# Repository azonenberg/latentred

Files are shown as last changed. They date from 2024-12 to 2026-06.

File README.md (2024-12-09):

# latentred
Open hardware 48x 1000baseT + 2x 25G SFP28 Ethernet switch

Originally located in azonenberg/latentpacket but moved out to avoid monorepo bloat.

High level architecture:
* IBC (x1): 48V -> 12V intermediate bus converter. Not in this repo, see https://github.com/azonenberg/common-ibc
* Line card (x2): 24 10/100/1000 baseT ports, driven by two VSC8512 12-port PHYs
* Switch engine (x1): Kintex UltraScale+ FPGA (XCKU3P or 5P in FFVB676), STM32H735 (tentatively), packet buffer SRAM, 2x 25G SFP28 uplink

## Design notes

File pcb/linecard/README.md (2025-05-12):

# 24-port non-PoE 10/100/1000baseT QSGMII line card

Input: 12V at 1.25A max, fused at 3A to be conservative.

Expect ~15W max power consumption, less under typical operation

## ERRATA

v0.1: right LED on the RJ45 is swapped between upper and lower ports

## Power

### Needs

* VDD (1.0V): 1.15A per PHY, 2.3A total
* VDD_A (1.0V): 180 mA per PHY, 360 mA total
* VDD_AH (2.5V): 1.37A per PHY, 2.74A total
* VDD_AL (1.0V): 190 mA per PHY, 380 total
* VDD_IO (2.5V): 60 mA per PHY, 120 mA total
* VDD_VS (1.0V): 90 mA per PHY, 180 mA total
* Plus a 3.3V standby rail for the management MCU

## I2C address map

* 0x80: INA230 on 3V3
* 0x82: INA230 on 2V5
* 0x84: INA230 on 1V0
* 0x86: INA230 on 1V0_2
* 0x90: AT30TS74 near PHY 0
* 0x92: AT30ST74 near PHY 1
* 0x94: AT30TS74 near power supply

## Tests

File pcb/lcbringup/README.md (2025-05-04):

# lcbringup

This is a bringup test fixture for validating the line card (in conjunction with my kup-lulz XCKU5P FPGA board) and not intended to be part of the final LATENTED system.

Known errata: MDIO and MDC are on ball locations that are NC in the 7a35t FGG484 package. Reworked board connecting MDIO to the SPI pins on the adjacent bank and added external level shifters.

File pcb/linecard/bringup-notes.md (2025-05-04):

# Line card bringup notes

Going well so far

Port 23 does not seem to be linking up, all others appear OK. Suspecting solder joint quality but haven't investigated further yet

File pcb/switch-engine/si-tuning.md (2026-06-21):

# SI TUNING STATUS

## STUFF TO DO

* Redo BGA escapes with new meander geometry
* Enlarge BGA land cutouts from 0.45 to 0.5 mm (done)
* Check if we need cutouts on lower layers with full stack modeling

## J21 (SFP28 uplinks ARF6)

* TX0: Done
* TX1: Done

* RX0: TBD
* RX1: TBD

## J22 (spare GTY)

* GTY2_TX: step1
* GTY3_TX: TBD
* GTY2_RX: TBD
* GTY3_RX: step1

## J14 (LC0_PHY0)

* LANE0_TX: step1
* LANE1_TX: step1
* LANE2_TX: step1
* LANE0_RX: TBD
* LANE1_RX: TBD
* LANE2_RX: TBD

## J15 (LC0_PHY1)

* LANE0_TX: step1
* LANE1_TX: step1
* LANE2_TX: step1
* LANE0_RX: TBD
* LANE1_RX: TBD
* LANE2_RX: TBD

## J17 (LC1_PHY0)

## J18 (LC1_PHY1)

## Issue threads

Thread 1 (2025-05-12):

Line card rev 0.1 errata: LED1 on even/odd ports are backwards

azonenberg, 2025-05-12:
When port 0 links up in 100mbit port 1's LED turns on and vice versa. Only LED1 is affected, LED0 is correct.

azonenberg, 2025-05-12:
Software workaround added in 646b6328339c5ab8a7c6ac4c9ff34f42c673b316

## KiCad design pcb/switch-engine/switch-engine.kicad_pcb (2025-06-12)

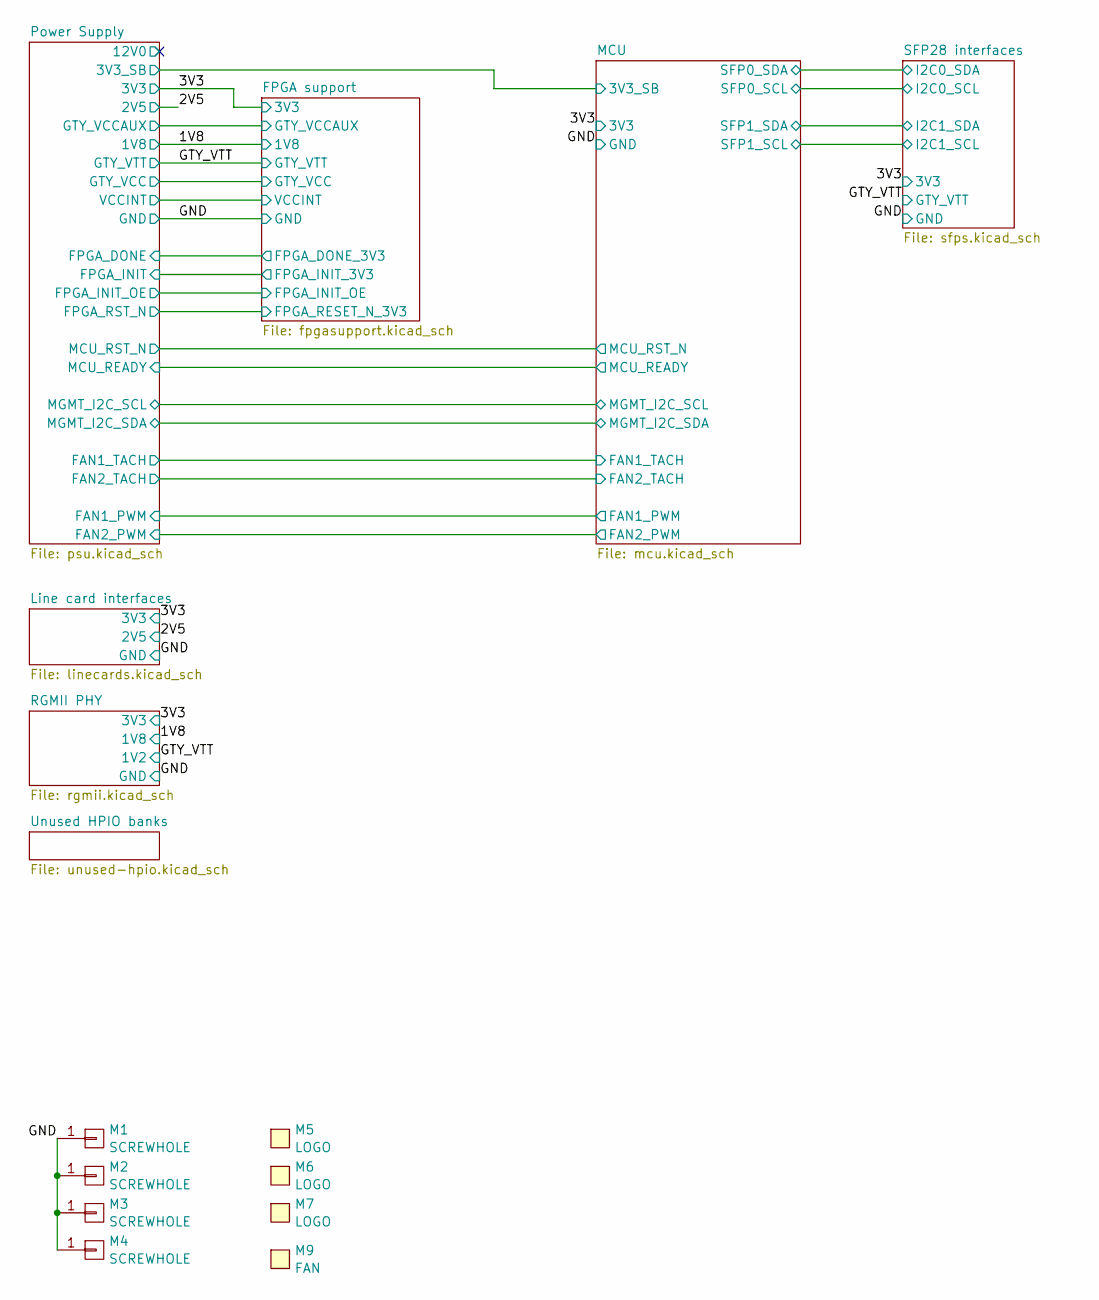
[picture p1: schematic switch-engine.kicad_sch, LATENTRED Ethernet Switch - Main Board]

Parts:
M1, M2, M3, M4: SCREWHOLE; MECHANICAL_CLEARANCEHOLE_4_40
M5: LOGO; LONGTHING-1200DPI
M6: LOGO; Logo_silk_OSHW_6x6mm
M7: LOGO; Logo_silk_WEEE_3.4x5mm
M9: FAN; FAN_DELTA_EFB0412VHD-SP05

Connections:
/GND: M1.1, M2.1, M3.1, M4.1; also elsewhere on the board

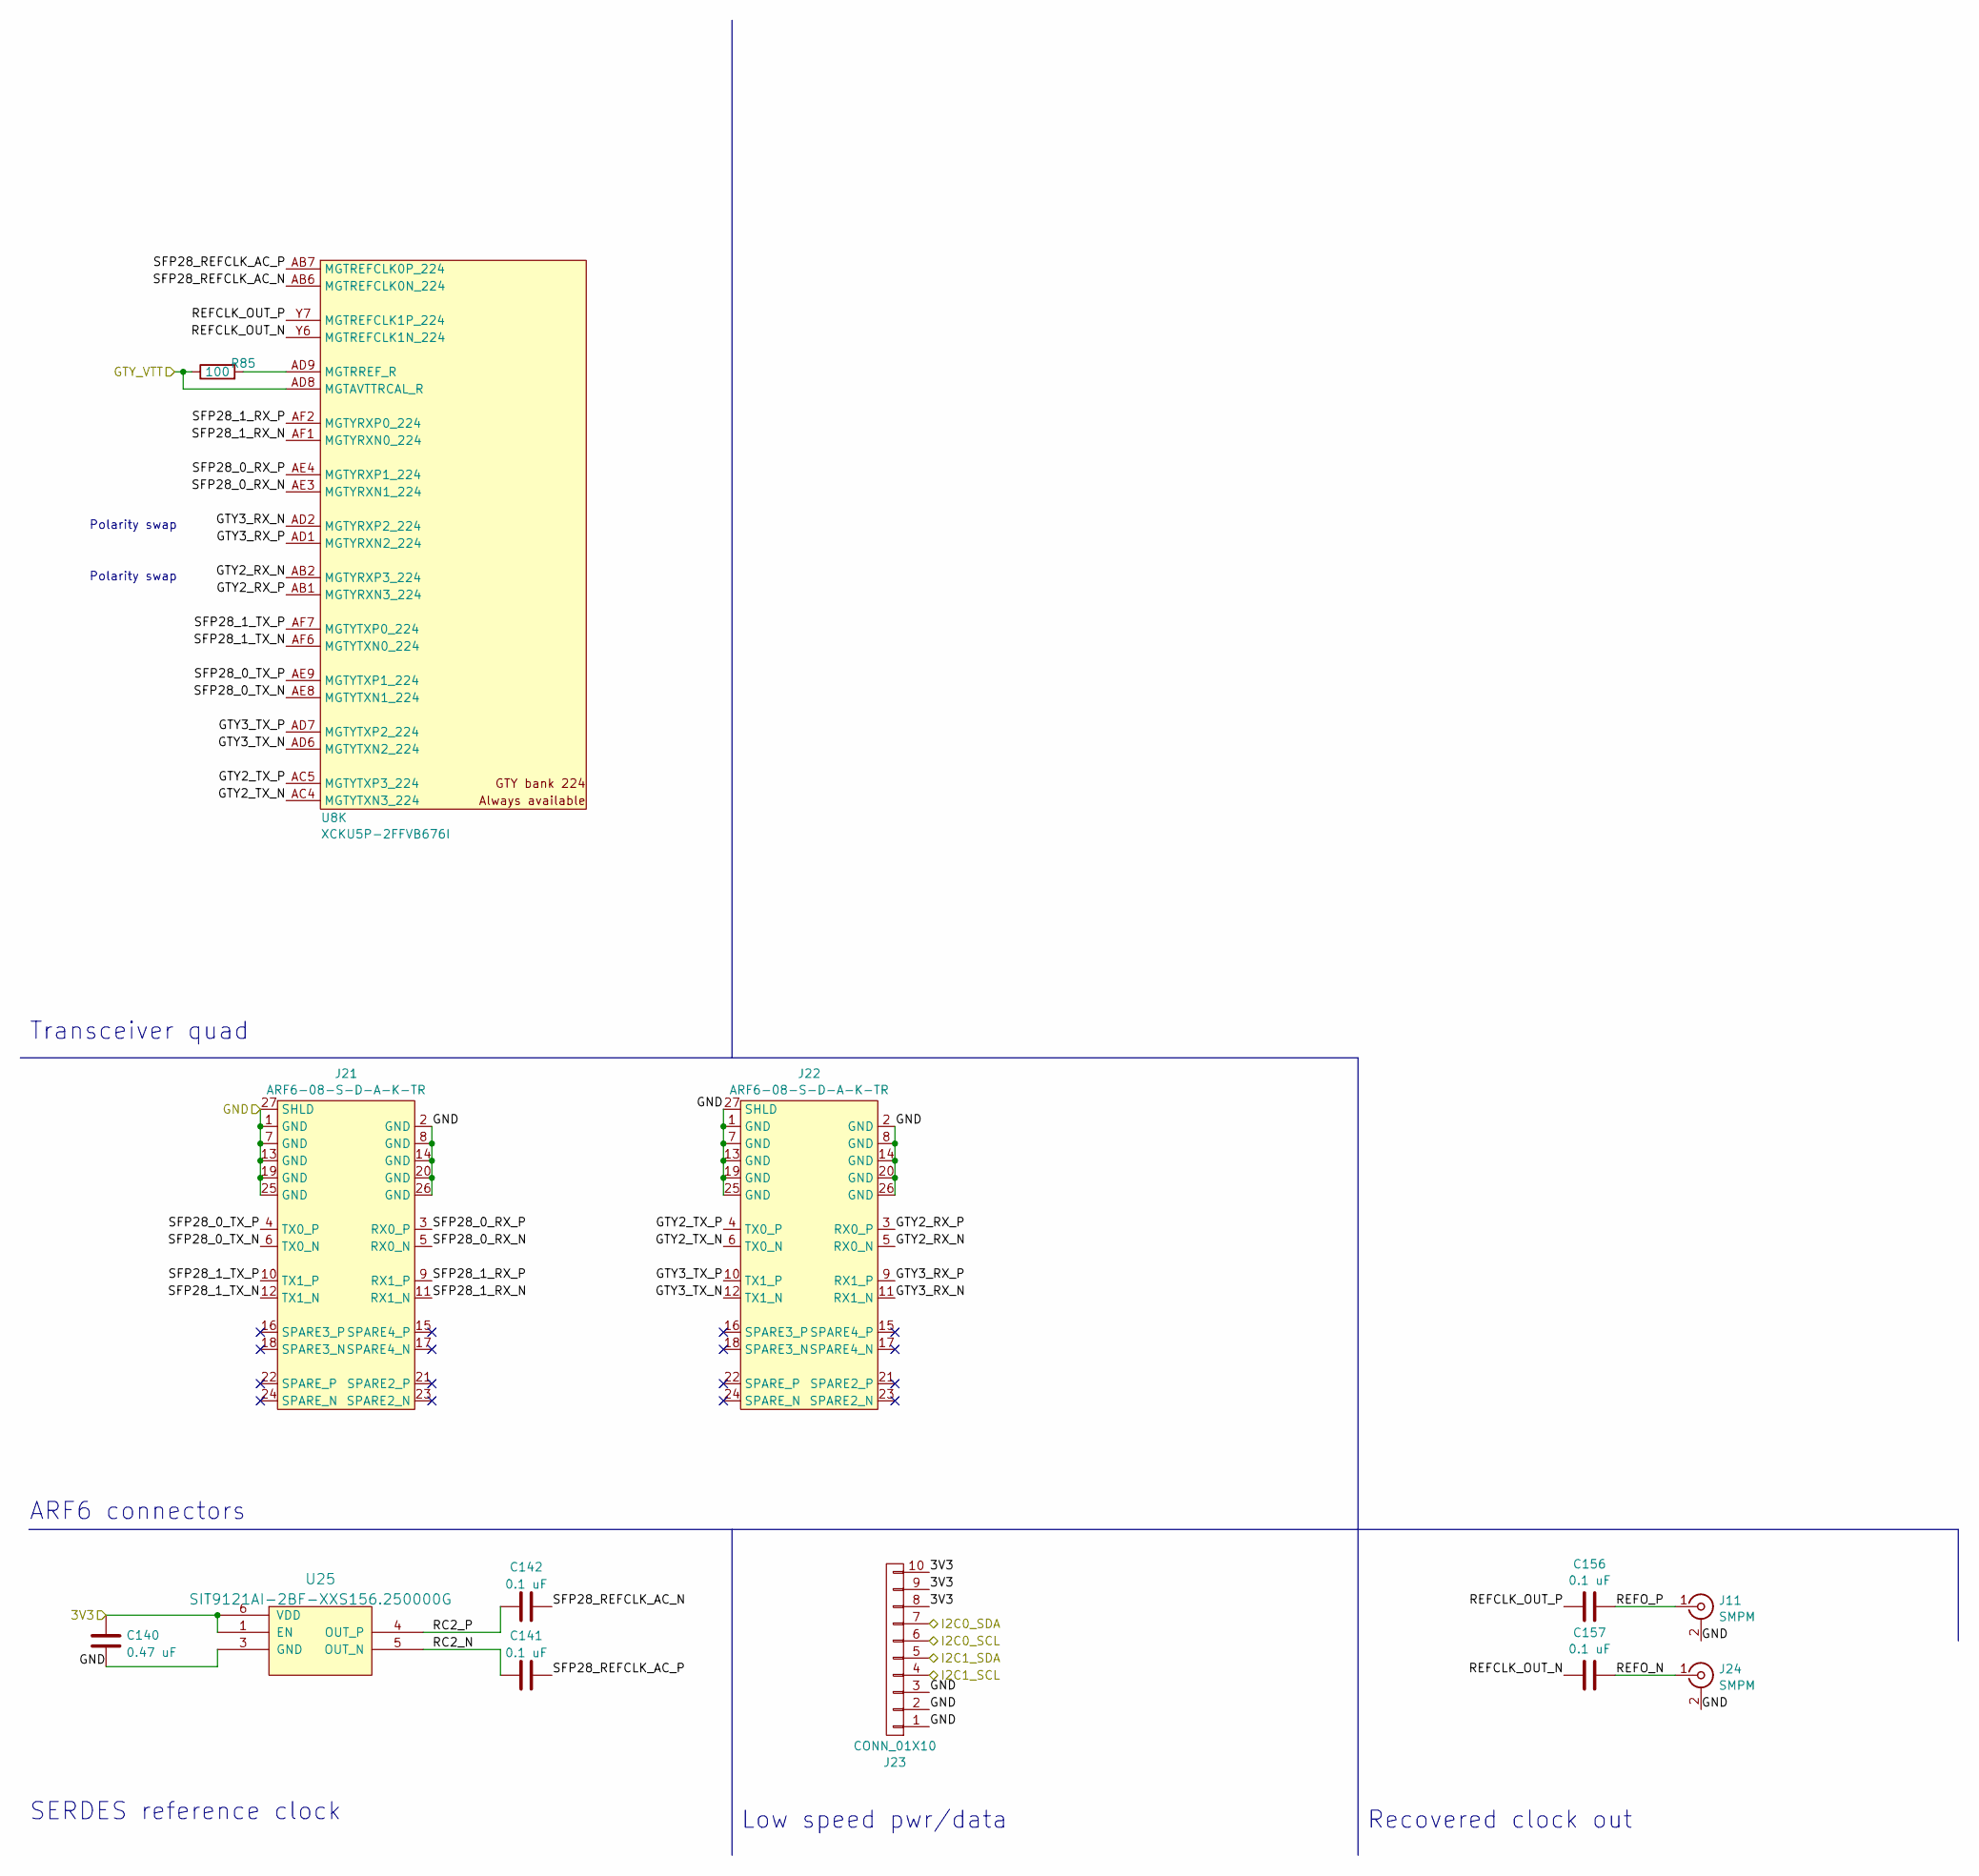
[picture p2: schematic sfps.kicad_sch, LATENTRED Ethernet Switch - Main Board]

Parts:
C140: 0.47 uF; EIA_0402_CAP_NOSILK
C141, C142, C156, C157: 0.1 uF; EIA_0402_CAP_NOSILK
J11, J24: SMPM; CONN_SMPM_AMPHENOL_C925-197J-51PT
J21, J22: ARF6-08-S-D-A-K-TR; CONN_SAMTEC_ARF6-08-S-D-A-K-TR
J23: CONN_01X10; CONN_MOLEX_PICOBLADE_10POS_0532611071
R85: 100; EIA_0402_RES_NOSILK
U8: XCKU5P-2FFVB676I; BGA_676_27x27_FULLARRAY_1MM_FFG676
U25: SIT9121AI-2BF-XXS156.250000G; OSCILLATOR_LVDS_3.2x2.5

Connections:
/3V3: C140.1, J23.8, J23.9, J23.10, U25.1 (EN), U25.6 (VDD); also elsewhere on the board
/GND: C140.2, J11.2 (Ext), J21.1 (GND), J21.2 (GND), J21.7 (GND), J21.8 (GND), J21.13 (GND), J21.14 (GND), J21.19 (GND), J21.20 (GND), J21.25 (GND), J21.26 (GND), J21.27 (SHLD), J22.1 (GND), J22.2 (GND), J22.7 (GND), J22.8 (GND), J22.13 (GND), J22.14 (GND), J22.19 (GND), J22.20 (GND), J22.25 (GND), J22.26 (GND), J22.27 (SHLD), J23.1, J23.2, J23.3, J24.2 (Ext), U25.3 (GND); also elsewhere on the board
/GTY_VTT: R85.1, U8.AD8 (MGTAVTTRCAL_R); also elsewhere on the board
/MCU/SFP0_SCL: J23.6; also elsewhere on the board
/MCU/SFP0_SDA: J23.7; also elsewhere on the board
/MCU/SFP1_SCL: J23.4; also elsewhere on the board
/MCU/SFP1_SDA: J23.5; also elsewhere on the board
/SFP28 interfaces/GTY2_RX_N: J22.5 (RX0_N), U8.AB2 (MGTYRXP3_224)
/SFP28 interfaces/GTY2_RX_P: J22.3 (RX0_P), U8.AB1 (MGTYRXN3_224)
/SFP28 interfaces/GTY2_TX_N: J22.6 (TX0_N), U8.AC4 (MGTYTXN3_224)
/SFP28 interfaces/GTY2_TX_P: J22.4 (TX0_P), U8.AC5 (MGTYTXP3_224)
/SFP28 interfaces/GTY3_RX_N: J22.11 (RX1_N), U8.AD2 (MGTYRXP2_224)
/SFP28 interfaces/GTY3_RX_P: J22.9 (RX1_P), U8.AD1 (MGTYRXN2_224)
/SFP28 interfaces/GTY3_TX_N: J22.12 (TX1_N), U8.AD6 (MGTYTXN2_224)
/SFP28 interfaces/GTY3_TX_P: J22.10 (TX1_P), U8.AD7 (MGTYTXP2_224)
/SFP28 interfaces/RC2_N: C141.1, U25.5 (OUT_N)
/SFP28 interfaces/RC2_P: C142.1, U25.4 (OUT_P)
/SFP28 interfaces/REFCLK_OUT_N: C157.1, U8.Y6 (MGTREFCLK1N_224)
/SFP28 interfaces/REFCLK_OUT_P: C156.1, U8.Y7 (MGTREFCLK1P_224)
/SFP28 interfaces/REFO_N: C157.2, J24.1 (In)
/SFP28 interfaces/REFO_P: C156.2, J11.1 (In)
/SFP28 interfaces/SFP28_0_RX_N: J21.5 (RX0_N), U8.AE3 (MGTYRXN1_224)
/SFP28 interfaces/SFP28_0_RX_P: J21.3 (RX0_P), U8.AE4 (MGTYRXP1_224)
/SFP28 interfaces/SFP28_0_TX_N: J21.6 (TX0_N), U8.AE8 (MGTYTXN1_224)
/SFP28 interfaces/SFP28_0_TX_P: J21.4 (TX0_P), U8.AE9 (MGTYTXP1_224)
/SFP28 interfaces/SFP28_1_RX_N: J21.11 (RX1_N), U8.AF1 (MGTYRXN0_224)
/SFP28 interfaces/SFP28_1_RX_P: J21.9 (RX1_P), U8.AF2 (MGTYRXP0_224)
/SFP28 interfaces/SFP28_1_TX_N: J21.12 (TX1_N), U8.AF6 (MGTYTXN0_224)
/SFP28 interfaces/SFP28_1_TX_P: J21.10 (TX1_P), U8.AF7 (MGTYTXP0_224)
/SFP28 interfaces/SFP28_REFCLK_AC_N: C142.2, U8.AB6 (MGTREFCLK0N_224)
/SFP28 interfaces/SFP28_REFCLK_AC_P: C141.2, U8.AB7 (MGTREFCLK0P_224)
unnamed: R85.2, U8.AD9 (MGTRREF_R)

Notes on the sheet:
Transceiver quad
Low speed pwr/data
Polarity swap
Recovered clock out
ARF6 connectors
SERDES reference clock

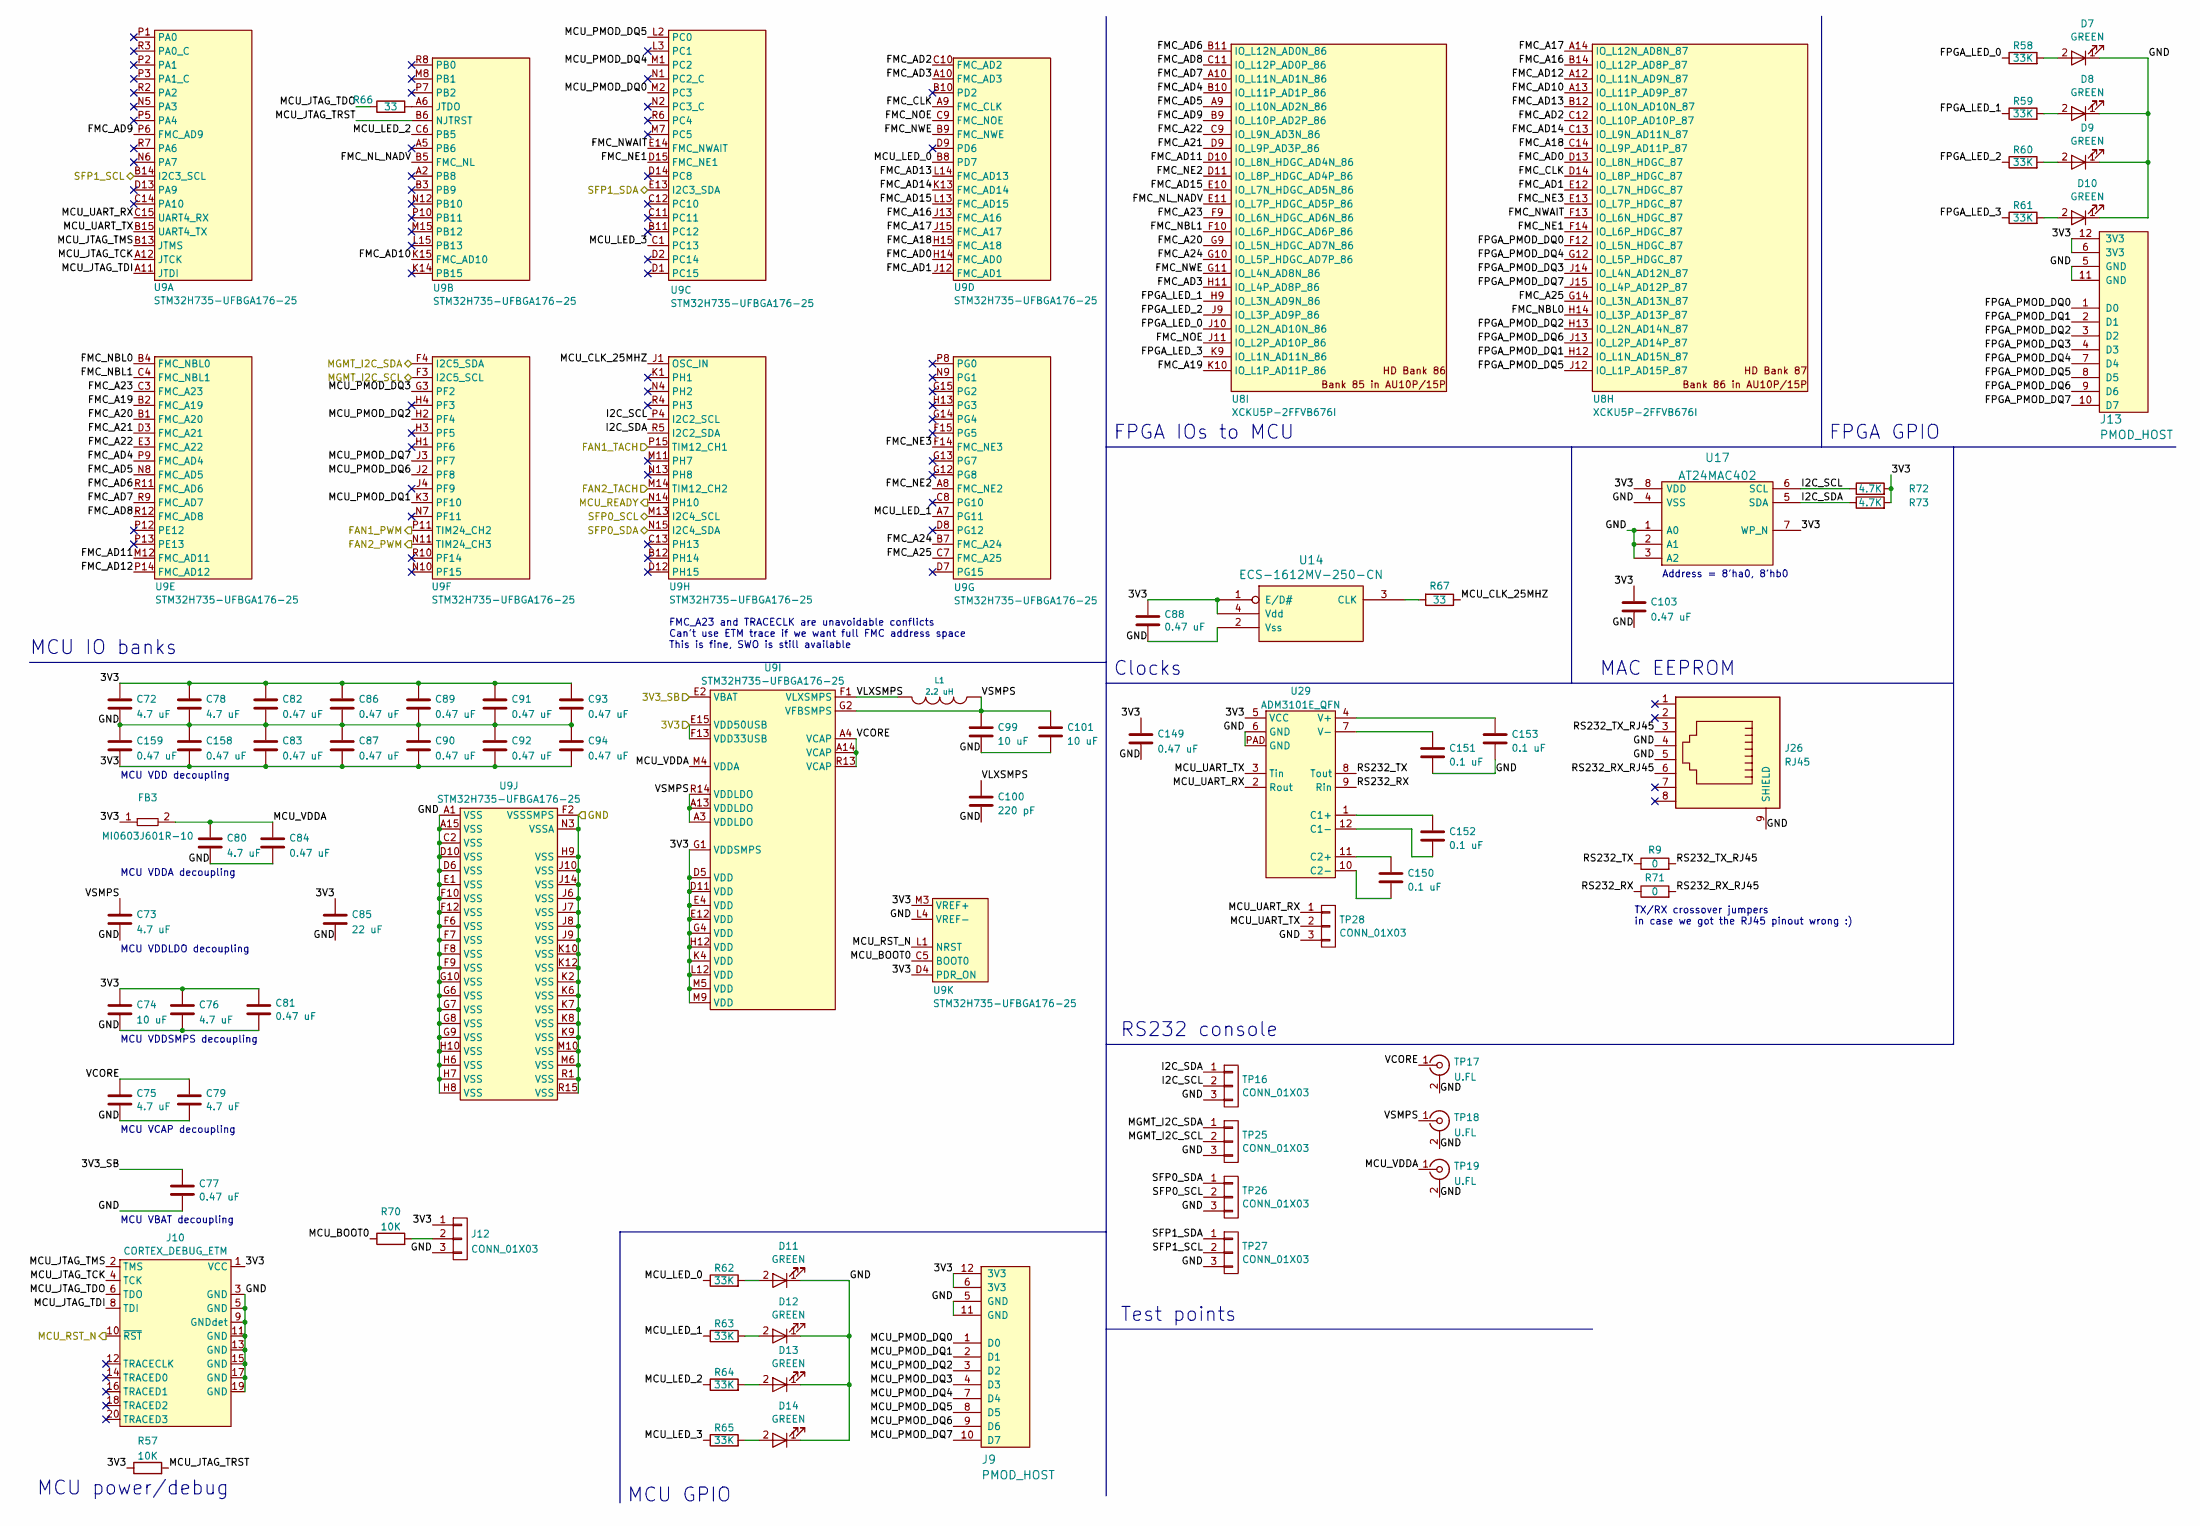
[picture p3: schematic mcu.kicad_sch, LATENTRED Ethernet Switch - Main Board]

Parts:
C72, C73, C75, C76, C78, C79, C80: 4.7 uF; EIA_0603_CAP_NOSILK
C74, C99, C101: 10 uF; EIA_0805_CAP_NOSILK
C77, C82, C83, C84, C86, C89, C90, C92, C93, C94: 0.47 uF; EIA_0201_CAP_NOSILK
C81, C87, C88, C91, C103, C149, C158, C159: 0.47 uF; EIA_0402_CAP_NOSILK
C85: 22 uF; EIA_0805_CAP_NOSILK
C100: 220 pF; EIA_0402_CAP_NOSILK
C150, C151, C152, C153: 0.1 uF; EIA_0402_CAP_NOSILK
D7, D8, D9, D10, D11, D12, D13, D14: GREEN; EIA_0402_LED
FB3: MI0603J601R-10; EIA_0603_INDUCTOR_NOSILK
J9, J13: PMOD_HOST; CONN_HEADER_2.54MM_2x6_RA_PMOD_HOST
J10: CORTEX_DEBUG_ETM; CONN_HEADER_1.27MM_2x10_SMT_SAMTEC_FTSH-110-01-L-DV-K
J12: CONN_01X03; CONN_HEADER_2.54MM_1x3
J26: RJ45; CONN_RJ45_BELSTEWART_SS-7188S-A-PG4-1-BA-xx
L1: 2.2 uH; EIA_1210_CAP_NOSILK
R9, R71: 0; EIA_0402_RES_NOSILK
R57, R70: 10K; EIA_0402_RES_NOSILK
R58, R59, R60, R61, R62, R63, R64, R65: 33K; EIA_0402_RES_NOSILK
R66, R67: 33; EIA_0402_RES_NOSILK
R72, R73: 4.7K; EIA_0402_RES_NOSILK
TP16, TP25, TP26, TP27, TP28: CONN_01X03; CONN_HEADER_2.54MM_1x3
TP17, TP18, TP19: U.FL; CONN_U.FL_TE_1909763-1
U8: XCKU5P-2FFVB676I; BGA_676_27x27_FULLARRAY_1MM_FFG676
U9: STM32H735-UFBGA176-25; BGA_201_10x10_DEPOP_0.65MM_OSHPARK
U14: ECS-1612MV-250-CN; OSCILLATOR_1.6x1.2
U17: AT24MAC402; DFN_8_0.5MM_2x3MM_TALL
U29: ADM3101E_QFN; QFN_12_0.5MM_3x3MM

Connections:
/3V3: C72.1, C74.1, C76.1, C78.1, C81.1, C82.1, C83.2, C85.1, C86.1, C87.2, C88.1, C89.1, C90.2, C91.1, C92.2, C93.1, C94.2, C103.1, C149.1, C158.2, C159.2, FB3.1, J9.6 (3V3), J9.12 (3V3), J10.1 (VCC), J12.1, J13.6 (3V3), J13.12 (3V3), R57.1, R72.2, R73.2, U9.D4 (PDR_ON), U9.D5 (VDD), U9.D11 (VDD), U9.E4 (VDD), U9.E12 (VDD), U9.E15 (VDD50USB), U9.F13 (VDD33USB), U9.G1 (VDDSMPS), U9.G4 (VDD), U9.H12 (VDD), U9.K4 (VDD), U9.L12 (VDD), U9.M3 (VREF+), U9.M5 (VDD), U9.M9 (VDD), U14.1 (E/D#), U14.4 (Vdd), U17.7 (WP_N), U17.8 (VDD), U29.5 (VCC); also elsewhere on the board
/GND: C72.2, C73.2, C74.2, C75.2, C76.2, C77.2, C78.2, C79.2, C80.2, C81.2, C82.2, C83.1, C84.2, C85.2, C86.2, C87.1, C88.2, C89.2, C90.1, C91.2, C92.1, C93.2, C94.1, C99.2, C100.2, C101.2, C103.2, C149.2, C151.2, C153.2, C158.1, C159.1, D7.1 (K), D8.1 (K), D9.1 (K), D10.1 (K), D11.1 (K), D12.1 (K), D13.1 (K), D14.1 (K), J9.5 (GND), J9.11 (GND), J10.3 (GND), J10.5 (GND), J10.9 (GNDdet), J10.11 (GND), J10.13 (GND), J10.15 (GND), J10.17 (GND), J10.19 (GND), J12.3, J13.5 (GND), J13.11 (GND), J26.4, J26.5, J26.9 (SHIELD), TP16.3, TP17.2 (Ext), TP18.2 (Ext), TP19.2 (Ext), TP25.3, TP26.3, TP27.3, TP28.3, U9.A1 (VSS), U9.A15 (VSS), U9.C2 (VSS), U9.D6 (VSS), U9.D10 (VSS), U9.E1 (VSS), U9.F2 (VSSSMPS), U9.F6 (VSS), U9.F7 (VSS), U9.F8 (VSS), U9.F9 (VSS), U9.F10 (VSS), U9.F12 (VSS), U9.G6 (VSS), U9.G7 (VSS), U9.G8 (VSS), U9.G9 (VSS), U9.G10 (VSS), U9.H6 (VSS), U9.H7 (VSS), U9.H8 (VSS), U9.H9 (VSS), U9.H10 (VSS), U9.J6 (VSS), U9.J7 (VSS), U9.J8 (VSS), U9.J9 (VSS), U9.J10 (VSS), U9.J14 (VSS), U9.K2 (VSS), U9.K6 (VSS), U9.K7 (VSS), U9.K8 (VSS), U9.K9 (VSS), U9.K10 (VSS), U9.K12 (VSS), U9.L4 (VREF-), U9.M6 (VSS), U9.M10 (VSS), U9.N3 (VSSA), U9.R1 (VSS), U9.R15 (VSS), U14.2 (Vss), U17.1 (A0), U17.2 (A1), U17.3 (A2), U17.4 (VSS), U29.6 (GND), U29.PAD (GND); also elsewhere on the board
/MCU/3V3_SB: C77.1, U9.E2 (VBAT); also elsewhere on the board
/MCU/FMC_A16: U8.B14 (IO_L12P_AD8P_87), U9.J13 (FMC_A16)
/MCU/FMC_A17: U8.A14 (IO_L12N_AD8N_87), U9.J15 (FMC_A17)
/MCU/FMC_A18: U8.C14 (IO_L9P_AD11P_87), U9.H15 (FMC_A18)
/MCU/FMC_A19: U8.K10 (IO_L1P_AD11P_86), U9.B2 (FMC_A19)
/MCU/FMC_A20: U8.G9 (IO_L5N_HDGC_AD7N_86), U9.B1 (FMC_A20)
/MCU/FMC_A21: U8.D9 (IO_L9P_AD3P_86), U9.D3 (FMC_A21)
/MCU/FMC_A22: U8.C9 (IO_L9N_AD3N_86), U9.E3 (FMC_A22)
/MCU/FMC_A23: U8.F9 (IO_L6N_HDGC_AD6N_86), U9.C3 (FMC_A23)
/MCU/FMC_A24: U8.G10 (IO_L5P_HDGC_AD7P_86), U9.B7 (FMC_A24)
/MCU/FMC_A25: U8.G14 (IO_L3N_AD13N_87), U9.C7 (FMC_A25)
/MCU/FMC_AD0: U8.D13 (IO_L8N_HDGC_87), U9.H14 (FMC_AD0)
/MCU/FMC_AD1: U8.E12 (IO_L7N_HDGC_87), U9.J12 (FMC_AD1)
/MCU/FMC_AD2: U8.C12 (IO_L10P_AD10P_87), U9.C10 (FMC_AD2)
/MCU/FMC_AD3: U8.H11 (IO_L4P_AD8P_86), U9.A10 (FMC_AD3)
/MCU/FMC_AD4: U8.B10 (IO_L11P_AD1P_86), U9.P9 (FMC_AD4)
/MCU/FMC_AD5: U8.A9 (IO_L10N_AD2N_86), U9.N8 (FMC_AD5)
/MCU/FMC_AD6: U8.B11 (IO_L12N_AD0N_86), U9.R11 (FMC_AD6)
/MCU/FMC_AD7: U8.A10 (IO_L11N_AD1N_86), U9.R9 (FMC_AD7)
/MCU/FMC_AD8: U8.C11 (IO_L12P_AD0P_86), U9.R12 (FMC_AD8)
/MCU/FMC_AD9: U8.B9 (IO_L10P_AD2P_86), U9.P6 (FMC_AD9)
/MCU/FMC_AD10: U8.A13 (IO_L11P_AD9P_87), U9.K15 (FMC_AD10)
/MCU/FMC_AD11: U8.D10 (IO_L8N_HDGC_AD4N_86), U9.M12 (FMC_AD11)
/MCU/FMC_AD12: U8.A12 (IO_L11N_AD9N_87), U9.P14 (FMC_AD12)
/MCU/FMC_AD13: U8.B12 (IO_L10N_AD10N_87), U9.L14 (FMC_AD13)
/MCU/FMC_AD14: U8.C13 (IO_L9N_AD11N_87), U9.K13 (FMC_AD14)
/MCU/FMC_AD15: U8.E10 (IO_L7N_HDGC_AD5N_86), U9.L13 (FMC_AD15)
/MCU/FMC_CLK: U8.D14 (IO_L8P_HDGC_87), U9.A9 (FMC_CLK)
/MCU/FMC_NBL0: U8.H14 (IO_L3P_AD13P_87), U9.B4 (FMC_NBL0)
/MCU/FMC_NBL1: U8.F10 (IO_L6P_HDGC_AD6P_86), U9.C4 (FMC_NBL1)
/MCU/FMC_NE1: U8.F14 (IO_L6P_HDGC_87), U9.D15 (FMC_NE1)
/MCU/FMC_NE2: U8.D11 (IO_L8P_HDGC_AD4P_86), U9.A8 (FMC_NE2)
/MCU/FMC_NE3: U8.E13 (IO_L7P_HDGC_87), U9.F14 (FMC_NE3)
/MCU/FMC_NL_NADV: U8.E11 (IO_L7P_HDGC_AD5P_86), U9.B5 (FMC_NL)
/MCU/FMC_NOE: U8.J11 (IO_L2P_AD10P_86), U9.C9 (FMC_NOE)
/MCU/FMC_NWAIT: U8.F13 (IO_L6N_HDGC_87), U9.E14 (FMC_NWAIT)
/MCU/FMC_NWE: U8.G11 (IO_L4N_AD8N_86), U9.B9 (FMC_NWE)
/MCU/FPGA_LED_0: R58.1, U8.J10 (IO_L2N_AD10N_86)
/MCU/FPGA_LED_1: R59.1, U8.H9 (IO_L3N_AD9N_86)
/MCU/FPGA_LED_2: R60.1, U8.J9 (IO_L3P_AD9P_86)
/MCU/FPGA_LED_3: R61.1, U8.K9 (IO_L1N_AD11N_86)
/MCU/FPGA_PMOD_DQ0: J13.1 (D0), U8.F12 (IO_L5N_HDGC_87)
/MCU/FPGA_PMOD_DQ1: J13.2 (D1), U8.H12 (IO_L1N_AD15N_87)
/MCU/FPGA_PMOD_DQ2: J13.3 (D2), U8.H13 (IO_L2N_AD14N_87)
/MCU/FPGA_PMOD_DQ3: J13.4 (D3), U8.J14 (IO_L4N_AD12N_87)
/MCU/FPGA_PMOD_DQ4: J13.7 (D4), U8.G12 (IO_L5P_HDGC_87)
/MCU/FPGA_PMOD_DQ5: J13.8 (D5), U8.J12 (IO_L1P_AD15P_87)
/MCU/FPGA_PMOD_DQ6: J13.9 (D6), U8.J13 (IO_L2P_AD14P_87)
/MCU/FPGA_PMOD_DQ7: J13.10 (D7), U8.J15 (IO_L4P_AD12P_87)
/MCU/I2C_SCL: R72.1, TP16.2, U9.P4 (I2C2_SCL), U17.6 (SCL)
/MCU/I2C_SDA: R73.1, TP16.1, U9.R5 (I2C2_SDA), U17.5 (SDA)
/MCU/MCU_BOOT0: R70.1, U9.C5 (BOOT0)
/MCU/MCU_CLK_25MHZ: R67.1, U9.J1 (OSC_IN)
/MCU/MCU_JTAG_TCK: J10.4 (TCK), U9.A12 (JTCK)
/MCU/MCU_JTAG_TDI: J10.8 (TDI), U9.A11 (JTDI)
/MCU/MCU_JTAG_TDO: J10.6 (TDO), R66.1
/MCU/MCU_JTAG_TMS: J10.2 (TMS), U9.B13 (JTMS)
/MCU/MCU_JTAG_TRST: R57.2, U9.B6 (NJTRST)
/MCU/MCU_LED_0: R62.1, U9.B8 (PD7)
/MCU/MCU_LED_1: R63.1, U9.A7 (PG11)
/MCU/MCU_LED_2: R64.1, U9.C6 (PB5)
/MCU/MCU_LED_3: R65.1, U9.C1 (PC13)
/MCU/MCU_PMOD_DQ0: J9.1 (D0), U9.M2 (PC3)
/MCU/MCU_PMOD_DQ1: J9.2 (D1), U9.K3 (PF10)
/MCU/MCU_PMOD_DQ2: J9.3 (D2), U9.H2 (PF4)
/MCU/MCU_PMOD_DQ3: J9.4 (D3), U9.G3 (PF2)
/MCU/MCU_PMOD_DQ4: J9.7 (D4), U9.M1 (PC2)
/MCU/MCU_PMOD_DQ5: J9.8 (D5), U9.L2 (PC0)
/MCU/MCU_PMOD_DQ6: J9.9 (D6), U9.J2 (PF8)
/MCU/MCU_PMOD_DQ7: J9.10 (D7), U9.J3 (PF7)
/MCU/MCU_READY: U9.N14 (PH10); also elsewhere on the board
/MCU/MCU_RST_N: J10.10 (~RST), U9.L1 (NRST); also elsewhere on the board
/MCU/MCU_UART_RX: TP28.1, U9.C15 (UART4_RX), U29.2 (Rout)
/MCU/MCU_UART_TX: TP28.2, U9.B15 (UART4_TX), U29.3 (Tin)
/MCU/MCU_VDDA: C80.1, C84.1, FB3.2, TP19.1 (In), U9.M4 (VDDA)
/MCU/MGMT_I2C_SCL: TP25.2, U9.F3 (I2C5_SCL); also elsewhere on the board
/MCU/MGMT_I2C_SDA: TP25.1, U9.F4 (I2C5_SDA); also elsewhere on the board
/MCU/RS232_RX: R71.1, U29.9 (Rin)
/MCU/RS232_RX_RJ45: J26.6, R71.2
/MCU/RS232_TX: R9.1, U29.8 (Tout)
/MCU/RS232_TX_RJ45: J26.3, R9.2
/MCU/SFP0_SCL: TP26.2, U9.M13 (I2C4_SCL); also elsewhere on the board
/MCU/SFP0_SDA: TP26.1, U9.N15 (I2C4_SDA); also elsewhere on the board
/MCU/SFP1_SCL: TP27.2, U9.B14 (I2C3_SCL); also elsewhere on the board
/MCU/SFP1_SDA: TP27.1, U9.E13 (I2C3_SDA); also elsewhere on the board
/MCU/VCORE: C75.1, C79.1, TP17.1 (In), U9.A4 (VCAP), U9.A14 (VCAP), U9.R13 (VCAP)
/MCU/VLXSMPS: C100.1, L1.2, U9.F1 (VLXSMPS)
/MCU/VSMPS: C73.1, C99.1, C101.1, L1.1, TP18.1 (In), U9.A3 (VDDLDO), U9.A13 (VDDLDO), U9.G2 (VFBSMPS), U9.R14 (VDDLDO)
/Power Supply/FAN1_PWM: U9.P11 (TIM24_CH2); also elsewhere on the board
/Power Supply/FAN1_TACH: U9.P15 (TIM12_CH1); also elsewhere on the board
/Power Supply/FAN2_PWM: U9.N11 (TIM24_CH3); also elsewhere on the board
/Power Supply/FAN2_TACH: U9.M14 (TIM12_CH2); also elsewhere on the board
unnamed: D7.2 (A), R58.2
unnamed: D8.2 (A), R59.2
unnamed: D9.2 (A), R60.2
unnamed: D10.2 (A), R61.2
unnamed: D11.2 (A), R62.2
unnamed: D12.2 (A), R63.2
unnamed: D13.2 (A), R64.2
unnamed: D14.2 (A), R65.2
unnamed: J12.2, R70.2
unnamed: R66.2, U9.A6 (JTDO)
unnamed: R67.2, U14.3 (CLK)
unnamed: C152.1, U29.1 (C1+)
unnamed: C152.2, U29.12 (C1-)
unnamed: C150.1, U29.11 (C2+)
unnamed: C150.2, U29.10 (C2-)
unnamed: C153.1, U29.4 (V+)
unnamed: C151.1, U29.7 (V-)

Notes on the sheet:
RS232 console
FPGA IOs to MCU
MCU VDD decoupling
MCU VCAP decoupling
Test points
TX/RX crossover jumpers in case we got the RJ45 pinout wrong :)
FPGA GPIO
MCU VDDA decoupling
MCU GPIO
MCU VDDLDO decoupling
MCU VDDSMPS decoupling
MCU VBAT decoupling
MAC EEPROM
Address = 8'ha0, 8'hb0
FMC_A23 and TRACECLK are unavoidable conflicts Can't use ETM trace if we want full FMC address space This is fine, SWO is still available
MCU IO banks
Clocks
MCU power/debug

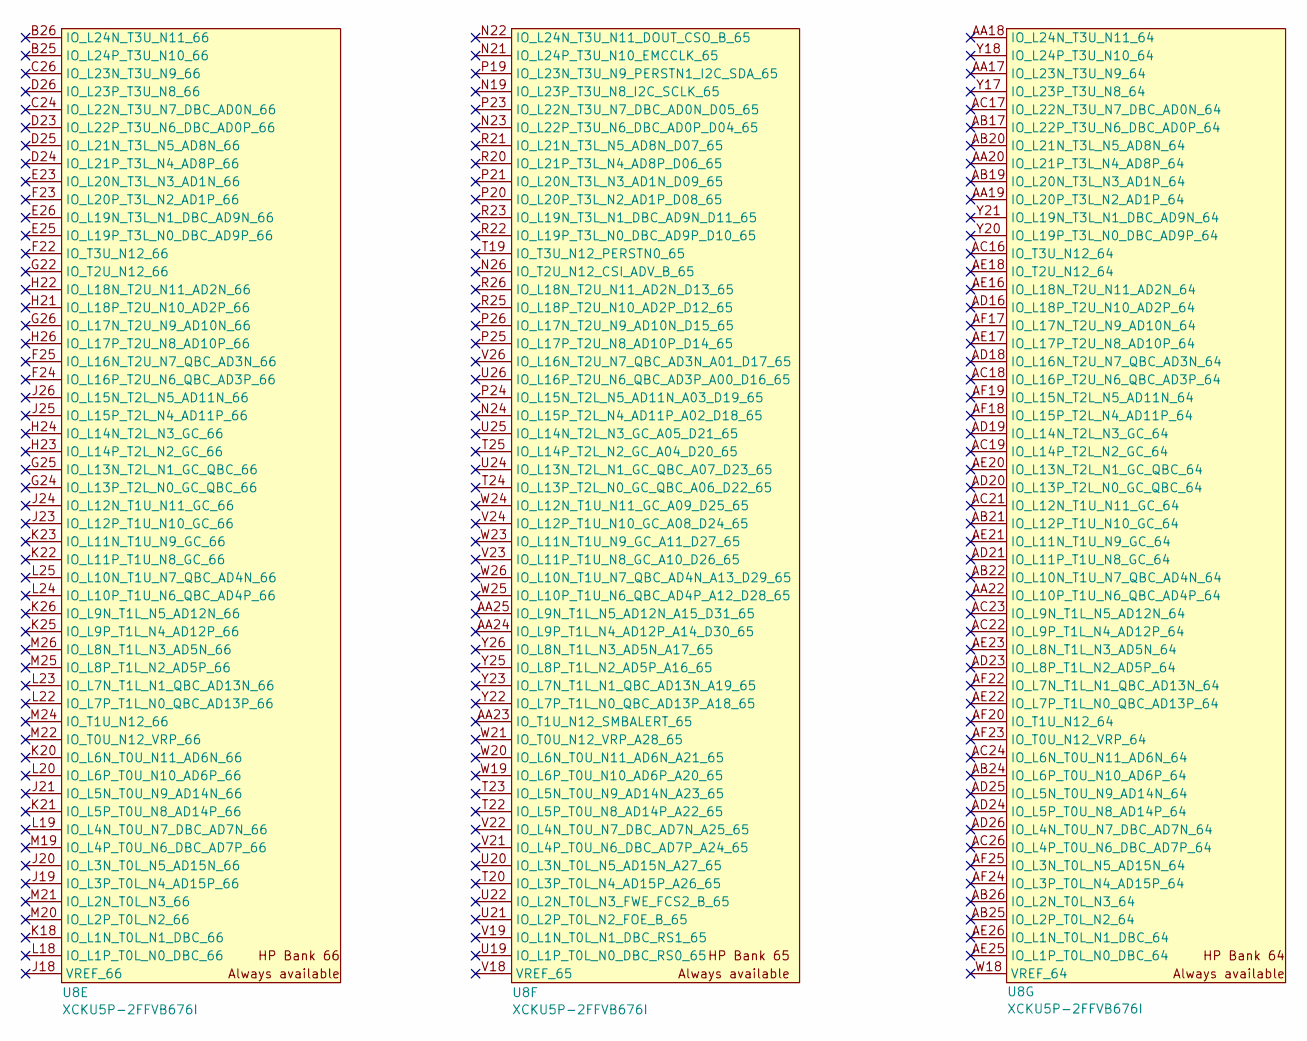
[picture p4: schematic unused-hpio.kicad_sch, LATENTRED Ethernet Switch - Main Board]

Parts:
U8: XCKU5P-2FFVB676I; BGA_676_27x27_FULLARRAY_1MM_FFG676

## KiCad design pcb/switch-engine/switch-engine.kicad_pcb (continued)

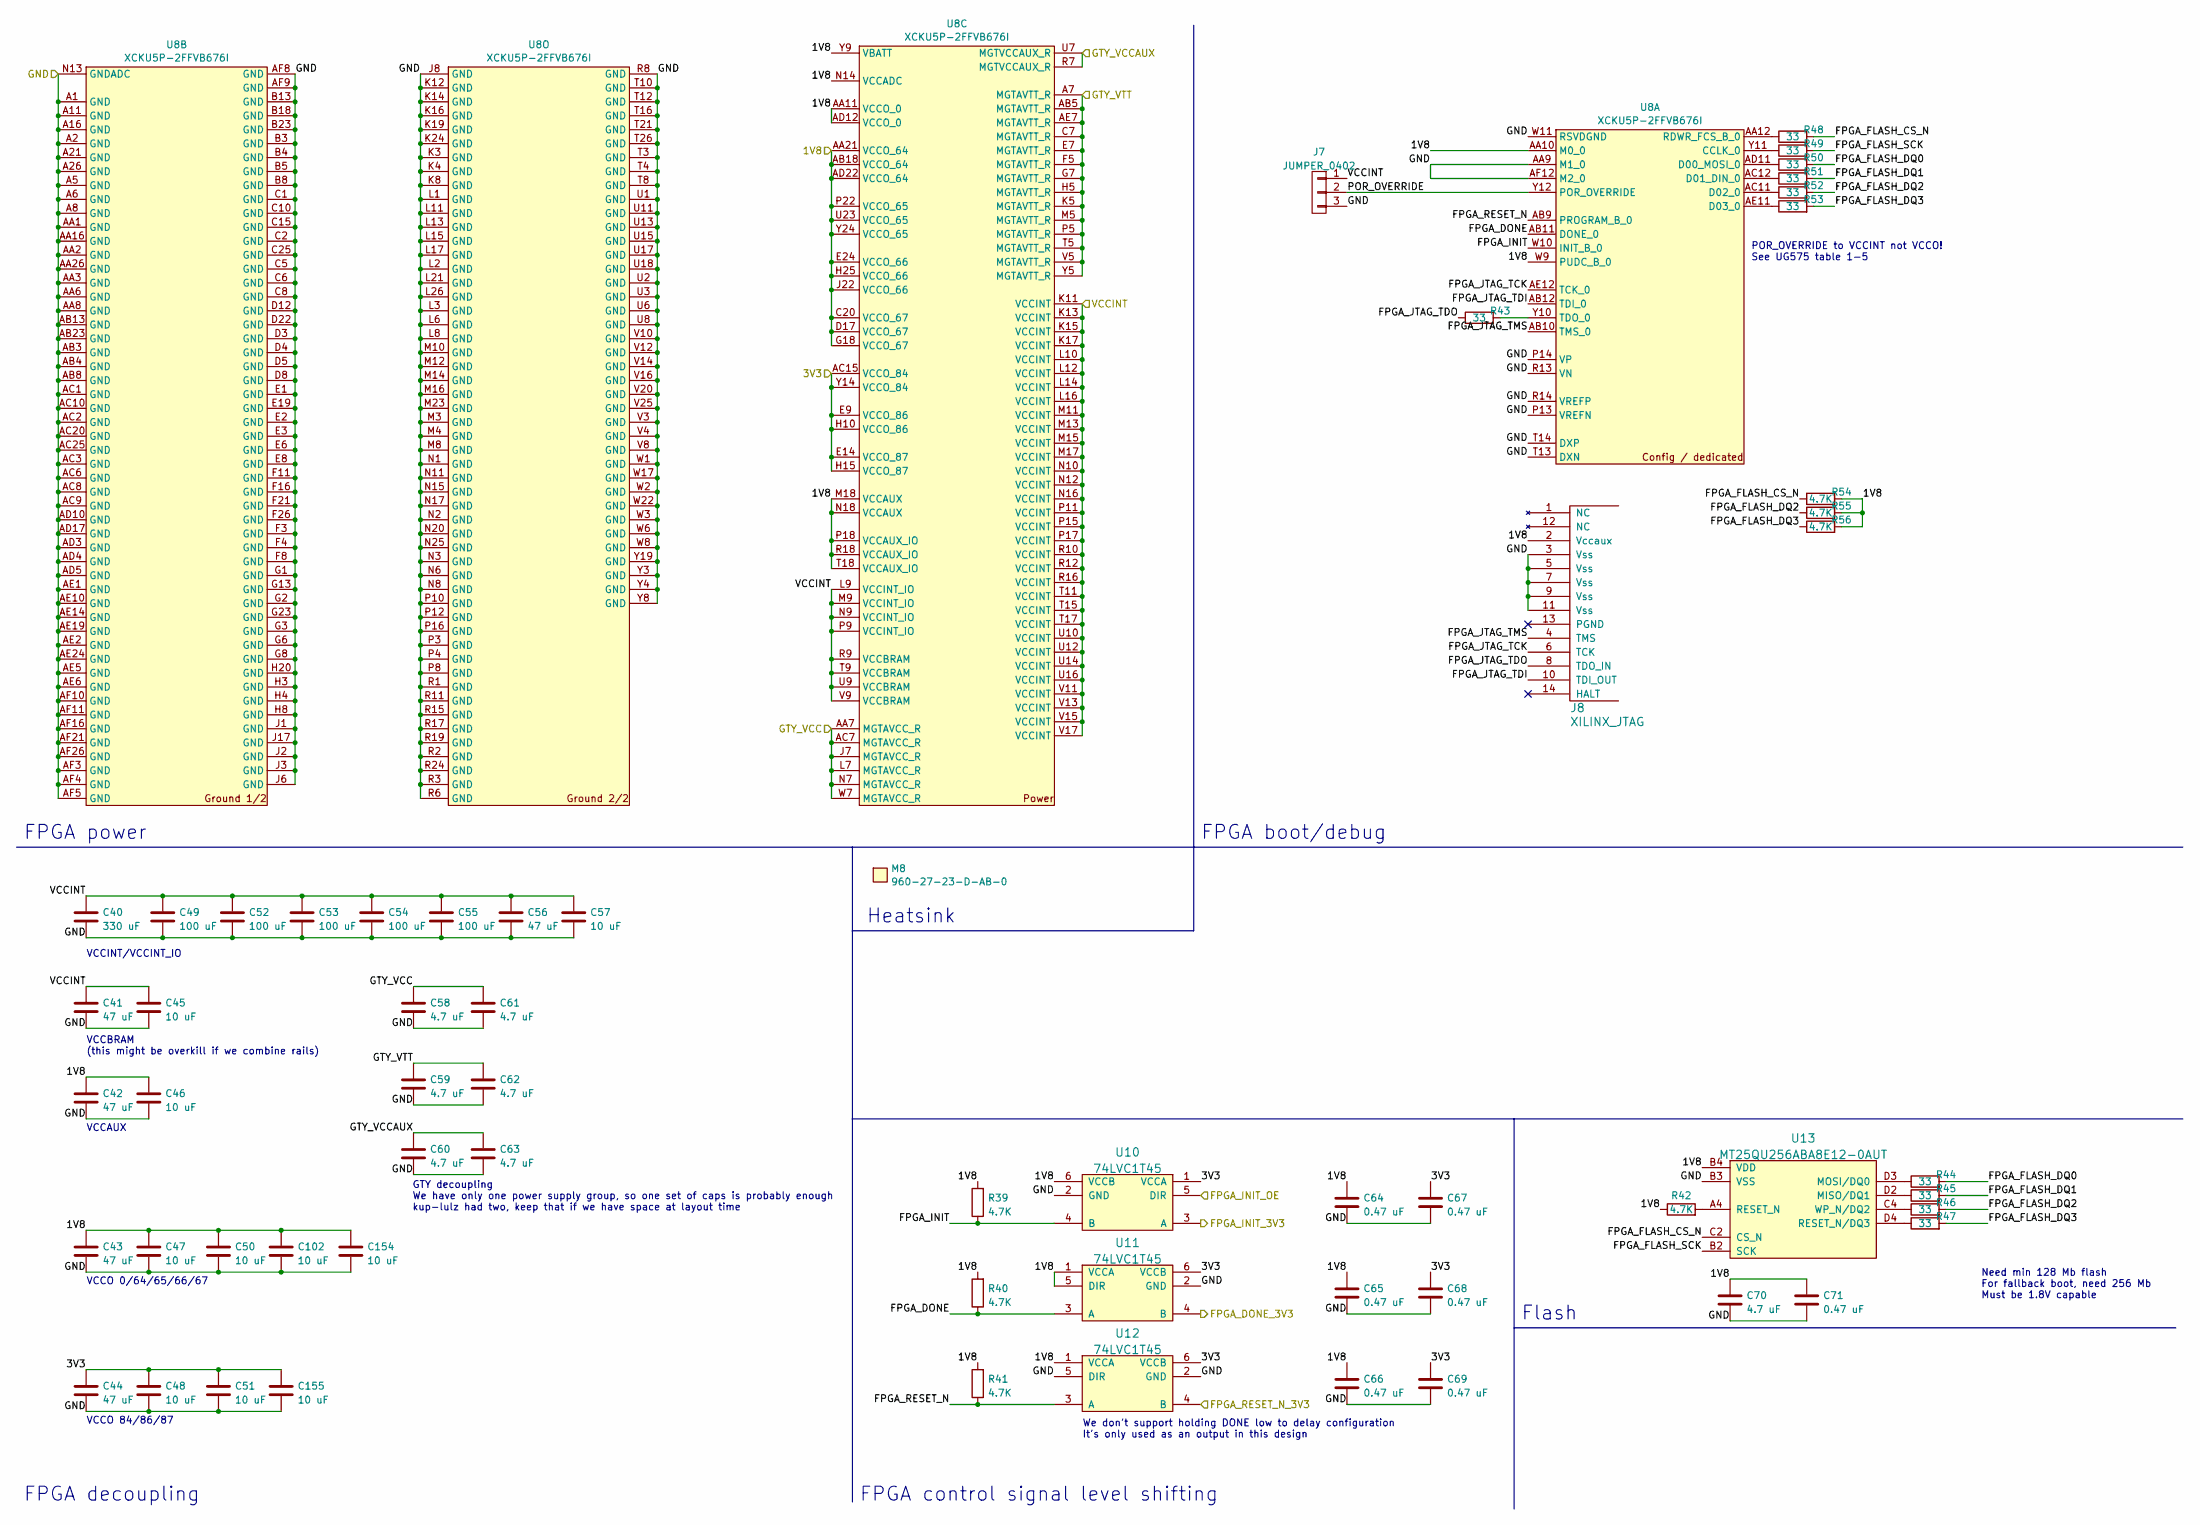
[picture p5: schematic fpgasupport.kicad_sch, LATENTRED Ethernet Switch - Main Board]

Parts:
C40: 330 uF; EIA_1210_CAP_NOSILK
C41, C42, C43, C44, C56: 47 uF; EIA_1210_CAP_NOSILK
C45, C46, C47, C48, C50, C51, C57, C102, C154, C155: 10 uF; EIA_0805_CAP_NOSILK
C49, C52, C53, C54, C55: 100 uF; EIA_1210_CAP_NOSILK
C58, C59, C60, C61, C62, C63, C70: 4.7 uF; EIA_0603_CAP_NOSILK
C64, C65, C66, C67, C68, C69, C71: 0.47 uF; EIA_0402_CAP_NOSILK
J7: JUMPER_0402; EIA_0402_JUMPER
J8: XILINX_JTAG; XILINX_JTAG_PTH_MOLEX_0878311420
M8: 960-27-23-D-AB-0; HEATSINK_WAKEFIELDVETTE_960-27-12-D-AB-0
R39, R40, R41, R42, R54, R55, R56: 4.7K; EIA_0402_RES_NOSILK
R43, R44, R45, R46, R47, R48, R49, R50, R51, R52, R53: 33; EIA_0402_RES_NOSILK
U8: XCKU5P-2FFVB676I; BGA_676_27x27_FULLARRAY_1MM_FFG676
U10, U11, U12: 74LVC1T45; DFN_6_0.5MM_1.6x1.6MM_TI_DPK
U13: MT25QU256ABA8E12-0AUT; BGA_24_6x8_DEPOP1_1MM

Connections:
/1V8: C42.1, C43.1, C46.1, C47.1, C50.1, C64.1, C65.1, C66.1, C70.1, C71.1, C102.1, C154.1, J8.2 (Vccaux), R39.2, R40.2, R41.2, R42.1, R54.2, R55.2, R56.2, U8.AA10 (M0_0), U8.AA11 (VCCO_0), U8.AA21 (VCCO_64), U8.AB18 (VCCO_64), U8.AD12 (VCCO_0), U8.AD22 (VCCO_64), U8.C20 (VCCO_67), U8.D17 (VCCO_67), U8.E24 (VCCO_66), U8.G18 (VCCO_67), U8.H25 (VCCO_66), U8.J22 (VCCO_66), U8.M18 (VCCAUX), U8.N14 (VCCADC), U8.N18 (VCCAUX), U8.P18 (VCCAUX_IO), U8.P22 (VCCO_65), U8.R18 (VCCAUX_IO), U8.T18 (VCCAUX_IO), U8.U23 (VCCO_65), U8.W9 (PUDC_B_0), U8.Y9 (VBATT), U8.Y24 (VCCO_65), U10.6 (VCCB), U11.1 (VCCA), U11.5 (DIR), U12.1 (VCCA), U13.B4 (VDD); also elsewhere on the board
/3V3: C44.1, C48.1, C51.1, C67.1, C68.1, C69.1, C155.1, U8.AC15 (VCCO_84), U8.E9 (VCCO_86), U8.E14 (VCCO_87), U8.H10 (VCCO_86), U8.H15 (VCCO_87), U8.Y14 (VCCO_84), U10.1 (VCCA), U11.6 (VCCB), U12.6 (VCCB); also elsewhere on the board
/FPGA support/FPGA_DONE: R40.1, U8.AB11 (DONE_0), U11.3 (A)
/FPGA support/FPGA_DONE_3V3: U11.4 (B); also elsewhere on the board
/FPGA support/FPGA_FLASH_CS_N: R48.2, R54.1, U13.C2 (CS_N)
/FPGA support/FPGA_FLASH_DQ0: R44.2, R50.2
/FPGA support/FPGA_FLASH_DQ1: R45.2, R51.2
/FPGA support/FPGA_FLASH_DQ2: R46.2, R52.2, R55.1
/FPGA support/FPGA_FLASH_DQ3: R47.2, R53.2, R56.1
/FPGA support/FPGA_FLASH_SCK: R49.2, U13.B2 (SCK)
/FPGA support/FPGA_INIT: R39.1, U8.W10 (INIT_B_0), U10.4 (B)
/FPGA support/FPGA_INIT_3V3: U10.3 (A); also elsewhere on the board
/FPGA support/FPGA_INIT_OE: U10.5 (DIR); also elsewhere on the board
/FPGA support/FPGA_JTAG_TCK: J8.6 (TCK), U8.AE12 (TCK_0)
/FPGA support/FPGA_JTAG_TDI: J8.10 (TDI_OUT), U8.AB12 (TDI_0)
/FPGA support/FPGA_JTAG_TDO: J8.8 (TDO_IN), R43.1
/FPGA support/FPGA_JTAG_TMS: J8.4 (TMS), U8.AB10 (TMS_0)
/FPGA support/FPGA_RESET_N: R41.1, U8.AB9 (PROGRAM_B_0), U12.3 (A)
/FPGA support/FPGA_RESET_N_3V3: U12.4 (B); also elsewhere on the board
/FPGA support/GTY_VCC: C58.1, C61.1, U8.AA7 (MGTAVCC_R), U8.AC7 (MGTAVCC_R), U8.J7 (MGTAVCC_R), U8.L7 (MGTAVCC_R), U8.N7 (MGTAVCC_R), U8.W7 (MGTAVCC_R); also elsewhere on the board
/FPGA support/GTY_VCCAUX: C60.1, C63.1, U8.R7 (MGTVCCAUX_R), U8.U7 (MGTVCCAUX_R); also elsewhere on the board
/FPGA support/POR_OVERRIDE: J7.2, U8.Y12 (POR_OVERRIDE)
/FPGA support/VCCINT: C40.1, C41.1, C45.1, C49.1, C52.1, C53.1, C54.1, C55.1, C56.1, C57.1, J7.1, U8.K11 (VCCINT), U8.K13 (VCCINT), U8.K15 (VCCINT), U8.K17 (VCCINT), U8.L9 (VCCINT_IO), U8.L10 (VCCINT), U8.L12 (VCCINT), U8.L14 (VCCINT), U8.L16 (VCCINT), U8.M9 (VCCINT_IO), U8.M11 (VCCINT), U8.M13 (VCCINT), U8.M15 (VCCINT), U8.M17 (VCCINT), U8.N9 (VCCINT_IO), U8.N10 (VCCINT), U8.N12 (VCCINT), U8.N16 (VCCINT), U8.P9 (VCCINT_IO), U8.P11 (VCCINT), U8.P15 (VCCINT), U8.P17 (VCCINT), U8.R9 (VCCBRAM), U8.R10 (VCCINT), U8.R12 (VCCINT), U8.R16 (VCCINT), U8.T9 (VCCBRAM), U8.T11 (VCCINT), U8.T15 (VCCINT), U8.T17 (VCCINT), U8.U9 (VCCBRAM), U8.U10 (VCCINT), U8.U12 (VCCINT), U8.U14 (VCCINT), U8.U16 (VCCINT), U8.V9 (VCCBRAM), U8.V11 (VCCINT), U8.V13 (VCCINT), U8.V15 (VCCINT), U8.V17 (VCCINT); also elsewhere on the board
/GND: C40.2, C41.2, C42.2, C43.2, C44.2, C45.2, C46.2, C47.2, C48.2, C49.2, C50.2, C51.2, C52.2, C53.2, C54.2, C55.2, C56.2, C57.2, C58.2, C59.2, C60.2, C61.2, C62.2, C63.2, C64.2, C65.2, C66.2, C67.2, C68.2, C69.2, C70.2, C71.2, C102.2, C154.2, C155.2, J7.3, J8.3 (Vss), J8.5 (Vss), J8.7 (Vss), J8.9 (Vss), J8.11 (Vss), U8.A1 (GND), U8.A2 (GND), U8.A5 (GND), U8.A6 (GND), U8.A8 (GND), U8.A11 (GND), U8.A16 (GND), U8.A21 (GND), U8.A26 (GND), U8.AA1 (GND), U8.AA2 (GND), U8.AA3 (GND), U8.AA6 (GND), U8.AA8 (GND), U8.AA9 (M1_0), U8.AA16 (GND), U8.AA26 (GND), U8.AB3 (GND), U8.AB4 (GND), U8.AB8 (GND), U8.AB13 (GND), U8.AB23 (GND), U8.AC1 (GND), U8.AC2 (GND), U8.AC3 (GND), U8.AC6 (GND), U8.AC8 (GND), U8.AC9 (GND), U8.AC10 (GND), U8.AC20 (GND), U8.AC25 (GND), U8.AD3 (GND), U8.AD4 (GND), U8.AD5 (GND), U8.AD10 (GND), U8.AD17 (GND), U8.AE1 (GND), U8.AE2 (GND), U8.AE5 (GND), U8.AE6 (GND), U8.AE10 (GND), U8.AE14 (GND), U8.AE19 (GND), U8.AE24 (GND), U8.AF3 (GND), U8.AF4 (GND), U8.AF5 (GND), U8.AF8 (GND), U8.AF9 (GND), U8.AF10 (GND), U8.AF11 (GND), U8.AF12 (M2_0), U8.AF16 (GND), U8.AF21 (GND), U8.AF26 (GND), U8.B3 (GND), U8.B4 (GND), U8.B5 (GND), U8.B8 (GND), U8.B13 (GND), U8.B18 (GND), U8.B23 (GND), U8.C1 (GND), U8.C2 (GND), U8.C5 (GND), U8.C6 (GND), U8.C8 (GND), U8.C10 (GND), U8.C15 (GND), U8.C25 (GND), U8.D3 (GND), U8.D4 (GND), U8.D5 (GND), U8.D8 (GND), U8.D12 (GND), U8.D22 (GND), U8.E1 (GND), U8.E2 (GND), U8.E3 (GND), U8.E6 (GND), U8.E8 (GND), U8.E19 (GND), U8.F3 (GND), U8.F4 (GND), U8.F8 (GND), U8.F11 (GND), U8.F16 (GND), U8.F21 (GND), U8.F26 (GND), U8.G1 (GND), U8.G2 (GND), U8.G3 (GND), U8.G6 (GND), U8.G8 (GND), U8.G13 (GND), U8.G23 (GND), U8.H3 (GND), U8.H4 (GND), U8.H8 (GND), U8.H20 (GND), U8.J1 (GND), U8.J2 (GND), U8.J3 (GND), U8.J6 (GND), U8.J8 (GND), U8.J17 (GND), U8.K3 (GND), U8.K4 (GND), U8.K8 (GND), U8.K12 (GND), U8.K14 (GND), U8.K16 (GND), U8.K19 (GND), U8.K24 (GND), U8.L1 (GND), U8.L2 (GND), U8.L3 (GND), U8.L6 (GND), U8.L8 (GND), U8.L11 (GND), U8.L13 (GND), U8.L15 (GND), U8.L17 (GND), U8.L21 (GND), U8.L26 (GND), U8.M3 (GND), U8.M4 (GND), U8.M8 (GND), U8.M10 (GND), U8.M12 (GND), U8.M14 (GND), U8.M16 (GND), U8.M23 (GND), U8.N1 (GND), U8.N2 (GND), U8.N3 (GND), U8.N6 (GND), U8.N8 (GND), U8.N11 (GND), U8.N13 (GNDADC), U8.N15 (GND), U8.N17 (GND), U8.N20 (GND), U8.N25 (GND), U8.P3 (GND), U8.P4 (GND), U8.P8 (GND), U8.P10 (GND), U8.P12 (GND), U8.P13 (VREFN), U8.P14 (VP), U8.P16 (GND), U8.R1 (GND), U8.R2 (GND), U8.R3 (GND), U8.R6 (GND), U8.R8 (GND), U8.R11 (GND), U8.R13 (VN), U8.R14 (VREFP), U8.R15 (GND), U8.R17 (GND), U8.R19 (GND), U8.R24 (GND), U8.T3 (GND), U8.T4 (GND), U8.T8 (GND), U8.T10 (GND), U8.T12 (GND), U8.T13 (DXN), U8.T14 (DXP), U8.T16 (GND), U8.T21 (GND), U8.T26 (GND), U8.U1 (GND), U8.U2 (GND), U8.U3 (GND), U8.U6 (GND), U8.U8 (GND), U8.U11 (GND), U8.U13 (GND), U8.U15 (GND), U8.U17 (GND), U8.U18 (GND), U8.V3 (GND), U8.V4 (GND), U8.V8 (GND), U8.V10 (GND), U8.V12 (GND), U8.V14 (GND), U8.V16 (GND), U8.V20 (GND), U8.V25 (GND), U8.W1 (GND), U8.W2 (GND), U8.W3 (GND), U8.W6 (GND), U8.W8 (GND), U8.W11 (RSVDGND), U8.W17 (GND), U8.W22 (GND), U8.Y3 (GND), U8.Y4 (GND), U8.Y8 (GND), U8.Y19 (GND), U10.2 (GND), U11.2 (GND), U12.2 (GND), U12.5 (DIR), U13.B3 (VSS); also elsewhere on the board
/GTY_VTT: C59.1, C62.1, U8.A7 (MGTAVTT_R), U8.AB5 (MGTAVTT_R), U8.AE7 (MGTAVTT_R), U8.C7 (MGTAVTT_R), U8.E7 (MGTAVTT_R), U8.F5 (MGTAVTT_R), U8.G7 (MGTAVTT_R), U8.H5 (MGTAVTT_R), U8.K5 (MGTAVTT_R), U8.M5 (MGTAVTT_R), U8.P5 (MGTAVTT_R), U8.T5 (MGTAVTT_R), U8.V5 (MGTAVTT_R), U8.Y5 (MGTAVTT_R); also elsewhere on the board
unnamed: R49.1, U8.Y11 (CCLK_0)
unnamed: R50.1, U8.AD11 (D00_MOSI_0)
unnamed: R51.1, U8.AC12 (D01_DIN_0)
unnamed: R52.1, U8.AC11 (D02_0)
unnamed: R53.1, U8.AE11 (D03_0)
unnamed: R48.1, U8.AA12 (RDWR_FCS_B_0)
unnamed: R43.2, U8.Y10 (TDO_0)
unnamed: R45.1, U13.D2 (MISO/DQ1)
unnamed: R44.1, U13.D3 (MOSI/DQ0)
unnamed: R42.2, U13.A4 (RESET_N)
unnamed: R47.1, U13.D4 (RESET_N/DQ3)
unnamed: R46.1, U13.C4 (WP_N/DQ2)

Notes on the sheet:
FPGA control signal level shifting
FPGA decoupling
FPGA boot/debug
VCCO 0/64/65/66/67
We don't support holding DONE low to delay configuration It's only used as an output in this design
Need min 128 Mb flash For fallback boot, need 256 Mb Must be 1.8V capable
POR_OVERRIDE to VCCINT not VCCO! See UG575 table 1-5
VCCO 84/86/87
FPGA power
VCCBRAM (this might be overkill if we combine rails)
VCCINT/VCCINT_IO
Heatsink
VCCAUX
Flash
GTY decoupling We have only one power supply group, so one set of caps is probably enough kup-lulz had two, keep that if we have space at layout time

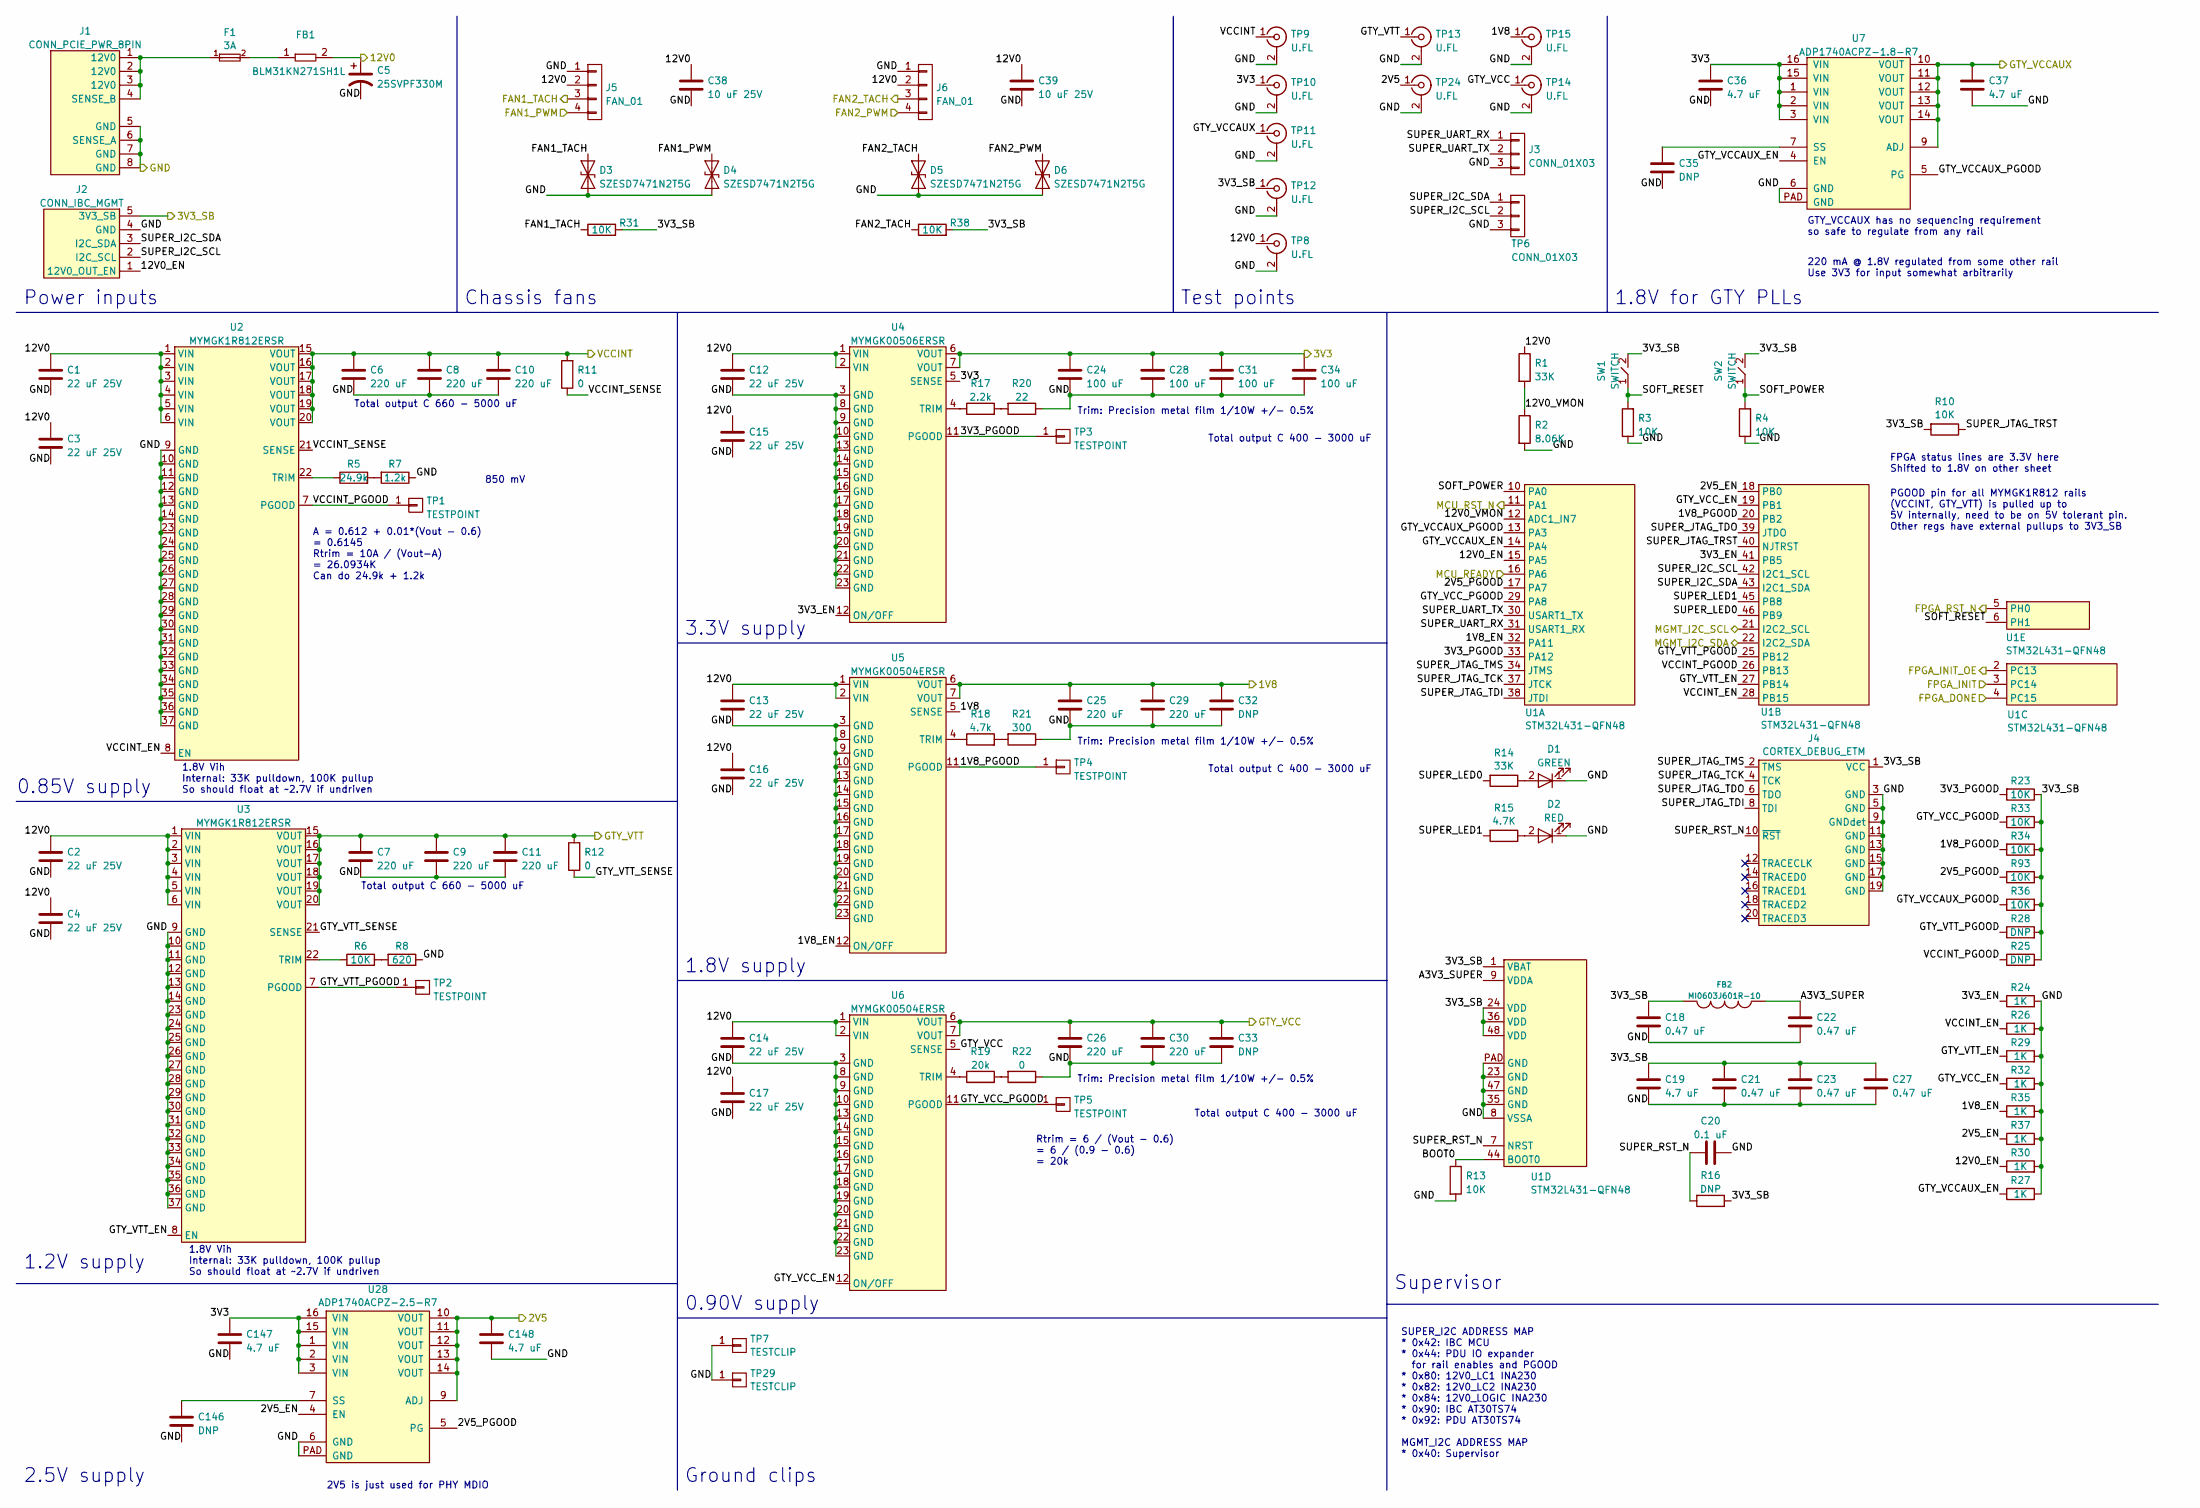
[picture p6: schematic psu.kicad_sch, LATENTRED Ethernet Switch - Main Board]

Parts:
C1, C2, C3, C4, C12, C13, C14, C15, C16, C17: 22 uF 25V; EIA_1812_CAP_NOSILK
C5: 25SVPF330M; CAP_AL_10MM_SMT
C6, C7, C8, C9, C10, C11, C25, C26, C29, C30: 220 uF; EIA_1210_CAP_NOSILK
C18, C21, C22, C23, C27: 0.47 uF; EIA_0402_CAP_NOSILK
C19, C36, C37, C147, C148: 4.7 uF; EIA_0603_CAP_NOSILK
C20: 0.1 uF; EIA_0402_CAP_NOSILK
C24, C28, C31, C34: 100 uF; EIA_1210_CAP_NOSILK
C32, C33: DNP; EIA_1210_CAP_NOSILK
C35, C146: DNP; EIA_0402_CAP_NOSILK
C38, C39: 10 uF 25V; EIA_1210_CAP_NOSILK
D1: GREEN; EIA_0402_LED
D2: RED; EIA_0402_LED
D3, D4, D5, D6: SZESD7471N2T5G; SOD882
F1: 3A; EIA_0603_CAP_NOSILK
FB1: BLM31KN271SH1L; EIA_1206_CAP_NOSILK
FB2: MI0603J601R-10; EIA_0603_INDUCTOR_NOSILK
J1: CONN_PCIE_PWR_8PIN; CONN_MOLEX_MINIFITJR_8POS_0039291087
J2: CONN_IBC_MGMT; CONN_MOLEX_PICOBLADE_5POS_0532610571
J3: CONN_01X03; CONN_HEADER_2.54MM_1x3_REFLOW
J4: CORTEX_DEBUG_ETM; CONN_HEADER_1.27MM_2x10_SMT_SAMTEC_FTSH-110-01-L-DV-K
J5, J6: FAN_01; CONN_MOLEX_KK_0470531000
R1, R14: 33K; EIA_0402_RES_NOSILK
R2: 8.06K; EIA_0402_RES_NOSILK
R3, R4, R6, R10, R13, R23, R31, R33, R34, R36, R38, R93: 10K; EIA_0402_RES_NOSILK
R5: 24.9k; EIA_0402_RES_NOSILK
R7: 1.2k; EIA_0402_RES_NOSILK
R8: 620; EIA_0402_RES_NOSILK
R11, R12, R22: 0; EIA_0402_RES_NOSILK
R15: 4.7K; EIA_0402_RES_NOSILK
R16, R25, R28: DNP; EIA_0402_RES_NOSILK
R17: 2.2k; EIA_0402_RES_NOSILK
R18: 4.7k; EIA_0402_RES_NOSILK
R19: 20k; EIA_0402_RES_NOSILK
R20: 22; EIA_0402_RES_NOSILK
R21: 300; EIA_0402_RES_NOSILK
R24, R26, R27, R29, R30, R32, R35, R37: 1K; EIA_0402_RES_NOSILK
SW1, SW2: SWITCH; SWITCH_RAFI_MICON_5
TP1, TP2, TP3, TP4, TP5: TESTPOINT; TESTPOINT_SMT_0.5MM
TP6: CONN_01X03; CONN_HEADER_2.54MM_1x3_REFLOW
TP7, TP29: TESTCLIP; TESTPOINT_SMT_KEYSTONE_5016
TP8, TP9, TP10, TP11, TP12, TP13, TP14, TP15, TP24: U.FL; CONN_U.FL_TE_1909763-1
U1: STM32L431-QFN48; QFN_48_0.5MM_7x7MM
U2, U3: MYMGK1R812ERSR; MODULE_MURATA_MYMGK1R812
U4: MYMGK00506ERSR; MODULE_MURATA_MYMGK00504ERSR
U5, U6: MYMGK00504ERSR; MODULE_MURATA_MYMGK00504ERSR
U7: ADP1740ACPZ-1.8-R7; QFN_16_0.65MM_4x4MM
U28: ADP1740ACPZ-2.5-R7; QFN_16_0.65MM_4x4MM

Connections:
/1V8: C25.1, C29.1, C32.1, TP15.1 (In), U5.5 (SENSE), U5.6 (VOUT), U5.7 (VOUT); also elsewhere on the board
/2V5: C148.1, TP24.1 (In), U28.9 (ADJ), U28.10 (VOUT), U28.11 (VOUT), U28.12 (VOUT), U28.13 (VOUT), U28.14 (VOUT); also elsewhere on the board
/3V3: C24.1, C28.1, C31.1, C34.1, C36.1, C147.1, TP10.1 (In), U4.5 (SENSE), U4.6 (VOUT), U4.7 (VOUT), U7.1 (VIN), U7.2 (VIN), U7.3 (VIN), U7.15 (VIN), U7.16 (VIN), U28.1 (VIN), U28.2 (VIN), U28.3 (VIN), U28.15 (VIN), U28.16 (VIN); also elsewhere on the board
/FPGA support/FPGA_DONE_3V3: U1.4 (PC15); also elsewhere on the board
/FPGA support/FPGA_INIT_3V3: U1.3 (PC14); also elsewhere on the board
/FPGA support/FPGA_INIT_OE: U1.2 (PC13); also elsewhere on the board
/FPGA support/FPGA_RESET_N_3V3: U1.5 (PH0); also elsewhere on the board
/FPGA support/GTY_VCC: C26.1, C30.1, C33.1, TP14.1 (In), U6.5 (SENSE), U6.6 (VOUT), U6.7 (VOUT); also elsewhere on the board
/FPGA support/GTY_VCCAUX: C37.1, TP11.1 (In), U7.9 (ADJ), U7.10 (VOUT), U7.11 (VOUT), U7.12 (VOUT), U7.13 (VOUT), U7.14 (VOUT); also elsewhere on the board
/FPGA support/VCCINT: C6.1, C8.1, C10.1, R11.2, TP9.1 (In), U2.15 (VOUT), U2.16 (VOUT), U2.17 (VOUT), U2.18 (VOUT), U2.19 (VOUT), U2.20 (VOUT); also elsewhere on the board
/GND: C1.2, C2.2, C3.2, C4.2, C5.2, C6.2, C7.2, C8.2, C9.2, C10.2, C11.2, C12.2, C13.2, C14.2, C15.2, C16.2, C17.2, C18.2, C19.2, C20.2, C21.2, C22.2, C23.2, C24.2, C25.2, C26.2, C27.2, C28.2, C29.2, C30.2, C31.2, C32.2, C33.2, C34.2, C35.2, C36.2, C37.2, C38.2, C39.2, C146.2, C147.2, C148.2, D1.1 (K), D2.1 (K), D3.1 (A1), D4.1 (A1), D5.1 (A1), D6.1 (A1), J1.5 (GND), J1.6 (SENSE_A), J1.7 (GND), J1.8 (GND), J2.4 (GND), J3.3, J4.3 (GND), J4.5 (GND), J4.9 (GNDdet), J4.11 (GND), J4.13 (GND), J4.15 (GND), J4.17 (GND), J4.19 (GND), J5.1, J6.1, R2.2, R3.1, R4.1, R7.1, R8.1, R13.2, R20.1, R21.1, R22.1, R24.2, R26.2, R27.2, R29.2, R30.2, R32.2, R35.2, R37.2, TP6.3, TP7.1, TP8.2 (Ext), TP9.2 (Ext), TP10.2 (Ext), TP11.2 (Ext), TP12.2 (Ext), TP13.2 (Ext), TP14.2 (Ext), TP15.2 (Ext), TP24.2 (Ext), TP29.1, U1.8 (VSSA), U1.23 (GND), U1.35 (GND), U1.47 (GND), U1.PAD (GND), U2.9 (GND), U2.10 (GND), U2.11 (GND), U2.12 (GND), U2.13 (GND), U2.14 (GND), U2.23 (GND), U2.24 (GND), U2.25 (GND), U2.26 (GND), U2.27 (GND), U2.28 (GND), U2.29 (GND), U2.30 (GND), U2.31 (GND), U2.32 (GND), U2.33 (GND), U2.34 (GND), U2.35 (GND), U2.36 (GND), U2.37 (GND), U3.9 (GND), U3.10 (GND), U3.11 (GND), U3.12 (GND), U3.13 (GND), U3.14 (GND), U3.23 (GND), U3.24 (GND), U3.25 (GND), U3.26 (GND), U3.27 (GND), U3.28 (GND), U3.29 (GND), U3.30 (GND), U3.31 (GND), U3.32 (GND), U3.33 (GND), U3.34 (GND), U3.35 (GND), U3.36 (GND), U3.37 (GND), U4.3 (GND), U4.8 (GND), U4.9 (GND), U4.10 (GND), U4.13 (GND), U4.14 (GND), U4.15 (GND), U4.16 (GND), U4.17 (GND), U4.18 (GND), U4.19 (GND), U4.20 (GND), U4.21 (GND), U4.22 (GND), U4.23 (GND), U5.3 (GND), U5.8 (GND), U5.9 (GND), U5.10 (GND), U5.13 (GND), U5.14 (GND), U5.15 (GND), U5.16 (GND), U5.17 (GND), U5.18 (GND), U5.19 (GND), U5.20 (GND), U5.21 (GND), U5.22 (GND), U5.23 (GND), U6.3 (GND), U6.8 (GND), U6.9 (GND), U6.10 (GND), U6.13 (GND), U6.14 (GND), U6.15 (GND), U6.16 (GND), U6.17 (GND), U6.18 (GND), U6.19 (GND), U6.20 (GND), U6.21 (GND), U6.22 (GND), U6.23 (GND), U7.6 (GND), U7.PAD (GND), U28.6 (GND), U28.PAD (GND); also elsewhere on the board
/GTY_VTT: C7.1, C9.1, C11.1, R12.2, TP13.1 (In), U3.15 (VOUT), U3.16 (VOUT), U3.17 (VOUT), U3.18 (VOUT), U3.19 (VOUT), U3.20 (VOUT); also elsewhere on the board
/MCU/3V3_SB: C18.1, C19.1, C21.1, C23.1, C27.1, FB2.2, J2.5 (3V3_SB), J4.1 (VCC), R10.2, R16.1, R23.1, R25.2, R28.2, R31.2, R33.1, R34.1, R36.2, R38.2, R93.2, SW1.2, SW2.2, TP12.1 (In), U1.1 (VBAT), U1.24 (VDD), U1.36 (VDD), U1.48 (VDD); also elsewhere on the board
/MCU/MCU_READY: U1.16 (PA6); also elsewhere on the board
/MCU/MCU_RST_N: U1.11 (PA1); also elsewhere on the board
/MCU/MGMT_I2C_SCL: U1.21 (I2C2_SCL); also elsewhere on the board
/MCU/MGMT_I2C_SDA: U1.22 (I2C2_SDA); also elsewhere on the board
/Power Supply/1V8_EN: R35.1, U1.32 (PA11), U5.12 (ON/OFF)
/Power Supply/1V8_PGOOD: R34.2, TP4.1, U1.20 (PB2), U5.11 (PGOOD)
/Power Supply/2V5_EN: R37.1, U1.18 (PB0), U28.4 (EN)
/Power Supply/2V5_PGOOD: R93.1, U1.17 (PA7), U28.5 (PG)
/Power Supply/3V3_EN: R24.1, U1.41 (PB5), U4.12 (ON/OFF)
/Power Supply/3V3_PGOOD: R23.2, TP3.1, U1.33 (PA12), U4.11 (PGOOD)
/Power Supply/12V0: C1.1, C2.1, C3.1, C4.1, C5.1, C12.1, C13.1, C14.1, C15.1, C16.1, C17.1, C38.1, C39.1, FB1.2, J5.2, J6.2, R1.1, TP8.1 (In), U2.1 (VIN), U2.2 (VIN), U2.3 (VIN), U2.4 (VIN), U2.5 (VIN), U2.6 (VIN), U3.1 (VIN), U3.2 (VIN), U3.3 (VIN), U3.4 (VIN), U3.5 (VIN), U3.6 (VIN), U4.1 (VIN), U4.2 (VIN), U5.1 (VIN), U5.2 (VIN), U6.1 (VIN), U6.2 (VIN)
/Power Supply/12V0_EN: J2.1 (12V0_OUT_EN), R30.1, U1.15 (PA5)
/Power Supply/12V0_VMON: R1.2, R2.1, U1.12 (ADC1_IN7)
/Power Supply/A3V3_SUPER: C22.1, FB2.1, U1.9 (VDDA)
/Power Supply/BOOT0: R13.1, U1.44 (BOOT0)
/Power Supply/FAN1_PWM: D4.2 (A2), J5.4; also elsewhere on the board
/Power Supply/FAN1_TACH: D3.2 (A2), J5.3, R31.1; also elsewhere on the board
/Power Supply/FAN2_PWM: D6.2 (A2), J6.4; also elsewhere on the board
/Power Supply/FAN2_TACH: D5.2 (A2), J6.3, R38.1; also elsewhere on the board
/Power Supply/GTY_VCCAUX_EN: R27.1, U1.14 (PA4), U7.4 (EN)
/Power Supply/GTY_VCCAUX_PGOOD: R36.1, U1.13 (PA3), U7.5 (PG)
/Power Supply/GTY_VCC_EN: R32.1, U1.19 (PB1), U6.12 (ON/OFF)
/Power Supply/GTY_VCC_PGOOD: R33.2, TP5.1, U1.29 (PA8), U6.11 (PGOOD)
/Power Supply/GTY_VTT_EN: R29.1, U1.27 (PB14), U3.8 (EN)
/Power Supply/GTY_VTT_PGOOD: R28.1, TP2.1, U1.25 (PB12), U3.7 (PGOOD)
/Power Supply/GTY_VTT_SENSE: R12.1, U3.21 (SENSE)
/Power Supply/SOFT_POWER: R4.2, SW2.1, U1.10 (PA0)
/Power Supply/SOFT_RESET: R3.2, SW1.1, U1.6 (PH1)
/Power Supply/SUPER_I2C_SCL: J2.2 (I2C_SCL), TP6.2, U1.42 (I2C1_SCL)
/Power Supply/SUPER_I2C_SDA: J2.3 (I2C_SDA), TP6.1, U1.43 (I2C1_SDA)
/Power Supply/SUPER_JTAG_TCK: J4.4 (TCK), U1.37 (JTCK)
/Power Supply/SUPER_JTAG_TDI: J4.8 (TDI), U1.38 (JTDI)
/Power Supply/SUPER_JTAG_TDO: J4.6 (TDO), U1.39 (JTDO)
/Power Supply/SUPER_JTAG_TMS: J4.2 (TMS), U1.34 (JTMS)
/Power Supply/SUPER_JTAG_TRST: R10.1, U1.40 (NJTRST)
/Power Supply/SUPER_LED0: R14.2, U1.46 (PB9)
/Power Supply/SUPER_LED1: R15.2, U1.45 (PB8)
/Power Supply/SUPER_RST_N: C20.1, J4.10 (~RST), R16.2, U1.7 (NRST)
/Power Supply/SUPER_UART_RX: J3.1, U1.31 (USART1_RX)
/Power Supply/SUPER_UART_TX: J3.2, U1.30 (USART1_TX)
/Power Supply/VCCINT_EN: R26.1, U1.28 (PB15), U2.8 (EN)
/Power Supply/VCCINT_PGOOD: R25.1, TP1.1, U1.26 (PB13), U2.7 (PGOOD)
/Power Supply/VCCINT_SENSE: R11.1, U2.21 (SENSE)
unnamed: D1.2 (A), R14.1
unnamed: D2.2 (A), R15.1
unnamed: F1.2, FB1.1
unnamed: F1.1, J1.1 (12V0), J1.2 (12V0), J1.3 (12V0), J1.4 (SENSE_B)
unnamed: R5.2, R7.2
unnamed: R6.2, R8.2
unnamed: R17.2, R20.2
unnamed: R18.2, R21.2
unnamed: R19.2, R22.2
unnamed: R5.1, U2.22 (TRIM)
unnamed: R6.1, U3.22 (TRIM)
unnamed: R17.1, U4.4 (TRIM)
unnamed: R18.1, U5.4 (TRIM)
unnamed: R19.1, U6.4 (TRIM)
unnamed: C35.1, U7.7 (SS)
unnamed: C146.1, U28.7 (SS)

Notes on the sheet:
A = 0.612 + 0.01*(Vout - 0.6) = 0.6145 Rtrim = 10A / (Vout-A) = 26.0934K Can do 24.9k + 1.2k
2.5V supply
FPGA status lines are 3.3V here Shifted to 1.8V on other sheet
0.85V supply
Ground clips
Rtrim = 6 / (Vout - 0.6) = 6 / (0.9 - 0.6) = 20k
Supervisor
Test points
Total output C 400 - 3000 uF
220 mA @ 1.8V regulated from some other rail Use 3V3 for input somewhat arbitrarily
0.90V supply
850 mV
1.8V supply
1.8V for GTY PLLs
1.8V Vih Internal: 33K pulldown, 100K pullup So should float at ~2.7V if undriven
3.3V supply
Total output C 660 - 5000 uF
Power inputs
PGOOD pin for all MYMGK1R812 rails (VCCINT, GTY_VTT) is pulled up to 5V internally, need to be on 5V tolerant pin. Other regs have external pullups to 3V3_SB
Trim: Precision metal film 1/10W +/- 0.5%
2V5 is just used for PHY MDIO
Chassis fans
SUPER_I2C ADDRESS MAP * 0x42: IBC MCU * 0x44: PDU IO expander for rail enables and PGOOD * 0x80: 12V0_LC1 INA230 * 0x82: 12V0_LC2 INA230 * 0x84: 12V0_LOGIC INA230 * 0x90: IBC AT30TS74 * 0x92: PDU AT30TS74 MGMT_I2C ADDRESS MAP * 0x40: Supervisor
GTY_VCCAUX has no sequencing requirement so safe to regulate from any rail
1.2V supply

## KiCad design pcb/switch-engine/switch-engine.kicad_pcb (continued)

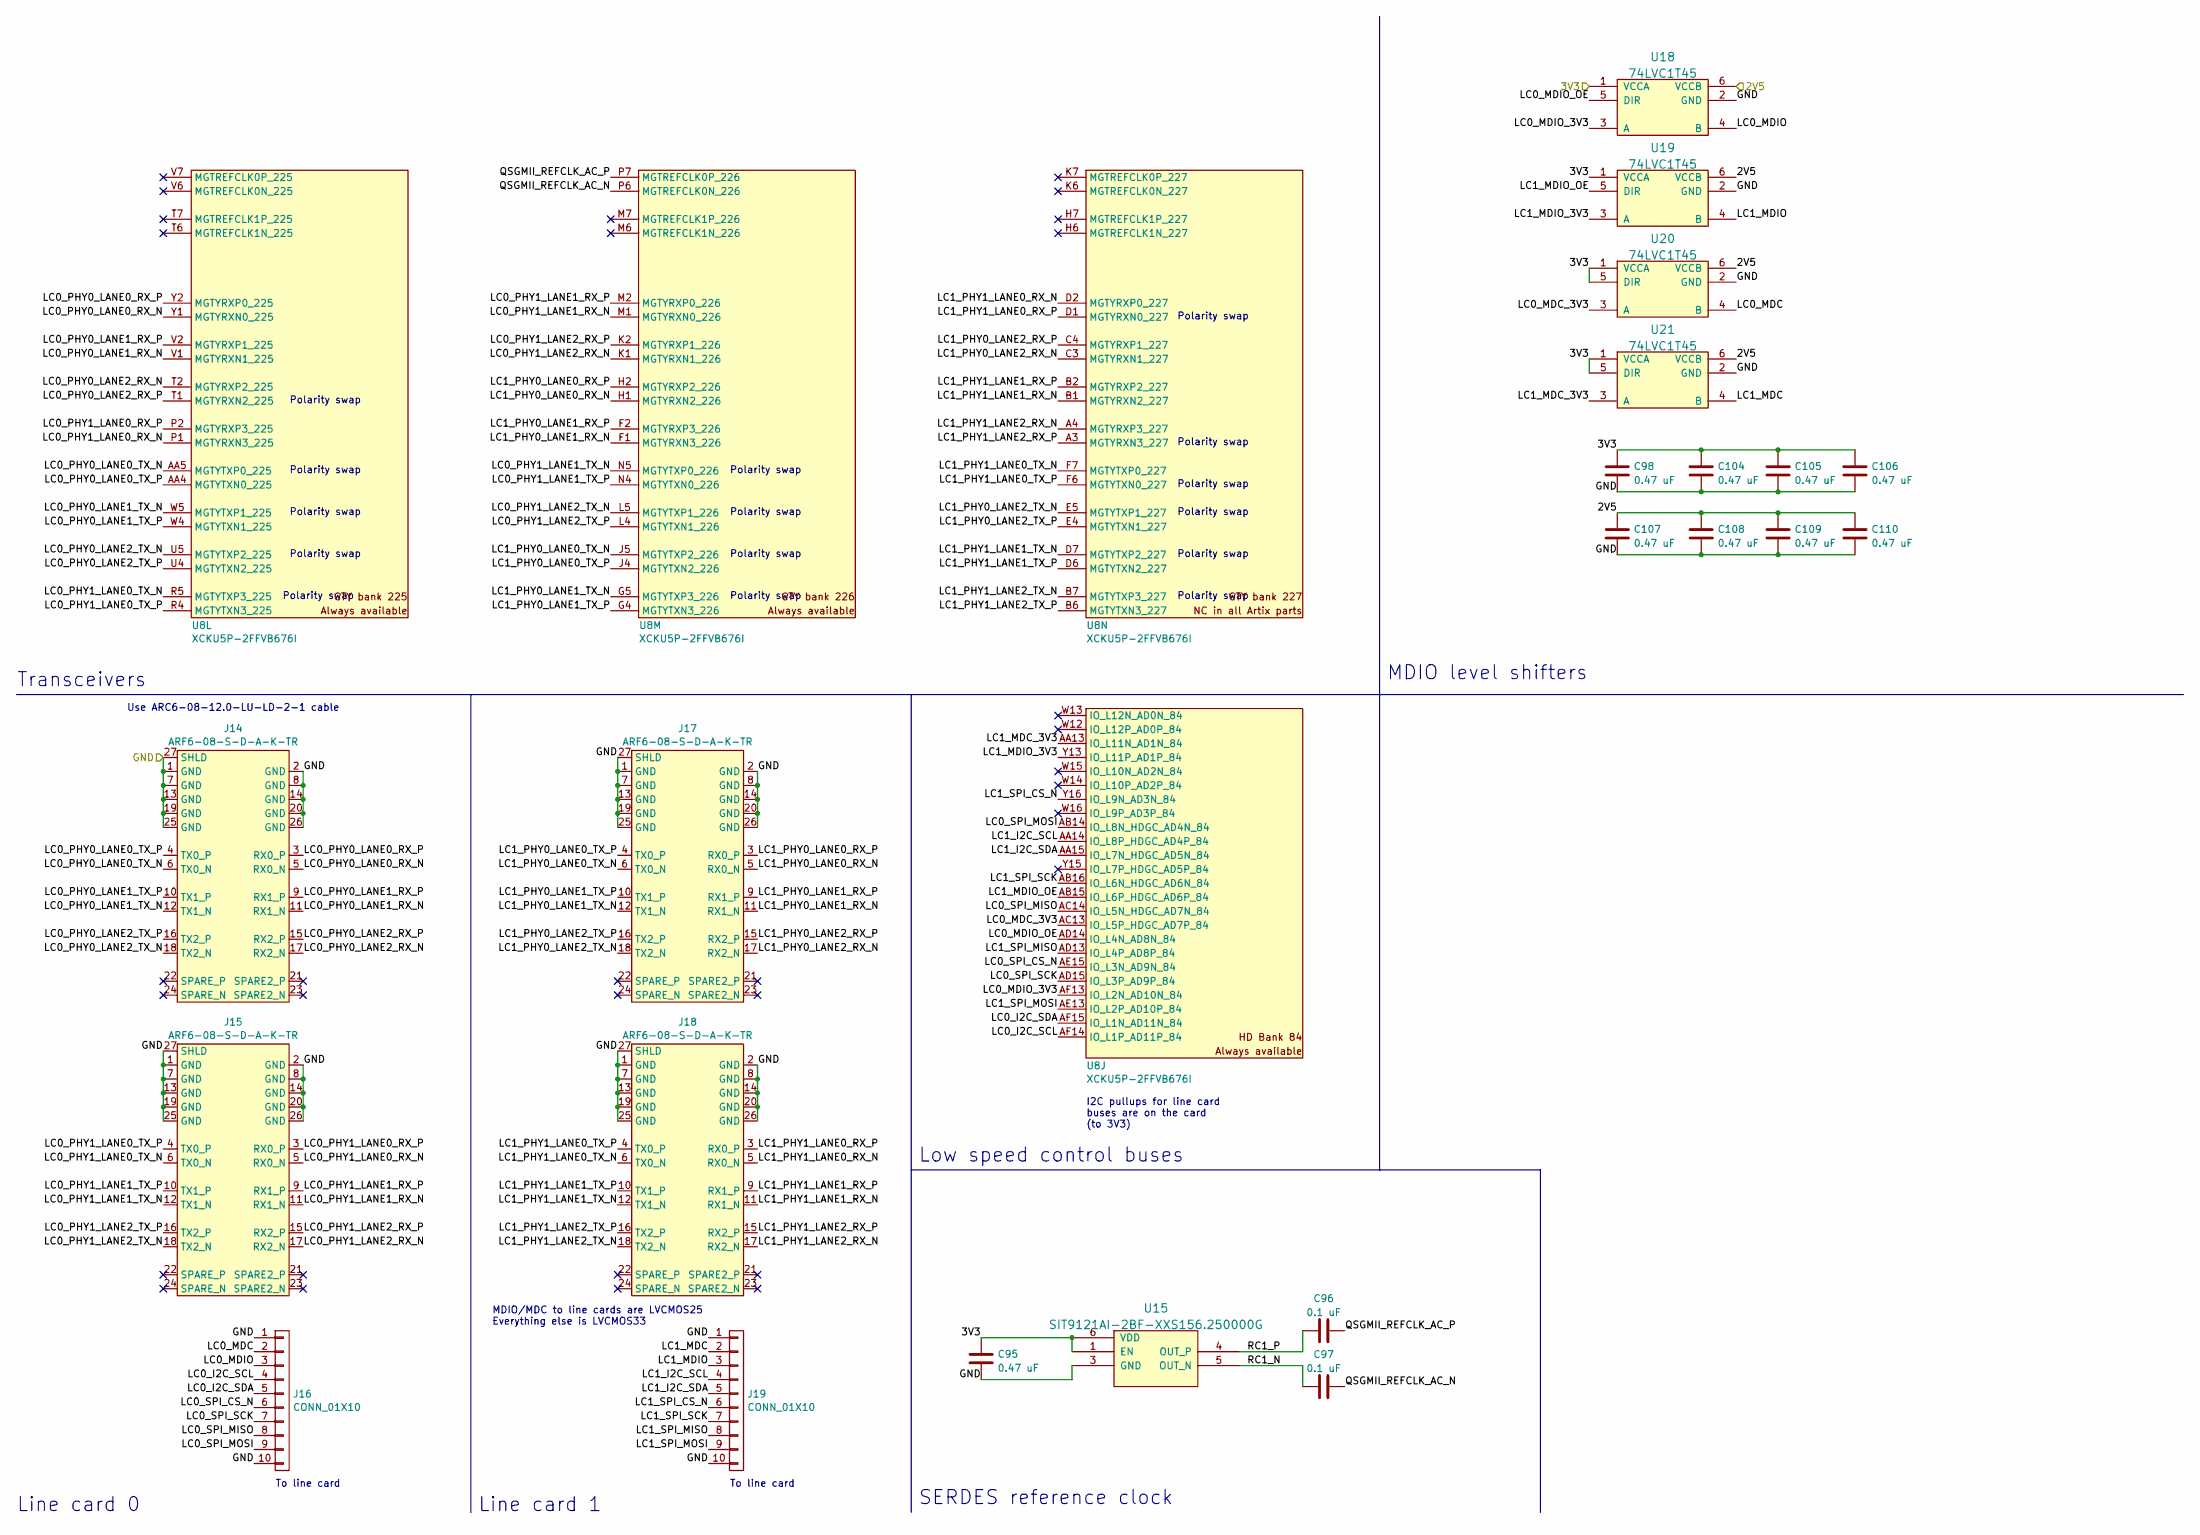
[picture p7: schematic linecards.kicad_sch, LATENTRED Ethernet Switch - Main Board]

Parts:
C95, C98, C104, C105, C106, C107, C108, C109, C110: 0.47 uF; EIA_0402_CAP_NOSILK
C96, C97: 0.1 uF; EIA_0402_CAP_NOSILK
J14, J15, J17, J18: ARF6-08-S-D-A-K-TR; CONN_SAMTEC_ARF6-08-S-D-A-K-TR
J16, J19: CONN_01X10; CONN_MOLEX_PICOBLADE_10POS_0532611071
U8: XCKU5P-2FFVB676I; BGA_676_27x27_FULLARRAY_1MM_FFG676
U15: SIT9121AI-2BF-XXS156.250000G; OSCILLATOR_LVDS_3.2x2.5
U18, U19, U20, U21: 74LVC1T45; DFN_6_0.5MM_1.6x1.6MM_TI_DPK

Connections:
/2V5: C107.1, C108.1, C109.1, C110.1, U18.6 (VCCB), U19.6 (VCCB), U20.6 (VCCB), U21.6 (VCCB); also elsewhere on the board
/3V3: C95.1, C98.1, C104.1, C105.1, C106.1, U15.1 (EN), U15.6 (VDD), U18.1 (VCCA), U19.1 (VCCA), U20.1 (VCCA), U20.5 (DIR), U21.1 (VCCA), U21.5 (DIR); also elsewhere on the board
/GND: C95.2, C98.2, C104.2, C105.2, C106.2, C107.2, C108.2, C109.2, C110.2, J14.1 (GND), J14.2 (GND), J14.7 (GND), J14.8 (GND), J14.13 (GND), J14.14 (GND), J14.19 (GND), J14.20 (GND), J14.25 (GND), J14.26 (GND), J14.27 (SHLD), J15.1 (GND), J15.2 (GND), J15.7 (GND), J15.8 (GND), J15.13 (GND), J15.14 (GND), J15.19 (GND), J15.20 (GND), J15.25 (GND), J15.26 (GND), J15.27 (SHLD), J16.1, J16.10, J17.1 (GND), J17.2 (GND), J17.7 (GND), J17.8 (GND), J17.13 (GND), J17.14 (GND), J17.19 (GND), J17.20 (GND), J17.25 (GND), J17.26 (GND), J17.27 (SHLD), J18.1 (GND), J18.2 (GND), J18.7 (GND), J18.8 (GND), J18.13 (GND), J18.14 (GND), J18.19 (GND), J18.20 (GND), J18.25 (GND), J18.26 (GND), J18.27 (SHLD), J19.1, J19.10, U15.3 (GND), U18.2 (GND), U19.2 (GND), U20.2 (GND), U21.2 (GND); also elsewhere on the board
/Line card interfaces/LC0_I2C_SCL: J16.4, U8.AF14 (IO_L1P_AD11P_84)
/Line card interfaces/LC0_I2C_SDA: J16.5, U8.AF15 (IO_L1N_AD11N_84)
/Line card interfaces/LC0_MDC: J16.2, U20.4 (B)
/Line card interfaces/LC0_MDC_3V3: U8.AC13 (IO_L5P_HDGC_AD7P_84), U20.3 (A)
/Line card interfaces/LC0_MDIO: J16.3, U18.4 (B)
/Line card interfaces/LC0_MDIO_3V3: U8.AF13 (IO_L2N_AD10N_84), U18.3 (A)
/Line card interfaces/LC0_MDIO_OE: U8.AD14 (IO_L4N_AD8N_84), U18.5 (DIR)
/Line card interfaces/LC0_PHY0_LANE0_RX_N: J14.5 (RX0_N), U8.Y1 (MGTYRXN0_225)
/Line card interfaces/LC0_PHY0_LANE0_RX_P: J14.3 (RX0_P), U8.Y2 (MGTYRXP0_225)
/Line card interfaces/LC0_PHY0_LANE0_TX_N: J14.6 (TX0_N), U8.AA5 (MGTYTXP0_225)
/Line card interfaces/LC0_PHY0_LANE0_TX_P: J14.4 (TX0_P), U8.AA4 (MGTYTXN0_225)
/Line card interfaces/LC0_PHY0_LANE1_RX_N: J14.11 (RX1_N), U8.V1 (MGTYRXN1_225)
/Line card interfaces/LC0_PHY0_LANE1_RX_P: J14.9 (RX1_P), U8.V2 (MGTYRXP1_225)
/Line card interfaces/LC0_PHY0_LANE1_TX_N: J14.12 (TX1_N), U8.W5 (MGTYTXP1_225)
/Line card interfaces/LC0_PHY0_LANE1_TX_P: J14.10 (TX1_P), U8.W4 (MGTYTXN1_225)
/Line card interfaces/LC0_PHY0_LANE2_RX_N: J14.17 (RX2_N), U8.T2 (MGTYRXP2_225)
/Line card interfaces/LC0_PHY0_LANE2_RX_P: J14.15 (RX2_P), U8.T1 (MGTYRXN2_225)
/Line card interfaces/LC0_PHY0_LANE2_TX_N: J14.18 (TX2_N), U8.U5 (MGTYTXP2_225)
/Line card interfaces/LC0_PHY0_LANE2_TX_P: J14.16 (TX2_P), U8.U4 (MGTYTXN2_225)
/Line card interfaces/LC0_PHY1_LANE0_RX_N: J15.5 (RX0_N), U8.P1 (MGTYRXN3_225)
/Line card interfaces/LC0_PHY1_LANE0_RX_P: J15.3 (RX0_P), U8.P2 (MGTYRXP3_225)
/Line card interfaces/LC0_PHY1_LANE0_TX_N: J15.6 (TX0_N), U8.R5 (MGTYTXP3_225)
/Line card interfaces/LC0_PHY1_LANE0_TX_P: J15.4 (TX0_P), U8.R4 (MGTYTXN3_225)
/Line card interfaces/LC0_PHY1_LANE1_RX_N: J15.11 (RX1_N), U8.M1 (MGTYRXN0_226)
/Line card interfaces/LC0_PHY1_LANE1_RX_P: J15.9 (RX1_P), U8.M2 (MGTYRXP0_226)
/Line card interfaces/LC0_PHY1_LANE1_TX_N: J15.12 (TX1_N), U8.N5 (MGTYTXP0_226)
/Line card interfaces/LC0_PHY1_LANE1_TX_P: J15.10 (TX1_P), U8.N4 (MGTYTXN0_226)
/Line card interfaces/LC0_PHY1_LANE2_RX_N: J15.17 (RX2_N), U8.K1 (MGTYRXN1_226)
/Line card interfaces/LC0_PHY1_LANE2_RX_P: J15.15 (RX2_P), U8.K2 (MGTYRXP1_226)
/Line card interfaces/LC0_PHY1_LANE2_TX_N: J15.18 (TX2_N), U8.L5 (MGTYTXP1_226)
/Line card interfaces/LC0_PHY1_LANE2_TX_P: J15.16 (TX2_P), U8.L4 (MGTYTXN1_226)
/Line card interfaces/LC0_SPI_CS_N: J16.6, U8.AE15 (IO_L3N_AD9N_84)
/Line card interfaces/LC0_SPI_MISO: J16.8, U8.AC14 (IO_L5N_HDGC_AD7N_84)
/Line card interfaces/LC0_SPI_MOSI: J16.9, U8.AB14 (IO_L8N_HDGC_AD4N_84)
/Line card interfaces/LC0_SPI_SCK: J16.7, U8.AD15 (IO_L3P_AD9P_84)
/Line card interfaces/LC1_I2C_SCL: J19.4, U8.AA14 (IO_L8P_HDGC_AD4P_84)
/Line card interfaces/LC1_I2C_SDA: J19.5, U8.AA15 (IO_L7N_HDGC_AD5N_84)
/Line card interfaces/LC1_MDC: J19.2, U21.4 (B)
/Line card interfaces/LC1_MDC_3V3: U8.AA13 (IO_L11N_AD1N_84), U21.3 (A)
/Line card interfaces/LC1_MDIO: J19.3, U19.4 (B)
/Line card interfaces/LC1_MDIO_3V3: U8.Y13 (IO_L11P_AD1P_84), U19.3 (A)
/Line card interfaces/LC1_MDIO_OE: U8.AB15 (IO_L6P_HDGC_AD6P_84), U19.5 (DIR)
/Line card interfaces/LC1_PHY0_LANE0_RX_N: J17.5 (RX0_N), U8.H1 (MGTYRXN2_226)
/Line card interfaces/LC1_PHY0_LANE0_RX_P: J17.3 (RX0_P), U8.H2 (MGTYRXP2_226)
/Line card interfaces/LC1_PHY0_LANE0_TX_N: J17.6 (TX0_N), U8.J5 (MGTYTXP2_226)
/Line card interfaces/LC1_PHY0_LANE0_TX_P: J17.4 (TX0_P), U8.J4 (MGTYTXN2_226)
/Line card interfaces/LC1_PHY0_LANE1_RX_N: J17.11 (RX1_N), U8.F1 (MGTYRXN3_226)
/Line card interfaces/LC1_PHY0_LANE1_RX_P: J17.9 (RX1_P), U8.F2 (MGTYRXP3_226)
/Line card interfaces/LC1_PHY0_LANE1_TX_N: J17.12 (TX1_N), U8.G5 (MGTYTXP3_226)
/Line card interfaces/LC1_PHY0_LANE1_TX_P: J17.10 (TX1_P), U8.G4 (MGTYTXN3_226)
/Line card interfaces/LC1_PHY0_LANE2_RX_N: J17.17 (RX2_N), U8.C3 (MGTYRXN1_227)
/Line card interfaces/LC1_PHY0_LANE2_RX_P: J17.15 (RX2_P), U8.C4 (MGTYRXP1_227)
/Line card interfaces/LC1_PHY0_LANE2_TX_N: J17.18 (TX2_N), U8.E5 (MGTYTXP1_227)
/Line card interfaces/LC1_PHY0_LANE2_TX_P: J17.16 (TX2_P), U8.E4 (MGTYTXN1_227)
/Line card interfaces/LC1_PHY1_LANE0_RX_N: J18.5 (RX0_N), U8.D2 (MGTYRXP0_227)
/Line card interfaces/LC1_PHY1_LANE0_RX_P: J18.3 (RX0_P), U8.D1 (MGTYRXN0_227)
/Line card interfaces/LC1_PHY1_LANE0_TX_N: J18.6 (TX0_N), U8.F7 (MGTYTXP0_227)
/Line card interfaces/LC1_PHY1_LANE0_TX_P: J18.4 (TX0_P), U8.F6 (MGTYTXN0_227)
/Line card interfaces/LC1_PHY1_LANE1_RX_N: J18.11 (RX1_N), U8.B1 (MGTYRXN2_227)
/Line card interfaces/LC1_PHY1_LANE1_RX_P: J18.9 (RX1_P), U8.B2 (MGTYRXP2_227)
/Line card interfaces/LC1_PHY1_LANE1_TX_N: J18.12 (TX1_N), U8.D7 (MGTYTXP2_227)
/Line card interfaces/LC1_PHY1_LANE1_TX_P: J18.10 (TX1_P), U8.D6 (MGTYTXN2_227)
/Line card interfaces/LC1_PHY1_LANE2_RX_N: J18.17 (RX2_N), U8.A4 (MGTYRXP3_227)
/Line card interfaces/LC1_PHY1_LANE2_RX_P: J18.15 (RX2_P), U8.A3 (MGTYRXN3_227)
/Line card interfaces/LC1_PHY1_LANE2_TX_N: J18.18 (TX2_N), U8.B7 (MGTYTXP3_227)
/Line card interfaces/LC1_PHY1_LANE2_TX_P: J18.16 (TX2_P), U8.B6 (MGTYTXN3_227)
/Line card interfaces/LC1_SPI_CS_N: J19.6, U8.Y16 (IO_L9N_AD3N_84)
/Line card interfaces/LC1_SPI_MISO: J19.8, U8.AD13 (IO_L4P_AD8P_84)
/Line card interfaces/LC1_SPI_MOSI: J19.9, U8.AE13 (IO_L2P_AD10P_84)
/Line card interfaces/LC1_SPI_SCK: J19.7, U8.AB16 (IO_L6N_HDGC_AD6N_84)
/Line card interfaces/QSGMII_REFCLK_AC_N: C97.2, U8.P6 (MGTREFCLK0N_226)
/Line card interfaces/QSGMII_REFCLK_AC_P: C96.2, U8.P7 (MGTREFCLK0P_226)
/Line card interfaces/RC1_N: C97.1, U15.5 (OUT_N)
/Line card interfaces/RC1_P: C96.1, U15.4 (OUT_P)

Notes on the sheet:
Polarity swap
SERDES reference clock
Line card 0
Transceivers
I2C pullups for line card buses are on the card (to 3V3)
MDIO level shifters
Low speed control buses
Line card 1
To line card
Use ARC6-08-12.0-LU-LD-2-1 cable
MDIO/MDC to line cards are LVCMOS25 Everything else is LVCMOS33

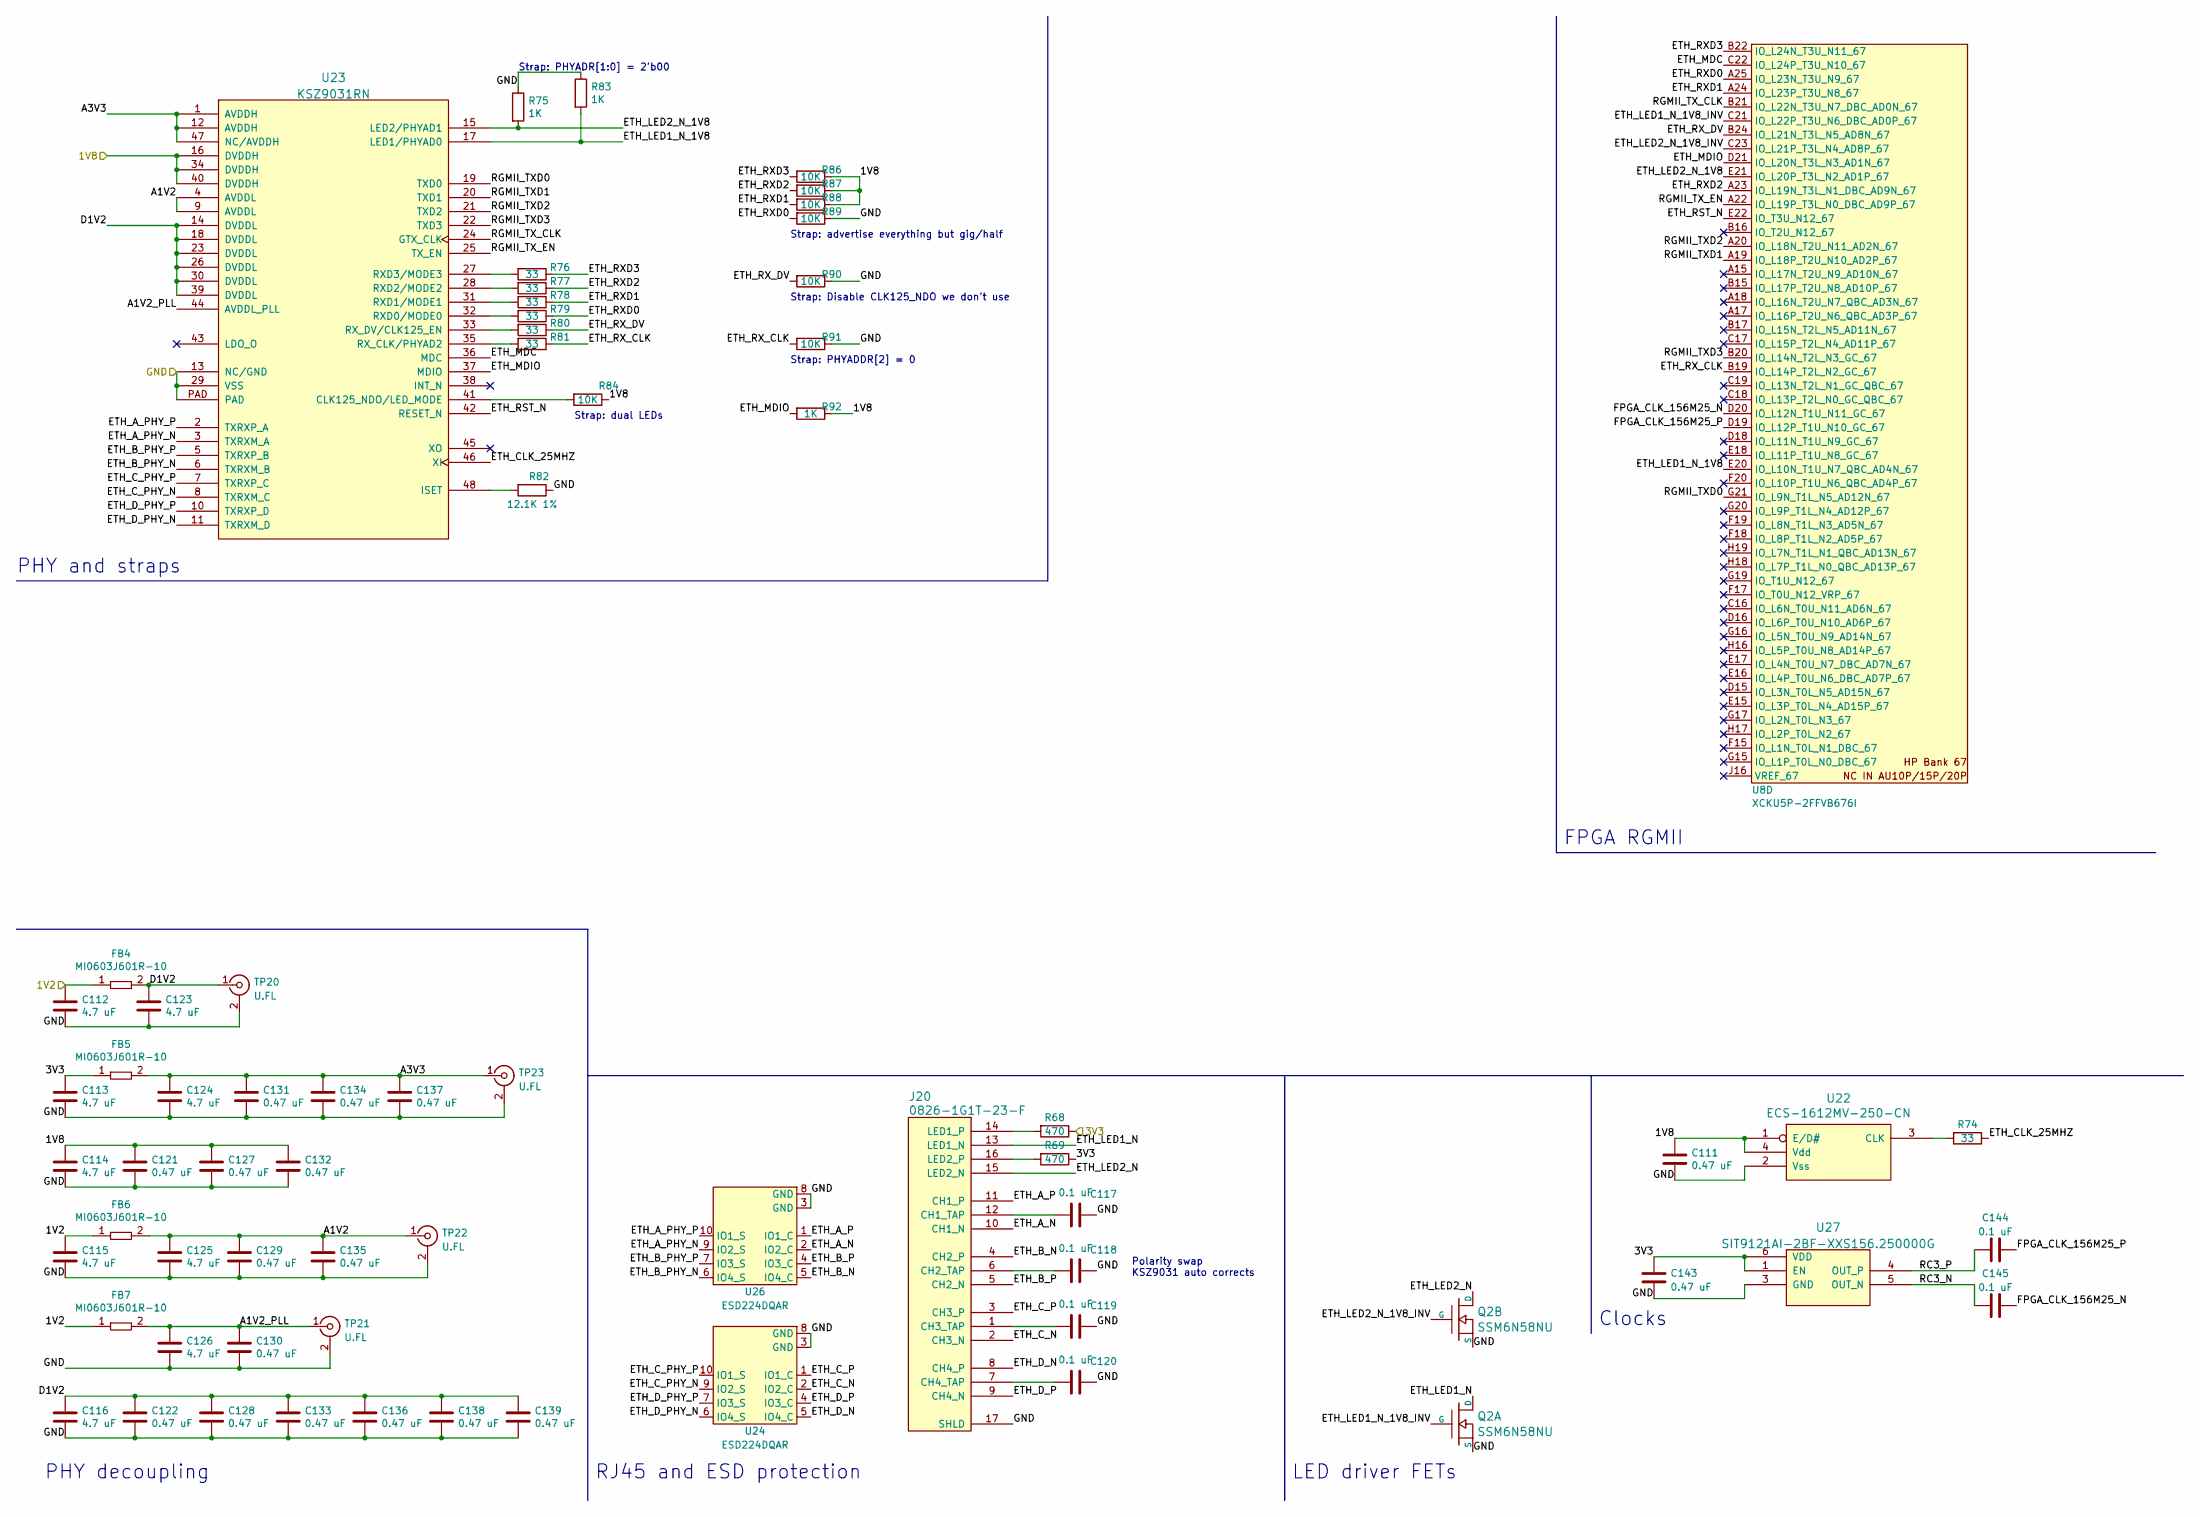
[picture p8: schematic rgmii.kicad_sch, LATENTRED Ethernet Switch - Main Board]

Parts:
C111, C121, C122, C127, C128, C129, C130, C131, C132, C133, C134, C135, C136, C137, C138, C139, C143: 0.47 uF; EIA_0402_CAP_NOSILK
C112, C113, C114, C115, C116, C123, C124, C125, C126: 4.7 uF; EIA_0603_CAP_NOSILK
C117, C118, C119, C120, C144, C145: 0.1 uF; EIA_0402_CAP_NOSILK
FB4, FB5, FB6, FB7: MI0603J601R-10; EIA_0603_INDUCTOR_NOSILK
J20: 0826-1G1T-23-F; CONN_BELFUSE_0826_1G1T_23_F
Q2: SSM6N58NU; DFN_6_0.65MM_2x2MM_GDS
R68, R69: 470; EIA_0402_RES_NOSILK
R74, R76, R77, R78, R79, R80, R81: 33; EIA_0402_RES_NOSILK
R75, R83, R92: 1K; EIA_0402_RES_NOSILK
R82: 12.1K 1%; EIA_0402_RES_NOSILK
R84, R86, R87, R88, R89, R90, R91: 10K; EIA_0402_RES_NOSILK
TP20, TP21, TP22, TP23: U.FL; CONN_U.FL_TE_1909763-1
U8: XCKU5P-2FFVB676I; BGA_676_27x27_FULLARRAY_1MM_FFG676
U22: ECS-1612MV-250-CN; OSCILLATOR_1.6x1.2
U23: KSZ9031RN; QFN_48_0.5MM_7x7MM
U24, U26: ESD224DQAR; DFN_10_0.5MM_2.5x1MM_TI_DQA
U27: SIT9121AI-2BF-XXS156.250000G; OSCILLATOR_LVDS_3.2x2.5

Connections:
/1V8: C111.1, C114.1, C121.1, C127.1, C132.1, R84.1, R86.1, R87.1, R88.1, R92.1, U22.1 (E/D#), U22.4 (Vdd), U23.16 (DVDDH), U23.34 (DVDDH), U23.40 (DVDDH); also elsewhere on the board
/3V3: C113.1, C143.1, FB5.1, R68.1, R69.1, U27.1 (EN), U27.6 (VDD); also elsewhere on the board
/GND: C111.2, C112.2, C113.2, C114.2, C115.2, C116.2, C117.1, C118.1, C119.1, C120.1, C121.2, C122.2, C123.2, C124.2, C125.2, C126.2, C127.2, C128.2, C129.2, C130.2, C131.2, C132.2, C133.2, C134.2, C135.2, C136.2, C137.2, C138.2, C139.2, C143.2, J20.17 (SHLD), Q2.S1 (S), Q2.S2 (S), R75.1, R82.1, R83.1, R89.1, R90.1, R91.1, TP20.2 (Ext), TP21.2 (Ext), TP22.2 (Ext), TP23.2 (Ext), U22.2 (Vss), U23.13 (NC/GND), U23.29 (VSS), U23.PAD, U24.3 (GND), U24.8 (GND), U26.3 (GND), U26.8 (GND), U27.3 (GND); also elsewhere on the board
/GTY_VTT: C112.1, C115.1, FB4.1, FB6.1, FB7.1; also elsewhere on the board
/RGMII PHY/A1V2: C125.1, C129.1, C135.1, FB6.2, TP22.1 (In), U23.4 (AVDDL), U23.9 (AVDDL)
/RGMII PHY/A1V2_PLL: C126.1, C130.1, FB7.2, TP21.1 (In), U23.44 (AVDDL_PLL)
/RGMII PHY/A3V3: C124.1, C131.1, C134.1, C137.1, FB5.2, TP23.1 (In), U23.1 (AVDDH), U23.12 (AVDDH), U23.47 (NC/AVDDH)
/RGMII PHY/D1V2: C116.1, C122.1, C123.1, C128.1, C133.1, C136.1, C138.1, C139.1, FB4.2, TP20.1 (In), U23.14 (DVDDL), U23.18 (DVDDL), U23.23 (DVDDL), U23.26 (DVDDL), U23.30 (DVDDL), U23.39 (DVDDL)
/RGMII PHY/ETH_A_N: J20.10 (CH1_N), U26.2 (IO2_C)
/RGMII PHY/ETH_A_P: J20.11 (CH1_P), U26.1 (IO1_C)
/RGMII PHY/ETH_A_PHY_N: U23.3 (TXRXM_A), U26.9 (IO2_S)
/RGMII PHY/ETH_A_PHY_P: U23.2 (TXRXP_A), U26.10 (IO1_S)
/RGMII PHY/ETH_B_N: J20.4 (CH2_P), U26.5 (IO4_C)
/RGMII PHY/ETH_B_P: J20.5 (CH2_N), U26.4 (IO3_C)
/RGMII PHY/ETH_B_PHY_N: U23.6 (TXRXM_B), U26.6 (IO4_S)
/RGMII PHY/ETH_B_PHY_P: U23.5 (TXRXP_B), U26.7 (IO3_S)
/RGMII PHY/ETH_CLK_25MHZ: R74.1, U23.46 (XI)
/RGMII PHY/ETH_C_N: J20.2 (CH3_N), U24.2 (IO2_C)
/RGMII PHY/ETH_C_P: J20.3 (CH3_P), U24.1 (IO1_C)
/RGMII PHY/ETH_C_PHY_N: U23.8 (TXRXM_C), U24.9 (IO2_S)
/RGMII PHY/ETH_C_PHY_P: U23.7 (TXRXP_C), U24.10 (IO1_S)
/RGMII PHY/ETH_D_N: J20.8 (CH4_P), U24.5 (IO4_C)
/RGMII PHY/ETH_D_P: J20.9 (CH4_N), U24.4 (IO3_C)
/RGMII PHY/ETH_D_PHY_N: U23.11 (TXRXM_D), U24.6 (IO4_S)
/RGMII PHY/ETH_D_PHY_P: U23.10 (TXRXP_D), U24.7 (IO3_S)
/RGMII PHY/ETH_LED1_N: J20.13 (LED1_N), Q2.D1 (D)
/RGMII PHY/ETH_LED1_N_1V8: R83.2, U8.E20 (IO_L10N_T1U_N7_QBC_AD4N_67), U23.17 (LED1/PHYAD0)
/RGMII PHY/ETH_LED1_N_1V8_INV: Q2.G1 (G), U8.C21 (IO_L22P_T3U_N6_DBC_AD0P_67)
/RGMII PHY/ETH_LED2_N: J20.15 (LED2_N), Q2.D2 (D)
/RGMII PHY/ETH_LED2_N_1V8: R75.2, U8.E21 (IO_L20P_T3L_N2_AD1P_67), U23.15 (LED2/PHYAD1)
/RGMII PHY/ETH_LED2_N_1V8_INV: Q2.G2 (G), U8.C23 (IO_L21P_T3L_N4_AD8P_67)
/RGMII PHY/ETH_MDC: U8.C22 (IO_L24P_T3U_N10_67), U23.36 (MDC)
/RGMII PHY/ETH_MDIO: R92.2, U8.D21 (IO_L20N_T3L_N3_AD1N_67), U23.37 (MDIO)
/RGMII PHY/ETH_RST_N: U8.E22 (IO_T3U_N12_67), U23.42 (RESET_N)
/RGMII PHY/ETH_RXD0: R79.1, R89.2, U8.A25 (IO_L23N_T3U_N9_67)
/RGMII PHY/ETH_RXD1: R78.1, R88.2, U8.A24 (IO_L23P_T3U_N8_67)
/RGMII PHY/ETH_RXD2: R77.1, R87.2, U8.A23 (IO_L19N_T3L_N1_DBC_AD9N_67)
/RGMII PHY/ETH_RXD3: R76.1, R86.2, U8.B22 (IO_L24N_T3U_N11_67)
/RGMII PHY/ETH_RX_CLK: R81.1, R91.2, U8.B19 (IO_L14P_T2L_N2_GC_67)
/RGMII PHY/ETH_RX_DV: R80.1, R90.2, U8.B24 (IO_L21N_T3L_N5_AD8N_67)
/RGMII PHY/FPGA_CLK_156M25_N: C145.2, U8.D20 (IO_L12N_T1U_N11_GC_67)
/RGMII PHY/FPGA_CLK_156M25_P: C144.2, U8.D19 (IO_L12P_T1U_N10_GC_67)
/RGMII PHY/RC3_N: C145.1, U27.5 (OUT_N)
/RGMII PHY/RC3_P: C144.1, U27.4 (OUT_P)
/RGMII PHY/RGMII_TXD0: U8.G21 (IO_L9N_T1L_N5_AD12N_67), U23.19 (TXD0)
/RGMII PHY/RGMII_TXD1: U8.A19 (IO_L18P_T2U_N10_AD2P_67), U23.20 (TXD1)
/RGMII PHY/RGMII_TXD2: U8.A20 (IO_L18N_T2U_N11_AD2N_67), U23.21 (TXD2)
/RGMII PHY/RGMII_TXD3: U8.B20 (IO_L14N_T2L_N3_GC_67), U23.22 (TXD3)
/RGMII PHY/RGMII_TX_CLK: U8.B21 (IO_L22N_T3U_N7_DBC_AD0N_67), U23.24 (GTX_CLK)
/RGMII PHY/RGMII_TX_EN: U8.A22 (IO_L19P_T3L_N0_DBC_AD9P_67), U23.25 (TX_EN)
unnamed: C117.2, J20.12 (CH1_TAP)
unnamed: C118.2, J20.6 (CH2_TAP)
unnamed: C119.2, J20.1 (CH3_TAP)
unnamed: C120.2, J20.7 (CH4_TAP)
unnamed: J20.14 (LED1_P), R68.2
unnamed: J20.16 (LED2_P), R69.2
unnamed: R74.2, U22.3 (CLK)
unnamed: R84.2, U23.41 (CLK125_NDO/LED_MODE)
unnamed: R82.2, U23.48 (ISET)
unnamed: R79.2, U23.32 (RXD0/MODE0)
unnamed: R78.2, U23.31 (RXD1/MODE1)
unnamed: R77.2, U23.28 (RXD2/MODE2)
unnamed: R76.2, U23.27 (RXD3/MODE3)
unnamed: R81.2, U23.35 (RX_CLK/PHYAD2)
unnamed: R80.2, U23.33 (RX_DV/CLK125_EN)

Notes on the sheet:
Strap: PHYADDR[2] = 0
Strap: advertise everything but gig/half
Strap: PHYADR[1:0] = 2'b00
Strap: dual LEDs
RJ45 and ESD protection
Polarity swap KSZ9031 auto corrects
LED driver FETs
PHY and straps
FPGA RGMII
Clocks
PHY decoupling
Strap: Disable CLK125_NDO we don't use

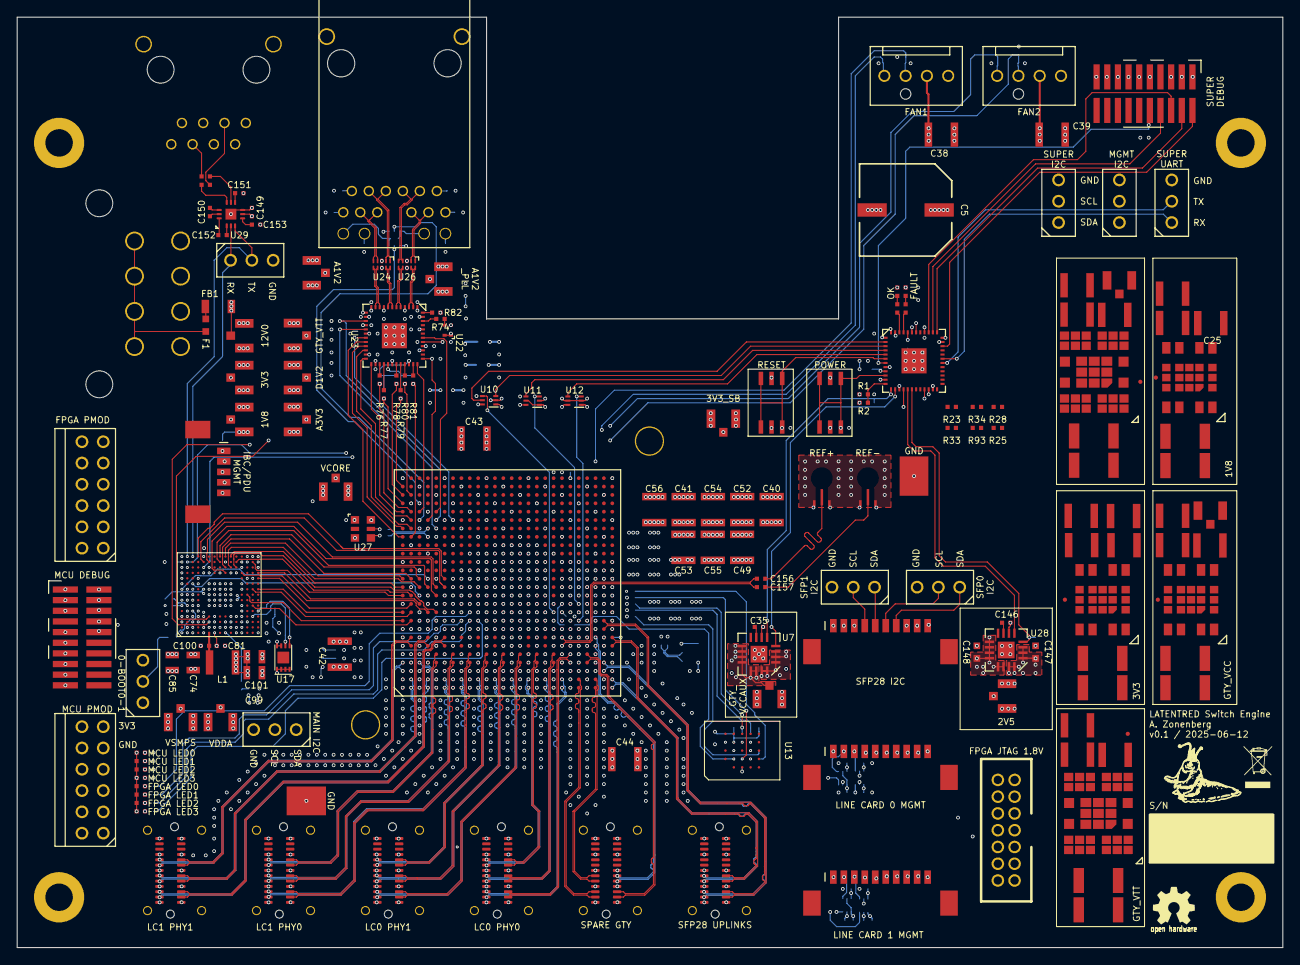
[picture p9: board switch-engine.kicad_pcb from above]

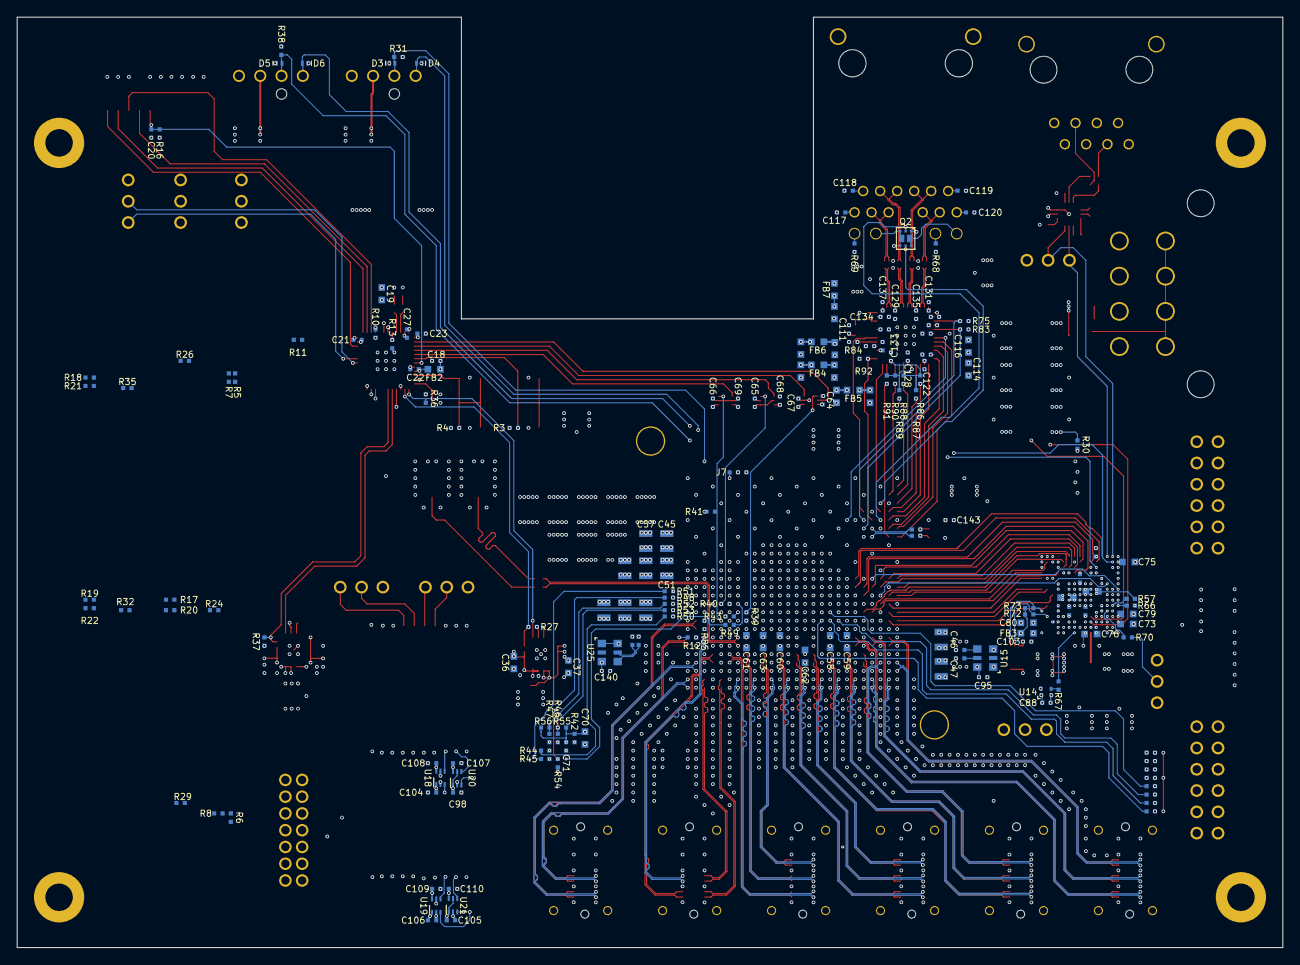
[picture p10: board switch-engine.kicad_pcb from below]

Board: 10 copper layers, 151.0 x 111.0 mm, 369 parts (194 on the bottom side), 358 nets.

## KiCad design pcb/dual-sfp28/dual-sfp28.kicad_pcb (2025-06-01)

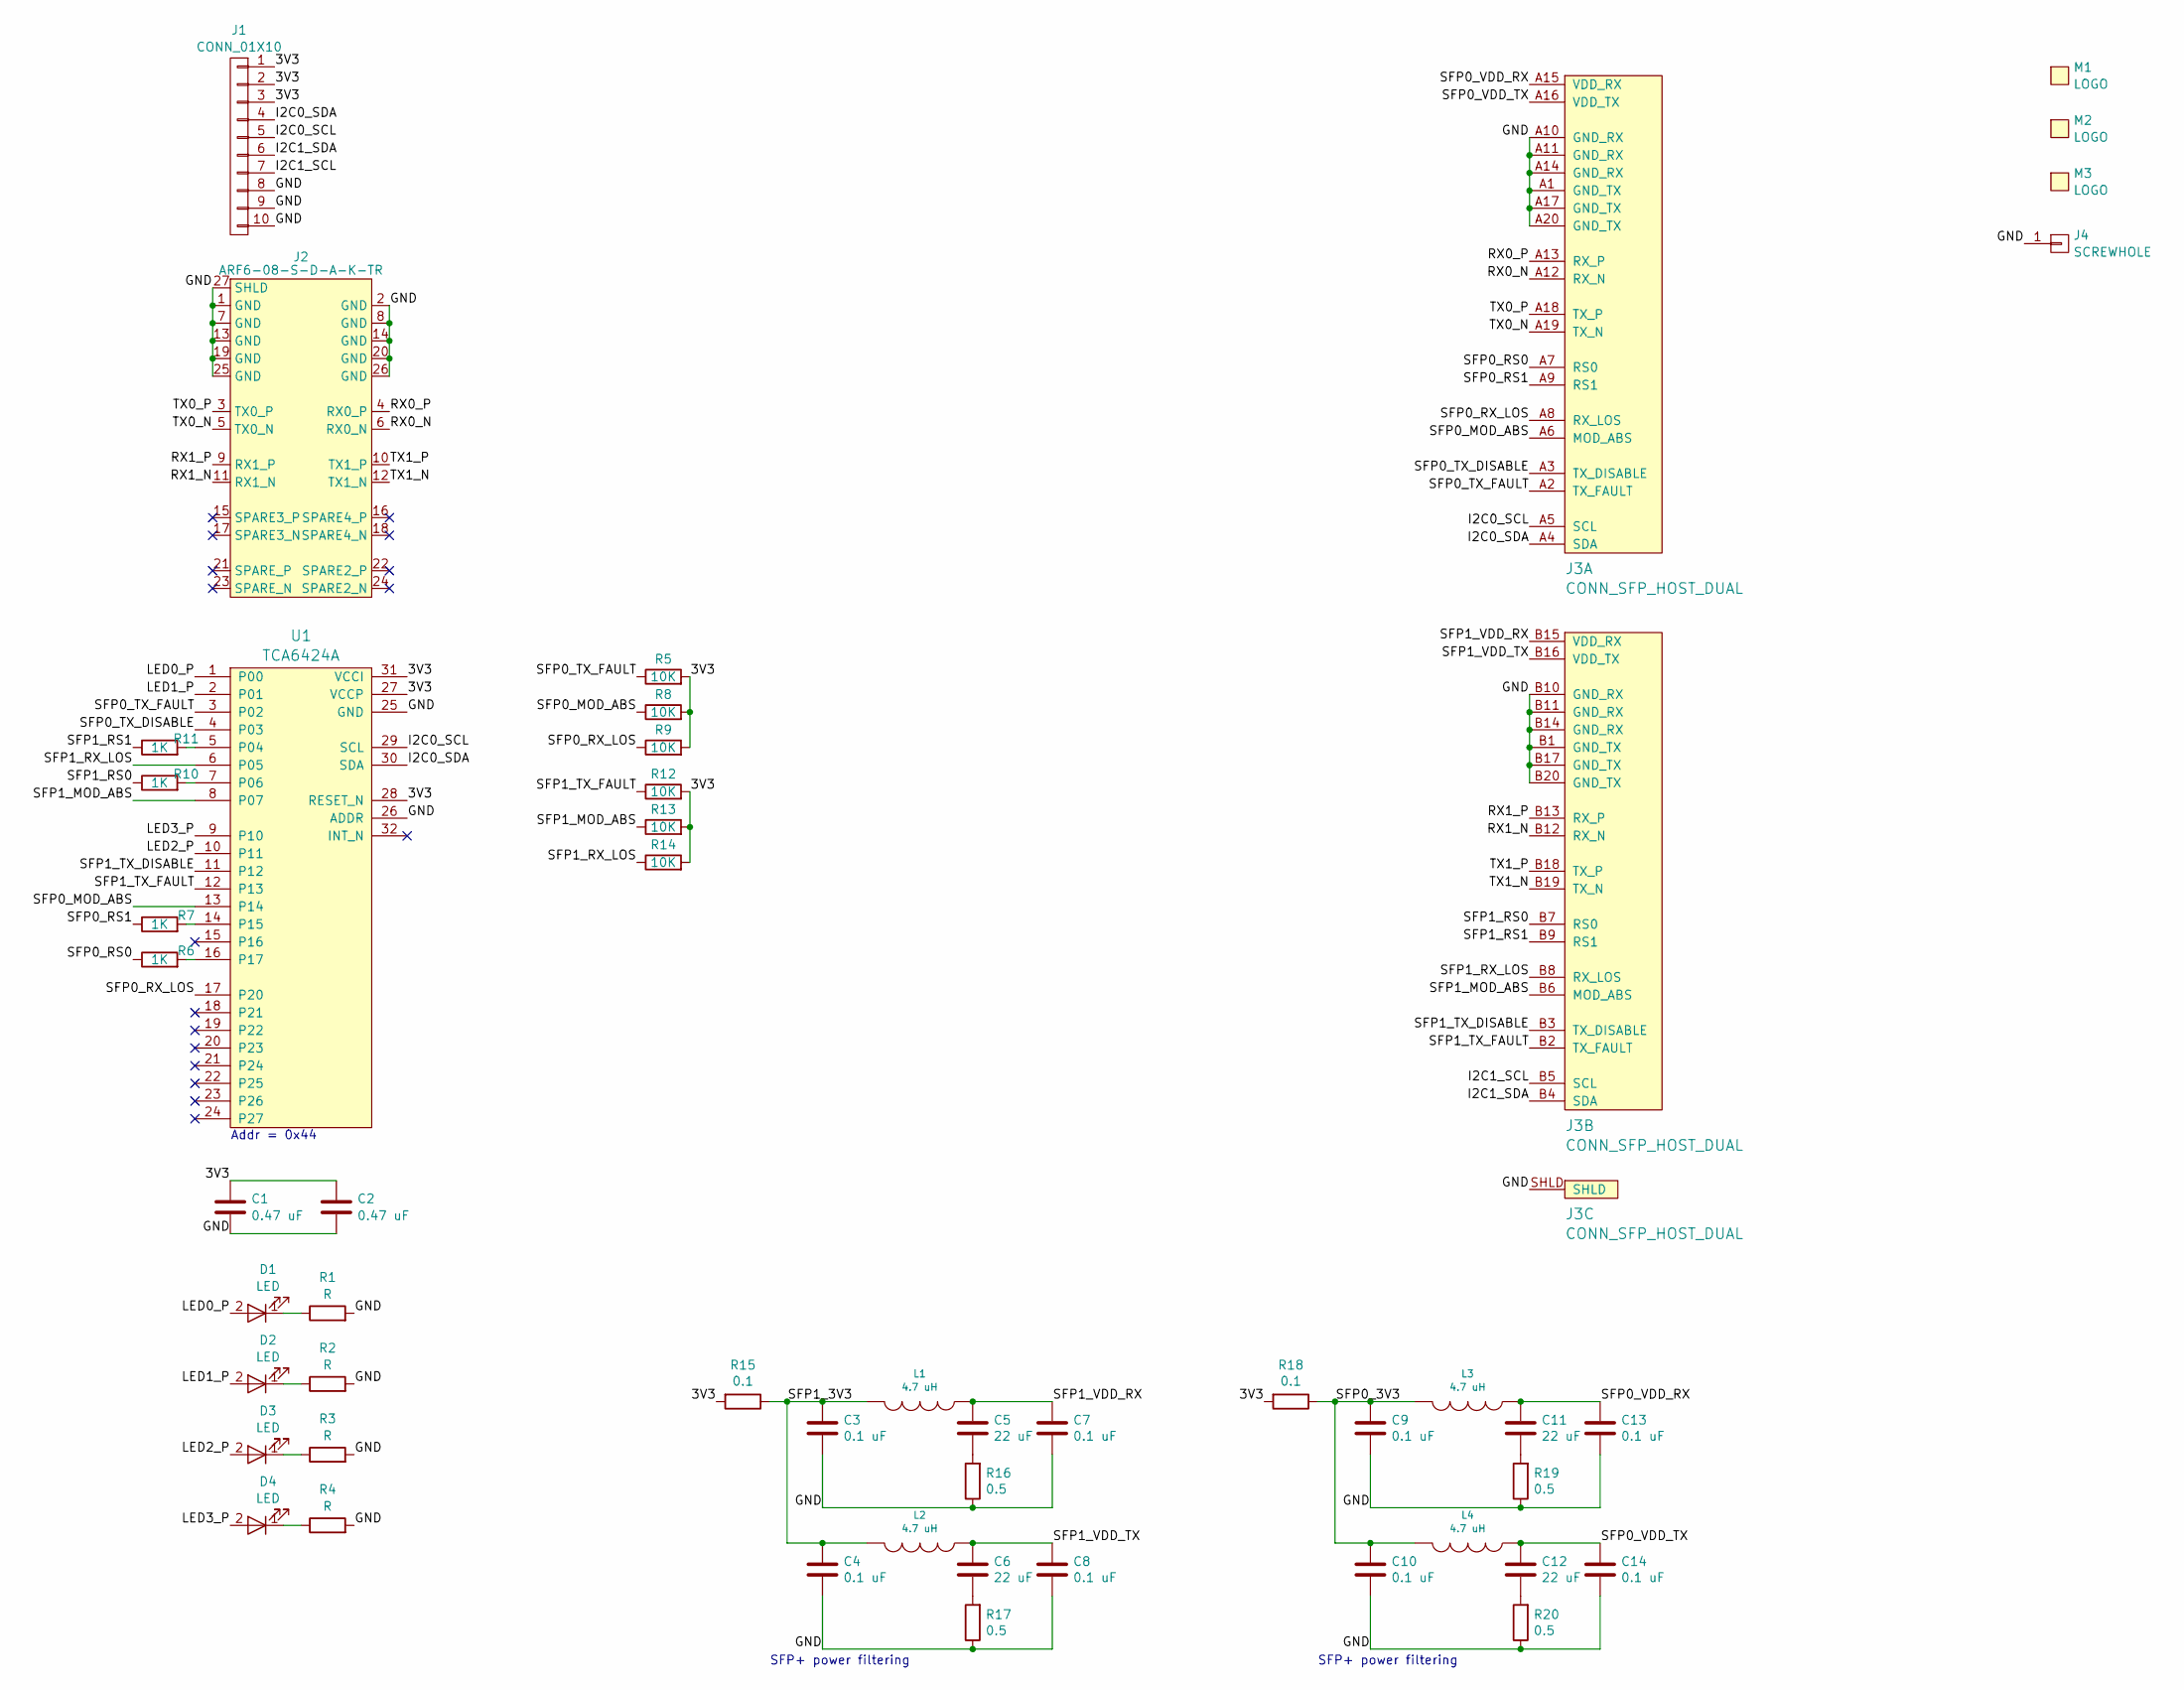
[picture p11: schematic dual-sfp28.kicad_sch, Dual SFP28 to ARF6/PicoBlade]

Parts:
C1, C2: 0.47 uF; EIA_0402_CAP_NOSILK
C3, C4, C7, C8, C9, C10, C13, C14: 0.1 uF; EIA_0402_CAP_NOSILK
C5, C6, C11, C12: 22 uF; EIA_0805_CAP_NOSILK
D1, D2, D3, D4: LED; EIA_0402_LED
J1: CONN_01X10; CONN_MOLEX_PICOBLADE_10POS_0532611071
J2: ARF6-08-S-D-A-K-TR; CONN_SAMTEC_ARF6-08-S-D-A-K-TR
J3: CONN_SFP_HOST_DUAL; CONN_ZSFP_DUAL_MOLEX_1712241011
J4: SCREWHOLE; MECHANICAL_CLEARANCEHOLE_4_40
L1, L2, L3, L4: 4.7 uH; EIA_0805_INDUCTOR_NOSILK
M1: LOGO; LONGTHING-1200DPI
M2: LOGO; Logo_silk_OSHW_6x6mm
M3: LOGO; Logo_silk_WEEE_3.4x5mm
R1, R2, R3, R4: R; EIA_0402_RES_NOSILK
R5, R8, R9, R12, R13, R14: 10K; EIA_0402_RES_NOSILK
R6, R7, R10, R11: 1K; EIA_0402_RES_NOSILK
R15, R18: 0.1; EIA_0402_RES_NOSILK
R16, R17, R19, R20: 0.5; EIA_0402_RES_NOSILK
U1: TCA6424A; QFN_32_0.5MM_5x5MM

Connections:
/3V3: C1.1, C2.1, J1.1, J1.2, J1.3, R5.2, R8.2, R9.2, R12.2, R13.2, R14.2, R15.2, R18.2, U1.27 (VCCP), U1.28 (RESET_N), U1.31 (VCCI)
/GND: C1.2, C2.2, C3.2, C4.2, C7.2, C8.2, C9.2, C10.2, C13.2, C14.2, J1.8, J1.9, J1.10, J2.1 (GND), J2.2 (GND), J2.7 (GND), J2.8 (GND), J2.13 (GND), J2.14 (GND), J2.19 (GND), J2.20 (GND), J2.25 (GND), J2.26 (GND), J2.27 (SHLD), J3.A1 (GND_TX), J3.A10 (GND_RX), J3.A11 (GND_RX), J3.A14 (GND_RX), J3.A17 (GND_TX), J3.A20 (GND_TX), J3.B1 (GND_TX), J3.B10 (GND_RX), J3.B11 (GND_RX), J3.B14 (GND_RX), J3.B17 (GND_TX), J3.B20 (GND_TX), J3.SHLD, J4.1, R1.2, R2.2, R3.2, R4.2, R16.1, R17.1, R19.1, R20.1, U1.25 (GND), U1.26 (ADDR)
/I2C0_SCL: J1.5, J3.A5 (SCL), U1.29 (SCL)
/I2C0_SDA: J1.4, J3.A4 (SDA), U1.30 (SDA)
/I2C1_SCL: J1.7, J3.B5 (SCL)
/I2C1_SDA: J1.6, J3.B4 (SDA)
/LED0_P: D1.2 (A), U1.1 (P00)
/LED1_P: D2.2 (A), U1.2 (P01)
/LED2_P: D3.2 (A), U1.10 (P11)
/LED3_P: D4.2 (A), U1.9 (P10)
/RX0_N: J2.6 (RX0_N), J3.A12 (RX_N)
/RX0_P: J2.4 (RX0_P), J3.A13 (RX_P)
/RX1_N: J2.11 (RX1_N), J3.B12 (RX_N)
/RX1_P: J2.9 (RX1_P), J3.B13 (RX_P)
/SFP0_3V3: C9.1, C10.1, L3.2, L4.2, R18.1
/SFP0_MOD_ABS: J3.A6 (MOD_ABS), R8.1, U1.13 (P14)
/SFP0_RS0: J3.A7 (RS0), R6.1
/SFP0_RS1: J3.A9 (RS1), R7.1
/SFP0_RX_LOS: J3.A8 (RX_LOS), R9.1, U1.17 (P20)
/SFP0_TX_DISABLE: J3.A3 (TX_DISABLE), U1.4 (P03)
/SFP0_TX_FAULT: J3.A2 (TX_FAULT), R5.1, U1.3 (P02)
/SFP0_VDD_RX: C11.1, C13.1, J3.A15 (VDD_RX), L3.1
/SFP0_VDD_TX: C12.1, C14.1, J3.A16 (VDD_TX), L4.1
/SFP1_3V3: C3.1, C4.1, L1.2, L2.2, R15.1
/SFP1_MOD_ABS: J3.B6 (MOD_ABS), R13.1, U1.8 (P07)
/SFP1_RS0: J3.B7 (RS0), R10.1
/SFP1_RS1: J3.B9 (RS1), R11.1
/SFP1_RX_LOS: J3.B8 (RX_LOS), R14.1, U1.6 (P05)
/SFP1_TX_DISABLE: J3.B3 (TX_DISABLE), U1.11 (P12)
/SFP1_TX_FAULT: J3.B2 (TX_FAULT), R12.1, U1.12 (P13)
/SFP1_VDD_RX: C5.1, C7.1, J3.B15 (VDD_RX), L1.1
/SFP1_VDD_TX: C6.1, C8.1, J3.B16 (VDD_TX), L2.1
/TX0_N: J2.5 (TX0_N), J3.A19 (TX_N)
/TX0_P: J2.3 (TX0_P), J3.A18 (TX_P)
/TX1_N: J2.12 (TX1_N), J3.B19 (TX_N)
/TX1_P: J2.10 (TX1_P), J3.B18 (TX_P)
unnamed: C5.2, R16.2
unnamed: C6.2, R17.2
unnamed: C11.2, R19.2
unnamed: C12.2, R20.2
unnamed: D1.1 (K), R1.1
unnamed: D2.1 (K), R2.1
unnamed: D3.1 (K), R3.1
unnamed: D4.1 (K), R4.1
unnamed: R11.2, U1.5 (P04)
unnamed: R10.2, U1.7 (P06)
unnamed: R7.2, U1.14 (P15)
unnamed: R6.2, U1.16 (P17)

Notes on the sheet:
SFP+ power filtering
Addr = 0x44

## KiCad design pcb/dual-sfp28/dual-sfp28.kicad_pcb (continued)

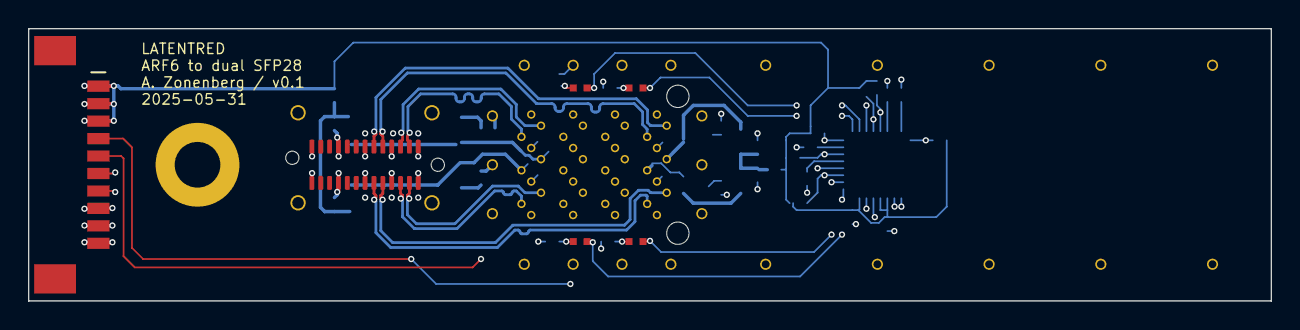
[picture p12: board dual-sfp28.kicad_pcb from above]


Board: 4 copper layers, 89.0 x 19.5 mm, 50 parts (42 on the bottom side), 48 nets.

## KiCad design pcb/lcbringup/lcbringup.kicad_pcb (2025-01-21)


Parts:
M1, M2, M3, M4: SCREWHOLE; MECHANICAL_CLEARANCEHOLE_4_40
M5: MECHANICAL; LONGTHING-1200DPI
M6: MECHANICAL; LOGO_ESD_SENSITIVE_7MM
M7: MECHANICAL; Logo_silk_OSHW_6x6mm
M8: MECHANICAL; Logo_silk_ROHS_5x2.8mm
M9: MECHANICAL; Logo_silk_WEEE_3.4x5mm
TP5: GROUNDCLIP; TESTPOINT_SMT_KEYSTONE_5016

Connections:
/GND: M1.1, M2.1, M3.1, M4.1, TP5.1; also elsewhere on the board


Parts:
C1, C3, C4: 100 uF; EIA_1210_CAP_NOSILK
C2, C7, C8, C13, C14, C17, C18, C19, C21, C22, C23, C24, C25, C26, C27, C28, C29, C33, C34, C35, C36, C62, C63, C67, C92, C98, C99, C100, C101: 0.47 uF; EIA_0402_CAP_NOSILK
C5, C6, C9, C10, C11, C15, C16, C20, C31, C32, C60, C61, C96, C97: 4.7 uF; EIA_0603_CAP_NOSILK
C12: 47 uF; EIA_1210_CAP_NOSILK
D1: GREEN; EIA_0402_LED
J1: XILINX_JTAG; XILINX_JTAG_PTH_MOLEX_0878311420
R1: 33K; EIA_0402_RES_NOSILK
R2: 33; EIA_0402_RES_NOSILK
R3, R4: 4.7K; EIA_0402_RES_NOSILK
U1: XC7A35T-2FGG484C; BGA_484_22x22_FULLARRAY_1MM

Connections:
/1V0: C1.1, C2.1, C5.1, C7.1, C9.1, C12.1, C13.1, C15.1, C18.1, C21.1, C24.1, U1.D6 (MGTAVCC), U1.D10 (MGTAVCC), U1.E8 (MGTAVCC), U1.F7 (MGTAVCC), U1.F9 (MGTAVCC), U1.H8 (VCCINT), U1.H10 (VCCINT), U1.J7 (VCCINT), U1.J9 (VCCINT), U1.J11 (VCCBRAM), U1.K8 (VCCINT), U1.L7 (VCCINT), U1.L11 (VCCBRAM), U1.M8 (VCCINT), U1.N7 (VCCINT), U1.N11 (VCCBRAM), U1.P8 (VCCINT), U1.P10 (VCCINT), U1.R7 (VCCINT), U1.R9 (VCCINT), U1.T8 (VCCINT), U1.T10 (VCCINT); also elsewhere on the board
/1V2: C6.1, C8.1, C14.1, U1.B5 (MGTAVTT), U1.B7 (MGTAVTT), U1.B9 (MGTAVTT), U1.B11 (MGTAVTT), U1.C4 (MGTAVTT), U1.C8 (MGTAVTT); also elsewhere on the board
/1V8: C3.1, C10.1, C16.1, C19.1, C22.1, C25.1, C26.1, C28.1, U1.E12 (VCCBATT), U1.H12 (VCCAUX), U1.K10 (VCCADC), U1.K12 (VCCAUX), U1.M12 (VCCAUX), U1.P12 (VCCAUX), U1.R11 (VCCAUX); also elsewhere on the board
/2V5: C96.1, C97.1, C98.1, C99.1, C100.1, C101.1, U1.AA17 (VCCO_13), U1.AB14 (VCCO_13), U1.V16 (VCCO_13), U1.W13 (VCCO_13), U1.Y10 (VCCO_13); also elsewhere on the board
/3V3: C4.1, C11.1, C17.1, C20.1, C23.1, C27.1, C29.1, C31.1, C32.1, C33.1, C34.1, C35.1, C36.1, C60.1, C61.1, C62.1, C63.1, C67.1, C92.1, J1.2 (Vccaux), R3.1, R4.1, U1.A17 (VCCO_16), U1.AA7 (VCCO_34), U1.AB4 (VCCO_34), U1.B14 (VCCO_16), U1.C1 (VCCO_35), U1.C21 (VCCO_16), U1.D18 (VCCO_16), U1.E15 (VCCO_16), U1.F2 (VCCO_35), U1.F12 (VCCO_0), U1.F22 (VCCO_16), U1.G19 (VCCO_15), U1.H6 (VCCO_35), U1.H16 (VCCO_15), U1.J3 (VCCO_35), U1.J13 (VCCO_15), U1.K20 (VCCO_15), U1.L17 (VCCO_15), U1.M4 (VCCO_35), U1.M14 (VCCO_14), U1.N1 (VCCO_35), U1.N21 (VCCO_15), U1.P18 (VCCO_14), U1.R5 (VCCO_34), U1.R15 (VCCO_14), U1.T2 (VCCO_34), U1.T12 (VCCO_0), U1.T22 (VCCO_14), U1.U8 (CFGBVS), U1.U9 (M2), U1.U11 (M0), U1.U19 (VCCO_14), U1.V6 (VCCO_34), U1.W3 (VCCO_34), U1.Y20 (VCCO_14); also elsewhere on the board
/FPGA support/ARTIX_TCK: J1.6 (TCK), U1.V12 (TCK)
/FPGA support/ARTIX_TDI: J1.10 (TDI_OUT), U1.R13 (TDI)
/FPGA support/ARTIX_TDO: J1.8 (TDO_IN), R2.1
/FPGA support/ARTIX_TMS: J1.4 (TMS), U1.T13 (TMS)
/GND: C1.2, C2.2, C3.2, C4.2, C5.2, C6.2, C7.2, C8.2, C9.2, C10.2, C11.2, C12.2, C13.2, C14.2, C15.2, C16.2, C17.2, C18.2, C19.2, C20.2, C21.2, C22.2, C23.2, C24.2, C25.2, C26.2, C27.2, C28.2, C29.2, C31.2, C32.2, C33.2, C34.2, C35.2, C36.2, C60.2, C61.2, C62.2, C63.2, C67.2, C92.2, C96.2, C97.2, C98.2, C99.2, C100.2, C101.2, D1.1 (K), J1.3 (Vss), J1.5 (Vss), J1.7 (Vss), J1.9 (Vss), J1.11 (Vss), U1.A2 (GND), U1.A3 (GND), U1.A5 (GND), U1.A7 (GND), U1.A9 (GND), U1.A11 (GND), U1.A12 (GND), U1.A22 (GND), U1.AA2 (GND), U1.AA12 (GND), U1.AA22 (GND), U1.AB9 (GND), U1.AB19 (GND), U1.B3 (GND), U1.B12 (GND), U1.B19 (GND), U1.C3 (GND), U1.C6 (GND), U1.C10 (GND), U1.C12 (GND), U1.C16 (GND), U1.D3 (GND), U1.D4 (GND), U1.D8 (GND), U1.D12 (GND), U1.D13 (GND), U1.E4 (GND), U1.E5 (GND), U1.E7 (GND), U1.E9 (GND), U1.E11 (GND), U1.E20 (GND), U1.F5 (GND), U1.F11 (GND), U1.F17 (GND), U1.G5 (GND), U1.G6 (GND), U1.G7 (GND), U1.G8 (GND), U1.G9 (GND), U1.G10 (GND), U1.G12 (GND), U1.G14 (GND), U1.H1 (GND), U1.H7 (GND), U1.H9 (GND), U1.H11 (GND), U1.H21 (GND), U1.J8 (GND), U1.J10 (GND), U1.J12 (GND), U1.J18 (GND), U1.K5 (GND), U1.K7 (GND), U1.K9 (GNDADC), U1.K11 (GND), U1.K15 (GND), U1.L2 (GND), U1.L8 (GND), U1.L9 (XADC_VREF_N), U1.L10 (XADC_VP), U1.L22 (GND), U1.M7 (GND), U1.M9 (XADC_VN), U1.M10 (XADC_VREF_P), U1.M11 (GND), U1.M19 (GND), U1.N6 (GND), U1.N8 (GND), U1.N9 (THERMAL_D_N), U1.N10 (THERMAL_D_P), U1.N16 (GND), U1.P3 (GND), U1.P7 (GND), U1.P9 (GND), U1.P11 (GND), U1.P13 (GND), U1.R8 (GND), U1.R10 (GND), U1.R12 (GND), U1.R20 (GND), U1.T7 (GND), U1.T9 (GND), U1.T11 (GND), U1.T17 (GND), U1.U4 (GND), U1.U10 (M1), U1.U14 (GND), U1.V1 (GND), U1.V11 (GND), U1.V21 (GND), U1.W8 (GND), U1.W18 (GND), U1.Y5 (GND), U1.Y15 (GND); also elsewhere on the board
unnamed: D1.2 (A), R1.1
unnamed: R1.2, U1.G11 (DONE)
unnamed: R3.2, U1.U12 (INIT_B)
unnamed: R4.2, U1.N12 (PROG_B)
unnamed: R2.2, U1.U13 (TDO)

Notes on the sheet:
Strap: 3.3V config, boot from JTAG only
2V5 VCCO (reduced since we're only using two pins for slow MDIO)
VCCAUX
VCCINT
3V3 VCCO (reduced since we're only using some IO banks)
MGTAVTT
VCCBRAM
MGTAVCC


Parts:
C79, C80, C81, C89, C93: 22 uF; EIA_1812_CAP_NOSILK
C82, C83, C84, C85, C86, C87, C90, C91, C94, C95: 22 uF; EIA_1210_CAP_NOSILK
F1: 1A; EIA_0402_RES_NOSILK
FB2: BLM31KN271SN1L; EIA_1206_CAP_NOSILK
J8: CONN_IBC_MGMT; CONN_MOLEX_PICOBLADE_5POS_0532610571
J9: CONN_ATX12V; CONN_MOLEX_MINIFITJR_4POS_0039291048
J23: CONN_IBC_MGMT_HOST; CONN_MOLEX_PICOBLADE_5POS_0532610571
R12, R35, R36, R37, R45: 10K; EIA_0402_RES_NOSILK
R13: 294K; EIA_0402_RES_NOSILK
R14: 93.1K; EIA_0402_RES_NOSILK
R38: 200K; EIA_0402_RES_NOSILK
R39, R40, R41, R46: 100K; EIA_0402_RES_NOSILK
R42: 187K; EIA_0402_RES_NOSILK
R43: 280K; EIA_0402_RES_NOSILK
R44: 1K; EIA_0402_RES_NOSILK
R47: 22.1K; EIA_0402_RES_NOSILK
U5, U6, U9, U10, U11: MUN12AD03-SE; MODULE_CYNTEC_MUN12AD03-SE

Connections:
/1V0: C84.1, C87.1, R42.1, U10.4 (VOUT), U10.5 (VOUT); also elsewhere on the board
/1V2: C83.1, C86.1, R40.1, U9.4 (VOUT), U9.5 (VOUT); also elsewhere on the board
/1V8: C82.1, C85.1, R38.1, U5.4 (VOUT), U5.5 (VOUT); also elsewhere on the board
/2V5: C94.1, C95.1, R13.1, U6.4 (VOUT), U6.5 (VOUT); also elsewhere on the board
/3V3: C90.1, C91.1, R12.2, R35.2, R36.2, R37.2, R45.2, R46.1, U11.4 (VOUT), U11.5 (VOUT); also elsewhere on the board
/3V3_SB: J8.5 (3V3_SB), J23.1 (3V3_SB), R44.1; also elsewhere on the board
/GND: C79.2, C80.2, C81.2, C82.2, C83.2, C84.2, C85.2, C86.2, C87.2, C89.2, C90.2, C91.2, C93.2, C94.2, C95.2, J8.4 (GND), J9.1 (GND), J9.2 (GND), J23.2 (GND), R14.2, R39.2, R41.2, R43.2, R47.2, U5.3 (GND), U5.PAD (GND), U6.3 (GND), U6.PAD (GND), U9.3 (GND), U9.PAD (GND), U10.3 (GND), U10.PAD (GND), U11.3 (GND), U11.PAD (GND); also elsewhere on the board
/Power supply/1V0_FB: R42.2, R43.1, U10.6 (FB)
/Power supply/1V0_PGOOD: R37.1, U10.7 (PGOOD)
/Power supply/1V2_FB: R40.2, R41.1, U9.6 (FB)
/Power supply/1V2_PGOOD: R36.1, U9.7 (PGOOD)
/Power supply/1V8_FB: R38.2, R39.1, U5.6 (FB)
/Power supply/1V8_PGOOD: R35.1, U5.7 (PGOOD)
/Power supply/2V5_FB: R13.2, R14.1, U6.6 (FB)
/Power supply/2V5_PGOOD: R12.1, U6.7 (PGOOD)
/Power supply/3V3_FB: R46.2, R47.1, U11.6 (FB)
/Power supply/3V3_PGOOD: R45.1, U11.7 (PGOOD)
/Power supply/12V0: C79.1, C80.1, C81.1, C89.1, C93.1, FB2.1, U5.1 (EN), U5.2 (VIN), U6.1 (EN), U6.2 (VIN), U9.1 (EN), U9.2 (VIN), U10.1 (EN), U10.2 (VIN), U11.1 (EN), U11.2 (VIN)
/Power supply/12V0_EN: J8.1 (12V0_OUT_EN), J23.5 (12V0_OUT_EN), R44.2
/Power supply/SUPER_I2C_SCL: J8.2 (I2C_SCL), J23.4 (I2C_SCL); also elsewhere on the board
/Power supply/SUPER_I2C_SDA: J8.3 (I2C_SDA), J23.3 (I2C_SDA); also elsewhere on the board
unnamed: F1.1, J9.3 (12V0), J9.4 (12V0)
unnamed: F1.2, FB2.2

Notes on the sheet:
Vout = 0.6 * (1 + RfbT / RfbB) 1.2 = 0.6 * (1 + Rfbt / Rfbb) 2 = 1 + Rfbt / Rfbb 1 = Rfbt / Rfbb So 100K / 100K
Vout = 0.6 * (1 + RfbT / RfbB) 2.5 = 0.6 * (1 + Rtop / Rbot) 4.16 = 1 + Rtop/Rbot 3.16 = Rtop/Rbot 294.0K / 93.1K
No sequencing or anything, just turn everything on immediately Good enough
Vout = 0.6 * (1 + RfbT / RfbB) 3.3 = 0.6 * (1 + Rtop / Rbot) 5.5 = 1 + Rtop/Rbot 4.5 = Rtop/Rbot Datasheet suggests 124k / 27.4K We can do 100k / 22.1k with what we have in stock
Vout = 0.6 * (1 + RfbT / RfbB) 1.0 = 0.6 * (1 + Rfbt / Rfbb) 1.66 = 1 + Rfbt / Rfbb 0.66 = Rfbt / Rfbb 187K / 280K
Vout = 0.6 * (1 + RfbT / RfbB) 1.8 = 0.6 * (1 + Rfbt / Rfbb) 3 = (1 + Rfbt / Rfbb) 2 = Rfbt / Rfbb So 200K / 100K?


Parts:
C30: 0.47 uF; EIA_0402_CAP_NOSILK
D2, D3, D4, D5: GREEN; EIA_0402_LED
J2: CONN_01X10; CONN_MOLEX_PICOBLADE_10POS_0532611071
R5: 0; EIA_0402_RES_NOSILK
R6: 33; EIA_0402_RES_NOSILK
R7, R8, R9, R10: 33K; EIA_0402_RES_NOSILK
U1: XC7A35T-2FGG484C; BGA_484_22x22_FULLARRAY_1MM
U3: ECS-1612MV-250-CN; OSCILLATOR_1.6x1.2

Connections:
/3V3: C30.1, R5.1, U3.1 (E/D#), U3.4 (Vdd); also elsewhere on the board
/GND: C30.2, D2.1 (K), D3.1 (K), D4.1 (K), D5.1 (K), J2.1, J2.10, U3.2 (Vss); also elsewhere on the board
/MCU/I2C_SCL: J2.4; also elsewhere on the board
/MCU/I2C_SDA: J2.5; also elsewhere on the board
/MDIO and GPIO/ARTIX_CLK_25MHZ: R6.1, U1.W19 (IO_L12P_T1_MRCC_14)
/MDIO and GPIO/ARTIX_LED_0: R7.1, U1.AB22 (IO_L10N_T1_D15_14)
/MDIO and GPIO/ARTIX_LED_1: R8.1, U1.AB21 (IO_L10P_T1_D14_14)
/MDIO and GPIO/ARTIX_LED_2: R9.1, U1.AA21 (IO_L8N_T1_D12_14)
/MDIO and GPIO/ARTIX_LED_3: R10.1, U1.AB20 (IO_L15N_T2_DQS_DOUT_CSO_B_14)
/MDIO and GPIO/MDC: J2.2, U1.AB17 (IO_L2N_T0_13)
/MDIO and GPIO/MDIO: J2.3, U1.AB16 (IO_L2P_T0_13)
/MDIO and GPIO/SPI_CS_N: J2.6, U1.R22 (IO_L1N_T0_D01_DIN_14)
/MDIO and GPIO/SPI_MISO: J2.8, U1.V22 (IO_L3N_T0_DQS_EMCCLK_14)
/MDIO and GPIO/SPI_MOSI: J2.9, U1.Y22 (IO_L9N_T1_DQS_D13_14)
/MDIO and GPIO/SPI_SCK: J2.7, U1.W22 (IO_L7N_T1_D10_14)
unnamed: D2.2 (A), R7.2
unnamed: D3.2 (A), R8.2
unnamed: D4.2 (A), R9.2
unnamed: D5.2 (A), R10.2
unnamed: R5.2, U1.U22 (IO_L3P_T0_DQS_PUDC_B_14)
unnamed: R6.2, U3.3 (CLK)

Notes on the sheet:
To line card
MDIO and MDC are LVCMOS25! Everything else is LVCMOS33


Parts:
J10, J12, J13, J14, J15, J16, J17, J18, J19, J20, J21, J22: SMPM; CONN_SMPM_AMPHENOL_C925-197J-51PT
J11: ARF6-08-S-D-A-K-TR; CONN_SAMTEC_ARF6-08-S-D-A-K-TR

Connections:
/ARF6 breakout/QSGMII_RX0_N: J11.5 (RX0_N), J18.1 (In)
/ARF6 breakout/QSGMII_RX0_P: J11.3 (RX0_P), J17.1 (In)
/ARF6 breakout/QSGMII_RX1_N: J11.11 (RX1_N), J20.1 (In)
/ARF6 breakout/QSGMII_RX1_P: J11.9 (RX1_P), J19.1 (In)
/ARF6 breakout/QSGMII_RX2_N: J11.17 (RX2_N), J22.1 (In)
/ARF6 breakout/QSGMII_RX2_P: J11.15 (RX2_P), J21.1 (In)
/ARF6 breakout/QSGMII_TX0_N: J11.6 (TX0_N), J12.1 (In)
/ARF6 breakout/QSGMII_TX0_P: J10.1 (In), J11.4 (TX0_P)
/ARF6 breakout/QSGMII_TX1_N: J11.12 (TX1_N), J14.1 (In)
/ARF6 breakout/QSGMII_TX1_P: J11.10 (TX1_P), J13.1 (In)
/ARF6 breakout/QSGMII_TX2_N: J11.18 (TX2_N), J16.1 (In)
/ARF6 breakout/QSGMII_TX2_P: J11.16 (TX2_P), J15.1 (In)
/GND: J10.2 (Ext), J11.1 (GND), J11.2 (GND), J11.7 (GND), J11.8 (GND), J11.13 (GND), J11.14 (GND), J11.19 (GND), J11.20 (GND), J11.25 (GND), J11.26 (GND), J11.27 (SHLD), J12.2 (Ext), J13.2 (Ext), J14.2 (Ext), J15.2 (Ext), J16.2 (Ext), J17.2 (Ext), J18.2 (Ext), J19.2 (Ext), J20.2 (Ext), J21.2 (Ext), J22.2 (Ext); also elsewhere on the board

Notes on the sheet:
Use ARC6-08-12.0-LU-LD-2-1 cable

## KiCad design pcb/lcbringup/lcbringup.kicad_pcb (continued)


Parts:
C37, C38, C40, C41, C43, C44, C45: 4.7 uF; EIA_0603_CAP_NOSILK
C39, C64, C66: 10 uF; EIA_0805_CAP_NOSILK
C42, C46, C47, C48, C49, C51, C52, C53, C54, C55, C56, C57, C58, C59, C68: 0.47 uF; EIA_0402_CAP_NOSILK
C50: 22 uF; EIA_0805_CAP_NOSILK
C65: 220 pF; EIA_0402_CAP_NOSILK
C78: 0.1 uF; EIA_0402_CAP_NOSILK
D10, D11, D12, D13: GREEN; EIA_0402_LED
FB1: MI0603J601R-10; EIA_0603_INDUCTOR_NOSILK
J4: CORTEX_DEBUG_ETM; CONN_HEADER_1.27MM_2x10_SMT_SAMTEC_FTSH-110-01-L-DV-K
J5: CONN_01X03; CONN_HEADER_2.54MM_1x3_REFLOW
L1: 2.2 uH; EIA_1210_CAP_NOSILK
R11, R24: 10K; EIA_0402_RES_NOSILK
R16, R17, R18, R19: 33K; EIA_0402_RES_NOSILK
R20, R21: 33; EIA_0402_RES_NOSILK
R26, R27: 4.7K; EIA_0402_RES_NOSILK
R34: DNP; EIA_0402_RES_NOSILK
TP1: CONN_01X03; CONN_HEADER_2.54MM_1x3_REFLOW
TP2, TP3, TP4: U.FL; CONN_U.FL_TE_1909763-1
U1: XC7A35T-2FGG484C; BGA_484_22x22_FULLARRAY_1MM
U2: STM32H735-UFBGA176-25; BGA_201_10x10_DEPOP_0.65MM_OSHPARK
U4: ECS-1612MV-250-CN; OSCILLATOR_1.6x1.2
U7: AT24MAC402; DFN_8_0.5MM_2x3MM_TALL
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

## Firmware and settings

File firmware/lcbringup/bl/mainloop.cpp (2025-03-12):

/***********************************************************************************************************************
*                                                                                                                      *
* LATENTRED                                                                                                            *
*                                                                                                                      *
* Copyright (c) 2023-2025 Andrew D. Zonenberg and contributors                                                         *
* All rights reserved.                                                                                                 *
*                                                                                                                      *
* Redistribution and use in source and binary forms, with or without modification, are permitted provided that the     *
* following conditions are met:                                                                                        *
*                                                                                                                      *
*    * Redistributions of source code must retain the above copyright notice, this list of conditions, and the         *
*      following disclaimer.                                                                                           *
*                                                                                                                      *
*    * Redistributions in binary form must reproduce the above copyright notice, this list of conditions and the       *
*      following disclaimer in the documentation and/or other materials provided with the distribution.                *
*                                                                                                                      *
*    * Neither the name of the author nor the names of any contributors may be used to endorse or promote products     *
*      derived from this software without specific prior written permission.                                           *
*                                                                                                                      *
* THIS SOFTWARE IS PROVIDED BY THE AUTHORS "AS IS" AND ANY EXPRESS OR IMPLIED WARRANTIES, INCLUDING, BUT NOT LIMITED   *
* TO, THE IMPLIED WARRANTIES OF MERCHANTABILITY AND FITNESS FOR A PARTICULAR PURPOSE ARE DISCLAIMED. IN NO EVENT SHALL *
* THE AUTHORS BE HELD LIABLE FOR ANY DIRECT, INDIRECT, INCIDENTAL, SPECIAL, EXEMPLARY, OR CONSEQUENTIAL DAMAGES        *
* (INCLUDING, BUT NOT LIMITED TO, PROCUREMENT OF SUBSTITUTE GOODS OR SERVICES; LOSS OF USE, DATA, OR PROFITS; OR       *
* BUSINESS INTERRUPTION) HOWEVER CAUSED AND ON ANY THEORY OF LIABILITY, WHETHER IN CONTRACT, STRICT LIABILITY, OR TORT *
* (INCLUDING NEGLIGENCE OR OTHERWISE) ARISING IN ANY WAY OUT OF THE USE OF THIS SOFTWARE, EVEN IF ADVISED OF THE       *
* POSSIBILITY OF SUCH DAMAGE.                                                                                          *
*                                                                                                                      *
***********************************************************************************************************************/

#include "bootloader.h"
/*#include "BootloaderUDPProtocol.h"
#include "BootloaderTCPProtocol.h"
#include "BootloaderCLISessionContext.h"*/

//Application region of flash runs from the end of the bootloader (0x8020000)
//to the start of the KVS (0x080c0000), so 640 kB
//Firmware version string is put right after vector table by linker script at a constant address
uint32_t* const g_appVector  = reinterpret_cast<uint32_t*>(0x8020000);

//Offset of the version string (size of the vector table plus 32 byte alignment)
const uint32_t g_appVersionOffset = 0x2e0;

///@brief Output stream for local serial console
UARTOutputStream g_localConsoleOutputStream;
/*
///@brief Context data structure for local serial console
BootloaderCLISessionContext g_localConsoleSessionContext;

///@brief The SSH server
BootloaderSSHTransportServer* g_sshd = nullptr;
*/

extern bool g_bootAppPending;
extern uint32_t g_bootAppTimer;

///@brief Number of sectors in the image
const uint32_t g_flashSectorCount = 5;

///@brief Size of a sector
const uint32_t g_flashSectorSize = 128 * 1024;

///@brief Size of the image
const uint32_t g_appImageSize = g_flashSectorCount * g_flashSectorSize;

////////////////////////////////////////////////////////////////////////////////////////////////////////////////////////
// Hooks called by bootloader code

void Bootloader_Init()
{
	/*
	DoInitKVS();
	InitQSPI();
	InitFPGA();
	InitI2C();
	InitEEPROM();
	InitSFP();
	InitManagementPHY();
	InitEthernet();
	InitIP();

	RTC::Unlock();

	//Initialize the FPGA IRQ pin
	g_irq.SetPullMode(GPIOPin::PULL_DOWN);

	//Initialize the local console
	g_localConsoleOutputStream.Initialize(&g_cliUART);
	g_localConsoleSessionContext.Initialize(&g_localConsoleOutputStream, "localadmin");
	*/
}

void Bootloader_ClearRxBuffer()
{
}

void Bootloader_FinalCleanup()
{
	g_cliUART.Flush();
}

void BSP_MainLoop()
{
	Bootloader_MainLoop();
}

/*
void RegisterProtocolHandlers(IPv4Protocol& ipv4)
{
	static BootloaderTCPProtocol tcp(&ipv4);
	static BootloaderUDPProtocol udp(&ipv4);
	ipv4.UseTCP(&tcp);
	ipv4.UseUDP(&udp);
	g_dhcpClient = &udp.GetDHCP();
}*/

////////////////////////////////////////////////////////////////////////////////////////////////////////////////////////
// Run the firmware updater

void __attribute__((noreturn)) Bootloader_FirmwareUpdateFlow()
{
	g_log("In DFU mode\n");

	//Show the initial prompt
	//g_localConsoleSessionContext.PrintPrompt();

	while(1)
	{
		/*
		//Main event loop
		static uint32_t next1HzTick = 0;
		static uint32_t next10HzTick = 0;
		static uint32_t nextPhyPoll = 0;
		const uint32_t logTimerMax = 0xf0000000;

		//Wait for an interrupt
		//asm("wfi");

		//Check if anything happened on the FPGA
		CheckForFPGAEvents();

		//Check if we had a PHY link state change at 20 Hz
		//TODO: add irq bit for this so we don't have to poll nonstop
		if(g_logTimer.GetCount() >= nextPhyPoll)
		{
			PollPHYs();
			nextPhyPoll = g_logTimer.GetCount() + 500;
		}

		//Check if we had an optic inserted or removed
		PollSFP();

		//Poll for UART input
		if(g_cliUART.HasInput())
			g_localConsoleSessionContext.OnKeystroke(g_cliUART.BlockingRead());

		if(g_log.UpdateOffset(logTimerMax))
		{
			next1HzTick -= logTimerMax;
			next10HzTick -= logTimerMax;
		}

		//Refresh of TCP retransmits at 10 Hz
		if(g_logTimer.GetCount() >= next10HzTick)
		{
			g_ethProtocol->OnAgingTick10x();
			next10HzTick = g_logTimer.GetCount() + 1000;

			//also do boot-application timeout
			if(g_bootAppPending)
			{
				g_bootAppTimer --;
				if(g_bootAppTimer == 0)
				{
					if(ValidateAppPartition(g_appVector))
						BootApplication(g_appVector);
					else
						g_log(Logger::ERROR, "Application partition failed to boot\n");

					g_bootAppPending = false;
				}
			}
		}

		//1 Hz timer for various aging processes
		if(g_logTimer.GetCount() >= next1HzTick)
		{
			g_ethProtocol->OnAgingTick();
			next1HzTick = g_logTimer.GetCount() + 10000;
		}
		*/
	}
}

void RegisterProtocolHandlers(IPv4Protocol& ipv4)
{
	//TODO
}

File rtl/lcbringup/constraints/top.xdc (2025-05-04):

set_max_delay -datapath_only -from [get_cells [list apb1/devinfo/sync_die_serial/sync_en/rx_a_ff_reg apb1/devinfo/sync_idcode/sync_en/rx_a_ff_reg bridge/sync_apb_ack/sync_en/rx_a_ff_reg bridge/sync_apb_completion/sync_en/rx_a_ff_reg]] -to [get_cells [list {apb1/devinfo/sync_die_serial/reg_b_reg[0]} \
          {apb1/devinfo/sync_die_serial/reg_b_reg[10]} \
          {apb1/devinfo/sync_die_serial/reg_b_reg[11]} \
          {apb1/devinfo/sync_die_serial/reg_b_reg[12]} \
          {apb1/devinfo/sync_die_serial/reg_b_reg[13]} \
          {apb1/devinfo/sync_die_serial/reg_b_reg[14]} \
          {apb1/devinfo/sync_die_serial/reg_b_reg[15]} \
          {apb1/devinfo/sync_die_serial/reg_b_reg[16]} \
          {apb1/devinfo/sync_die_serial/reg_b_reg[17]} \
          {apb1/devinfo/sync_die_serial/reg_b_reg[18]} \
          {apb1/devinfo/sync_die_serial/reg_b_reg[19]} \
          {apb1/devinfo/sync_die_serial/reg_b_reg[1]} \
          {apb1/devinfo/sync_die_serial/reg_b_reg[20]} \
          {apb1/devinfo/sync_die_serial/reg_b_reg[21]} \
          {apb1/devinfo/sync_die_serial/reg_b_reg[22]} \
          {apb1/devinfo/sync_die_serial/reg_b_reg[23]} \
          {apb1/devinfo/sync_die_serial/reg_b_reg[24]} \
          {apb1/devinfo/sync_die_serial/reg_b_reg[25]} \
          {apb1/devinfo/sync_die_serial/reg_b_reg[26]} \
          {apb1/devinfo/sync_die_serial/reg_b_reg[27]} \
          {apb1/devinfo/sync_die_serial/reg_b_reg[28]} \
          {apb1/devinfo/sync_die_serial/reg_b_reg[29]} \
          {apb1/devinfo/sync_die_serial/reg_b_reg[2]} \
          {apb1/devinfo/sync_die_serial/reg_b_reg[30]} \
          {apb1/devinfo/sync_die_serial/reg_b_reg[31]} \
          {apb1/devinfo/sync_die_serial/reg_b_reg[32]} \
          {apb1/devinfo/sync_die_serial/reg_b_reg[33]} \
          {apb1/devinfo/sync_die_serial/reg_b_reg[34]} \
          {apb1/devinfo/sync_die_serial/reg_b_reg[35]} \
          {apb1/devinfo/sync_die_serial/reg_b_reg[36]} \
          {apb1/devinfo/sync_die_serial/reg_b_reg[37]} \
          {apb1/devinfo/sync_die_serial/reg_b_reg[38]} \
          {apb1/devinfo/sync_die_serial/reg_b_reg[39]} \
          {apb1/devinfo/sync_die_serial/reg_b_reg[3]} \
          {apb1/devinfo/sync_die_serial/reg_b_reg[40]} \
          {apb1/devinfo/sync_die_serial/reg_b_reg[41]} \
          {apb1/devinfo/sync_die_serial/reg_b_reg[42]} \
          {apb1/devinfo/sync_die_serial/reg_b_reg[43]} \
          {apb1/devinfo/sync_die_serial/reg_b_reg[44]} \
          {apb1/devinfo/sync_die_serial/reg_b_reg[45]} \
          {apb1/devinfo/sync_die_serial/reg_b_reg[46]} \
          {apb1/devinfo/sync_die_serial/reg_b_reg[47]} \
          {apb1/devinfo/sync_die_serial/reg_b_reg[48]} \
          {apb1/devinfo/sync_die_serial/reg_b_reg[49]} \
          {apb1/devinfo/sync_die_serial/reg_b_reg[4]} \
          {apb1/devinfo/sync_die_serial/reg_b_reg[50]} \
          {apb1/devinfo/sync_die_serial/reg_b_reg[51]} \
          {apb1/devinfo/sync_die_serial/reg_b_reg[52]} \
          {apb1/devinfo/sync_die_serial/reg_b_reg[53]} \
          {apb1/devinfo/sync_die_serial/reg_b_reg[54]} \
          {apb1/devinfo/sync_die_serial/reg_b_reg[55]} \
          {apb1/devinfo/sync_die_serial/reg_b_reg[56]} \
          {apb1/devinfo/sync_die_serial/reg_b_reg[57]} \
          {apb1/devinfo/sync_die_serial/reg_b_reg[58]} \
          {apb1/devinfo/sync_die_serial/reg_b_reg[59]} \
          {apb1/devinfo/sync_die_serial/reg_b_reg[5]} \
          {apb1/devinfo/sync_die_serial/reg_b_reg[60]} \
          {apb1/devinfo/sync_die_serial/reg_b_reg[61]} \
          {apb1/devinfo/sync_die_serial/reg_b_reg[62]} \
          {apb1/devinfo/sync_die_serial/reg_b_reg[63]} \
          {apb1/devinfo/sync_die_serial/reg_b_reg[6]} \
          {apb1/devinfo/sync_die_serial/reg_b_reg[7]} \
          {apb1/devinfo/sync_die_serial/reg_b_reg[8]} \
          {apb1/devinfo/sync_die_serial/reg_b_reg[9]} \
          {apb1/devinfo/sync_idcode/reg_b_reg[0]} \
          {apb1/devinfo/sync_idcode/reg_b_reg[10]} \
          {apb1/devinfo/sync_idcode/reg_b_reg[11]} \
          {apb1/devinfo/sync_idcode/reg_b_reg[12]} \
          {apb1/devinfo/sync_idcode/reg_b_reg[13]} \
          {apb1/devinfo/sync_idcode/reg_b_reg[14]} \
          {apb1/devinfo/sync_idcode/reg_b_reg[15]} \
          {apb1/devinfo/sync_idcode/reg_b_reg[16]} \
          {apb1/devinfo/sync_idcode/reg_b_reg[17]} \
          {apb1/devinfo/sync_idcode/reg_b_reg[18]} \
          {apb1/devinfo/sync_idcode/reg_b_reg[19]} \
          {apb1/devinfo/sync_idcode/reg_b_reg[1]} \
          {apb1/devinfo/sync_idcode/reg_b_reg[20]} \
          {apb1/devinfo/sync_idcode/reg_b_reg[21]} \
          {apb1/devinfo/sync_idcode/reg_b_reg[22]} \
          {apb1/devinfo/sync_idcode/reg_b_reg[23]} \
          {apb1/devinfo/sync_idcode/reg_b_reg[24]} \
          {apb1/devinfo/sync_idcode/reg_b_reg[25]} \
          {apb1/devinfo/sync_idcode/reg_b_reg[26]} \
          {apb1/devinfo/sync_idcode/reg_b_reg[27]} \
          {apb1/devinfo/sync_idcode/reg_b_reg[28]} \
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

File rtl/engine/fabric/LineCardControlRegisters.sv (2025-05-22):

`timescale 1ns / 1ps
`default_nettype none
/***********************************************************************************************************************
*                                                                                                                      *
* LATENTRED                                                                                                            *
*                                                                                                                      *
* Copyright (c) 2012-2025 Andrew D. Zonenberg                                                                          *
* All rights reserved.                                                                                                 *
*                                                                                                                      *
* Redistribution and use in source and binary forms, with or without modification, are permitted provided that the     *
* following conditions are met:                                                                                        *
*                                                                                                                      *
*    * Redistributions of source code must retain the above copyright notice, this list of conditions, and the         *
*      following disclaimer.                                                                                           *
*                                                                                                                      *
*    * Redistributions in binary form must reproduce the above copyright notice, this list of conditions and the       *
*      following disclaimer in the documentation and/or other materials provided with the distribution.                *
*                                                                                                                      *
*    * Neither the name of the author nor the names of any contributors may be used to endorse or promote products     *
*      derived from this software without specific prior written permission.                                           *
*                                                                                                                      *
* THIS SOFTWARE IS PROVIDED BY THE AUTHORS "AS IS" AND ANY EXPRESS OR IMPLIED WARRANTIES, INCLUDING, BUT NOT LIMITED   *
* TO, THE IMPLIED WARRANTIES OF MERCHANTABILITY AND FITNESS FOR A PARTICULAR PURPOSE ARE DISCLAIMED. IN NO EVENT SHALL *
* THE AUTHORS BE HELD LIABLE FOR ANY DIRECT, INDIRECT, INCIDENTAL, SPECIAL, EXEMPLARY, OR CONSEQUENTIAL DAMAGES        *
* (INCLUDING, BUT NOT LIMITED TO, PROCUREMENT OF SUBSTITUTE GOODS OR SERVICES; LOSS OF USE, DATA, OR PROFITS; OR       *
* BUSINESS INTERRUPTION) HOWEVER CAUSED AND ON ANY THEORY OF LIABILITY, WHETHER IN CONTRACT, STRICT LIABILITY, OR TORT *
* (INCLUDING NEGLIGENCE OR OTHERWISE) ARISING IN ANY WAY OUT OF THE USE OF THIS SOFTWARE, EVEN IF ADVISED OF THE       *
* POSSIBILITY OF SUCH DAMAGE.                                                                                          *
*                                                                                                                      *
***********************************************************************************************************************/

/**
	@brief Control registers for a single LATENTRED line card

	Moved into its own module since most of these get used in multiple places
 */
module LineCardControlRegisters(

	//The APB bus
	APB.completer 			apb,

	//Control registers
	output logic[11:0]		port_vlan[23:0],
	output logic			port_drop_tagged[23:0],
	output logic			port_drop_untagged[23:0]
);

	////////////////////////////////////////////////////////////////////////////////////////////////////////////////////
	// Sanity check

	if(apb.DATA_WIDTH != 32)
		apb_bus_width_is_invalid();

	////////////////////////////////////////////////////////////////////////////////////////////////////////////////////
	// Tie off unused APB signals

	assign apb.pruser = 0;
	assign apb.pbuser = 0;

	////////////////////////////////////////////////////////////////////////////////////////////////////////////////////
	// Clear everything on POR

	initial begin

		//Default configuration for TESTING until firmware knows how to talk to this
		for(integer i=0; i<24; i=i+1) begin
			port_vlan[i]			= 5;
			port_drop_tagged[i]		= 0;
			port_drop_untagged[i]	= 0;
		end

	end

	////////////////////////////////////////////////////////////////////////////////////////////////////////////////////
	// Register IDs

	/*
		We have 1 kB of total address space to work with (0x400 bytes or 256 32-bit words)
		With 24 ports this is enough for a maximum of ten registers per port, but this doesn't divide evenly
		If we use power of two alignment, allocate 32 ports of address space with 8 registers per port
	 */
	typedef enum logic[2:0]
	{
		REG_VLAN_CFG	= 'h00,		//31	drop tagged
									//30	drop untagged
									//11:0	port vlan ID

		//7 more register IDs reserved for future use

		REG_MAX			= 'h01
	} regid_t;

	wire[4:0]	port_id;
	wire[2:0]	reg_id;

	assign port_id	= apb.paddr[9:5];
	assign reg_id	= apb.paddr[4:2];

	////////////////////////////////////////////////////////////////////////////////////////////////////////////////////
	// Register logic

	//Combinatorial readback
	always_comb begin

		apb.pready	= apb.psel && apb.penable;
		apb.prdata	= 0;
		apb.pslverr	= 0;

		if(apb.pready) begin

			//Reject bogus register IDs
			if( (port_id >= 24) || (reg_id >= REG_MAX) )
				apb.pslverr	= 1;

			//Valid register path
			else begin

				//read
				if(!apb.pwrite) begin

					case(reg_id)
						REG_VLAN_CFG: begin
							apb.prdata[31]		= port_drop_tagged[port_id];
							apb.prdata[30]		= port_drop_untagged[port_id];
							apb.prdata[11:0]	= port_vlan[port_id];
						end

						default:		apb.pslverr	= 1;
					endcase

				end

				//writes: nothing needed, we already validated the register ID

			end

		end
	end

	always_ff @(posedge apb.pclk or negedge apb.preset_n) begin

		//Reset
		if(!apb.preset_n) begin
			for(integer i=0; i<24; i=i+1) begin
				port_vlan[i]			<= 0;
				port_drop_tagged[i]		<= 0;
				port_drop_untagged[i]	<= 0;
			end
		end

		//Normal path
		else begin

			if(apb.pready && apb.pwrite) begin

				case(reg_id)

					REG_VLAN_CFG: begin
						port_drop_tagged[port_id]	<= apb.prdata[31];
						port_drop_untagged[port_id]	<= apb.prdata[30];
						port_vlan[port_id]			<= apb.prdata[11:0];
					end

					default: begin
					end
				endcase

			end

		end

	end
endmodule

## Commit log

2024-12-09 Initial schematic with power supply and supervisor MCU
    [linecard.kicad_pcb, linecard.kicad_sch, psu.kicad_sch]
2024-12-11 Hopefully finished first PHY
    [linecard.kicad_sch, phy0.kicad_sch, phy0_mdi.kicad_sch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]
2024-12-11 Finished initial schematic of line card
    [linecard.kicad_sch, phy0_mdi.kicad_sch, phy0_pwr.kicad_sch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]
2024-12-11 Added heatsink, some silkscreen logos, mounting holes, and ground clips
    [linecard.kicad_sch, phy0.kicad_sch, phy1.kicad_sch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]
2024-12-12 Finished initial schematic review
    [linecard.kicad_pcb, linecard.kicad_sch, phy0.kicad_sch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]
2024-12-13 Began layout of first few ports and left VSC8512
    [linecard.kicad_pcb, linecard.kicad_sch, phy0.kicad_sch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]
2024-12-13 Update waiting for new part from vendor
    [linecard.kicad_pcb, phy0_mdi.kicad_sch]
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2024-12-14 COntinued routing baseT pairs on left PHY
    [linecard.kicad_pcb, linecard.kicad_sch, phy0.kicad_sch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]
2024-12-14 Left half getting close to finished
    [linecard.kicad_pcb, phy0.kicad_sch]
2024-12-14 Finished routing LEDs to left PHY
    [linecard.kicad_pcb]
2024-12-14 Continued routing left PHY, put right PHY + heatsink in approximately final position
    [linecard.kicad_pcb, phy0.kicad_sch]
2024-12-14 Finished routing of left PHY
    [linecard.kicad_pcb, linecard.kicad_sch, phy0.kicad_sch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]
2024-12-15 Preliminary placement of ESD diodes for right PHY
    [linecard.kicad_pcb, linecard.kicad_sch]
2024-12-16 Began routing right side VSC8512
    [linecard.kicad_pcb]
2024-12-16 Continued routing right hand PHY
    [linecard.kicad_pcb]
2024-12-16 Continued routing right VSC8512
    [linecard.kicad_pcb, linecard.kicad_sch, phy0.kicad_sch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]
2024-12-16 Continued routing right PHY power. 834 unrouted.
    [linecard.kicad_pcb]
2024-12-16 Continued routing right PHY. 644 unrouted.
    [linecard.kicad_pcb]
2024-12-17 576 unrouted. More decoupling and baseT work on right side PHY. Started LED fanout.
    [linecard.kicad_pcb, phy1_mdi.kicad_sch]
2024-12-17 Initial skeleton of PDU
    [pdu.kicad_pcb, pdu.kicad_sch]
2024-12-17 Began work on line card power supply
    [linecard.kicad_pcb]
2024-12-17 Continued routing power supply
    [linecard.kicad_pcb]
2024-12-17 Continued power supply routing
    [linecard.kicad_pcb, linecard.kicad_sch, pdu.kicad_sch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]
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2024-12-19 Continued tying up loose ends on routing of left side and supervisor
    [linecard.kicad_sch, phy0.kicad_sch, phy0_mdi.kicad_sch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]
2024-12-19 Added planes, more LED signals, etc
    [phy1.kicad_sch, psu.kicad_sch]
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2024-12-19 Continued power routing on right PHY
    [pdu.kicad_sch, psu.kicad_sch]
2024-12-19 Continued routing right PHY
    [linecard.kicad_sch, phy0.kicad_sch, phy0_mdi.kicad_sch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]
2024-12-19 Updating file: linecard.kicad_pcb with current fully routed design
    [linecard.kicad_sch]
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2024-12-30 Initial version of PDU board is done, ready for review
    [pdu.kicad_pcb, pdu.kicad_sch]
2024-12-30 Finished PDU design, ready for fab
    [pdu.kicad_pcb]
2025-01-11 Initial schematic for lcbringup
    [arf6.kicad_sch, fpgasupport.kicad_sch, lcbringup.kicad_pcb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]
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2025-01-16 Continued line card bringup board
    [lcbringup.kicad_pcb, mcu.kicad_sch, mdio.kicad_sch]
2025-01-17 PDU: fixed incorrect I2C address note in schematic
    [pdu.kicad_sch]
2025-01-17 Initial directory structure for line card firmware
    [lcbringup.kicad_pcb]
2025-01-19 Continued lcbringup layout on ARF6 area
    [arf6.kicad_sch, fpgasupport.kicad_sch, lcbringup.kicad_pcb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]
2025-01-20 Conitnued lcbringup layout, power supply is now floorplanned
    [fpgasupport.kicad_sch, lcbringup.kicad_pcb, lcbringup.kicad_sch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]
2025-01-21 Finished initial lcbringup test board, ready for review
    [lcbringup.kicad_pcb, mcu.kicad_sch]
2025-01-21 Finished lcbringup, ready to order
    [arf6.kicad_sch, fpgasupport.kicad_sch, lcbringup.kicad_pcb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]
2025-05-12 Added software workaround for line card LED1 errata
    [phy0_mdi.kicad_sch, phy1_mdi.kicad_sch]
2025-05-20 Line card: fixed typo in component value and alternate pinmux mode
    [linecard.kicad_sch, phy0.kicad_sch, phy0_mdi.kicad_sch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]
2025-05-24 More work on LineCardInputBuffering, fixed some bugs
    [LineCardFIFOReader.sv, LineCardInputBuffering.sv]
2025-05-25 Fixed more bugs, now seems to be working for BPDUs
    [LineCardFIFOReader.sv, LineCardInputBuffering.sv]
2025-05-27 Added FIFO stuck detection while chasing CDC timing issues
    [LineCardInputBuffering.sv]
2025-05-27 Fixed bug causing extra beat with TLAST set and TSTRB=0 at end of a frame
    [LineCardFIFOReader.sv]
2025-05-28 Added canStartForwarding gate to prevent trying to forward a new frame in some situations while the previous frame was still busy
    [LineCardFIFOReader.sv]
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2025-05-31 Initial versino of dual-sfp28 is fully routed and ready for review
    [dual-sfp28.kicad_pcb, dual-sfp28.kicad_sch]
2025-06-01 Updated dual-sfp28 board with final config for fab
    [dual-sfp28.kicad_pcb]
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2025-06-02 First iteration of main board PCB schematic is now passing ERC
    [fpgasupport.kicad_sch, linecards.kicad_sch, mcu.kicad_sch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]
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2025-06-02 Added footprints and created initial skeleton of layout
    [fpgasupport.kicad_sch, linecards.kicad_sch, mcu.kicad_sch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]
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2025-06-03 Initial power routing of MCU, breakout for FMC signals on FPGA
    [mcu.kicad_sch, switch-engine.kicad_pcb]
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2025-06-06 Continued layout of MCU area, added cutout for fan
    [fpgasupport.kicad_sch, linecards.kicad_sch, mcu.kicad_sch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]
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2025-06-07 Continued routing main MCU and FPGA support parts, hooked up part of boot flash
    [fpgasupport.kicad_sch, linecards.kicad_sch, mcu.kicad_sch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]
2025-06-07 Routing cleanup around FMC, still needs a lot more
    [mcu.kicad_sch, switch-engine.kicad_pcb]
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2025-06-09 Rerouted FMC to not need any mid-span vias
    [mcu.kicad_sch, switch-engine.kicad_pcb]
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2025-06-12 Continued right side layout, basically everything done except power supply
    [psu.kicad_sch, switch-engine.kicad_pcb]
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2025-06-13 Updating file: switch-engine.kicad_pcb with current completely routed design
    [psu.kicad_sch]
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2026-08-09 Line card: fixed shunt resistors incorrectly marked as being PTH
